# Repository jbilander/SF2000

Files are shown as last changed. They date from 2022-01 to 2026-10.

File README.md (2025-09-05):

# SF2000
Spitfire 2000, A low-end 42 MHz Amiga Accelerator based on the Motorola 68SEC000 CPU

***

This is WORK IN PROGRESS, a DIY hobby project. If you are going to make and sell boards you are also the one doing the customer support.

***

The firmware for this board is in a separate repository available here: <br />
https://github.com/jbilander/SF2000-FW
<br />

***

Revision 1B
<br />
<a href="images/SF2000_pic1.png">
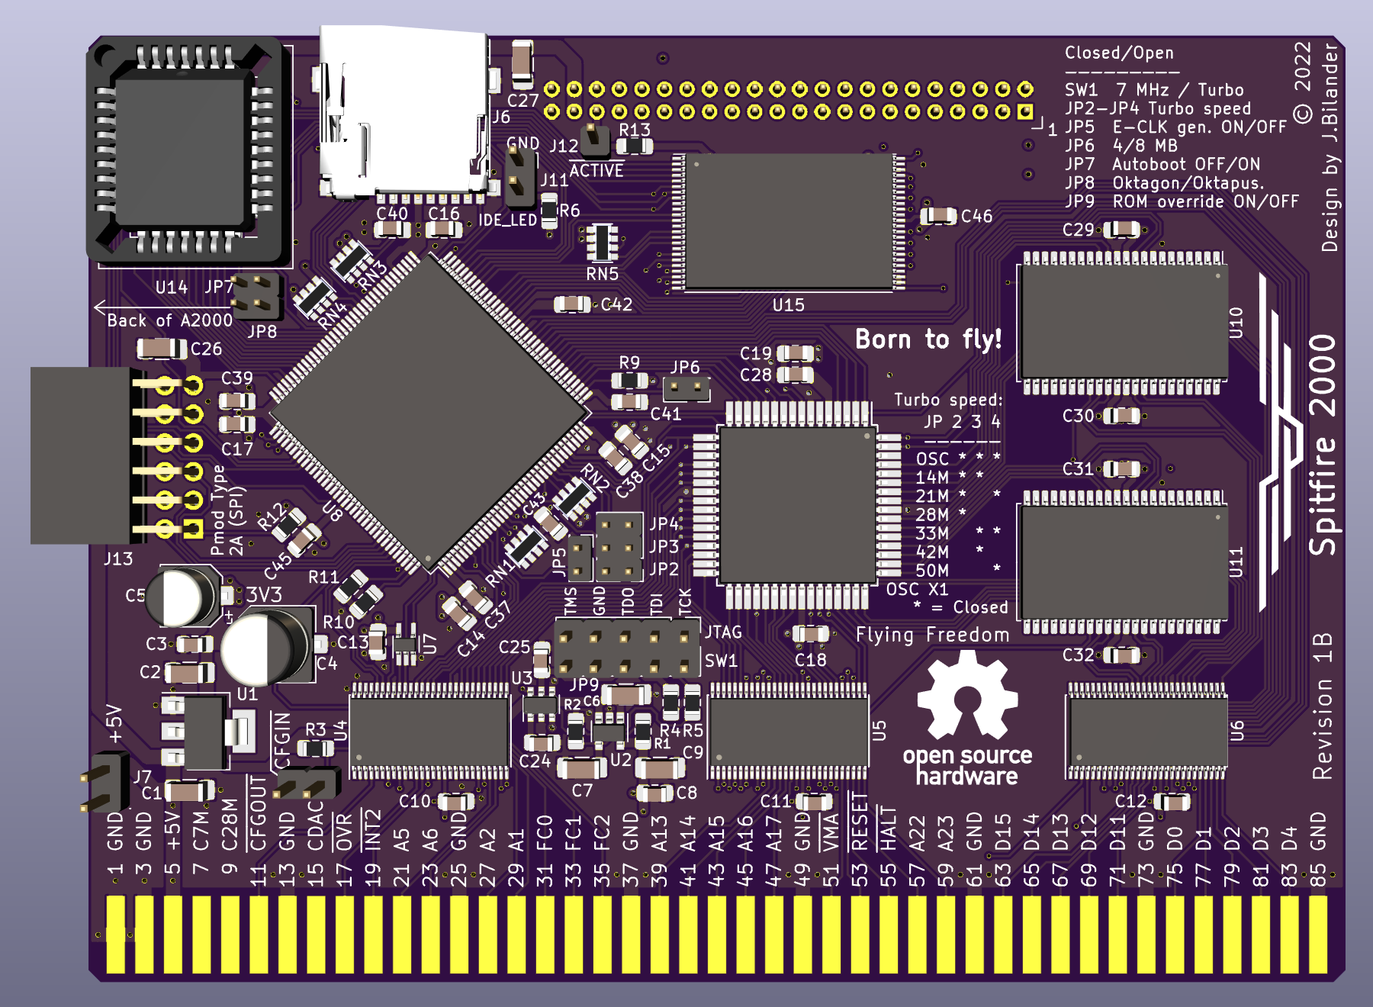
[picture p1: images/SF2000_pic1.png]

</a>
<a href="images/SF2000_pic2.png">
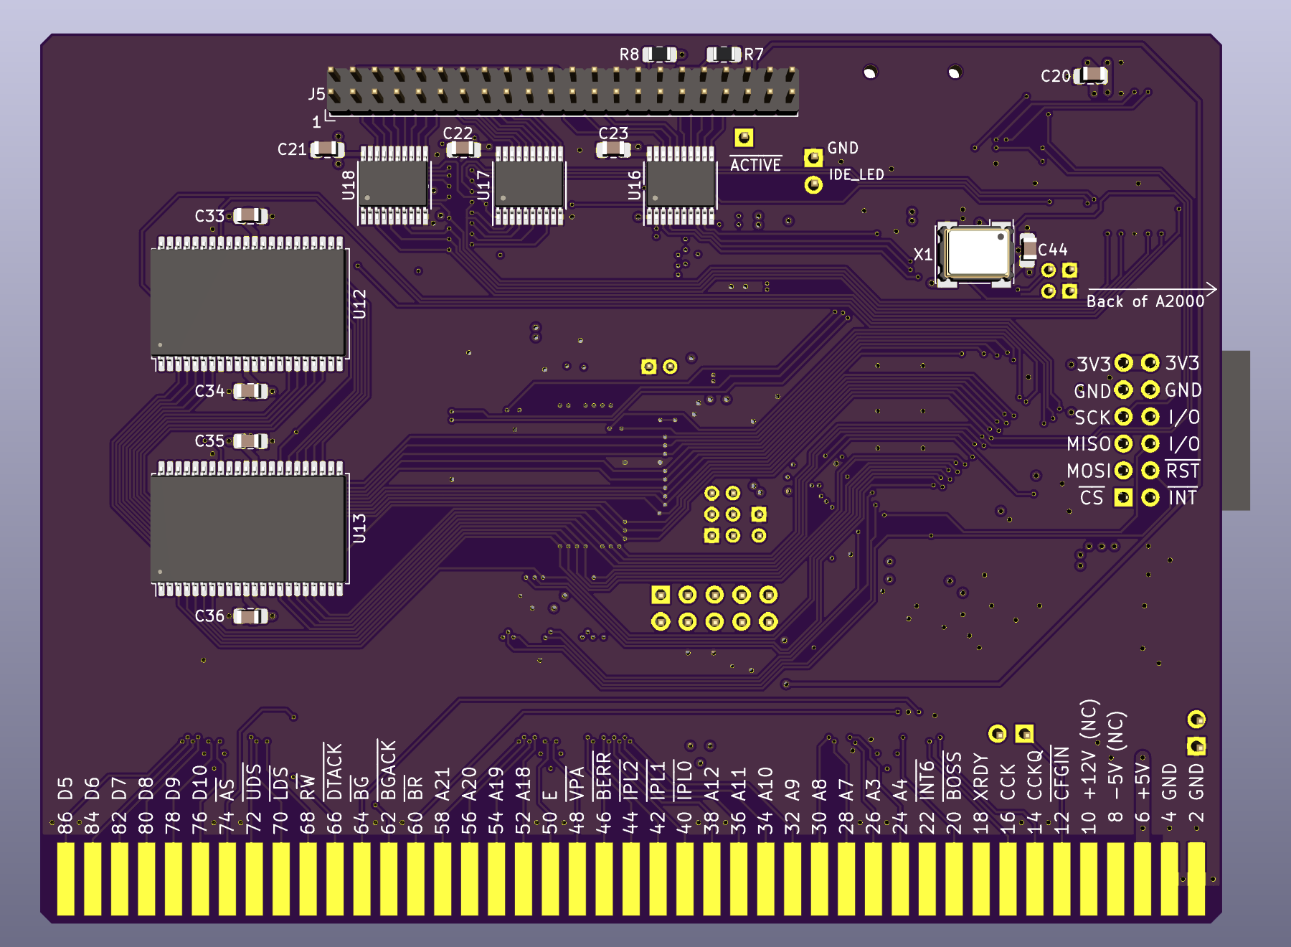
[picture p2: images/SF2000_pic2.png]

</a>

***

<a href="images/SF2000_pic3.jpg">
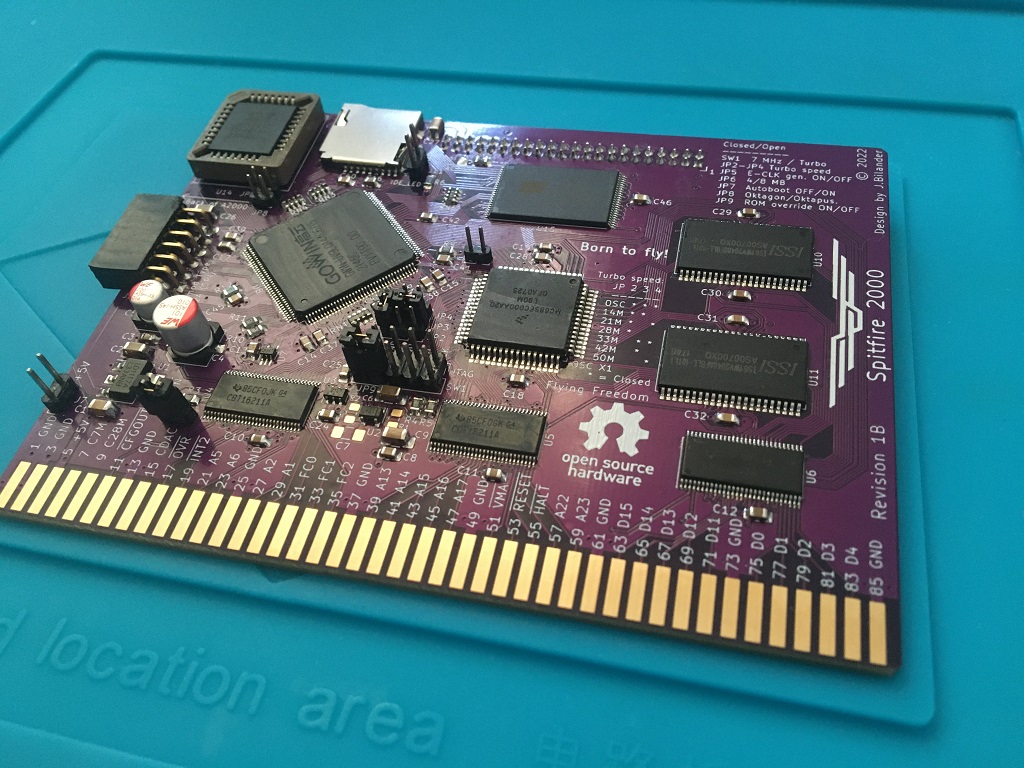
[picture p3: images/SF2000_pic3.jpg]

</a>
<a href="images/SF2000_pic4.jpg">
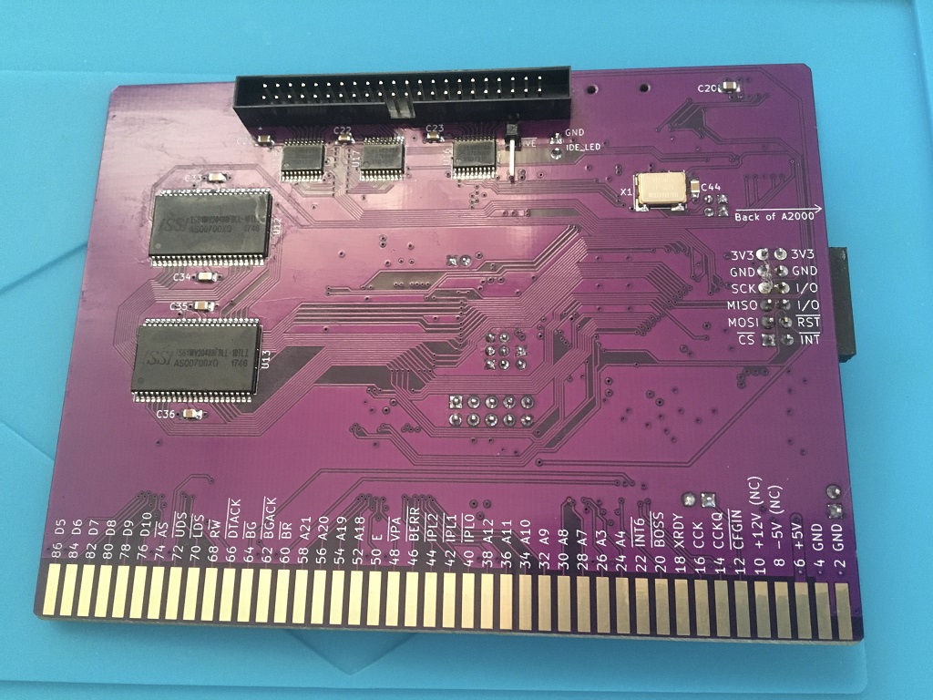
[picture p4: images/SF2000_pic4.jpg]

</a>

***

BOM Rev. 2B
---------
Designator  | Name/Value   | Package | Notes
-|-|-|-|
U1 | Voltage Regulator 3.3V, <br /> LM1117-3.3 or <br /> AMS1117-3.3 | SOT-223 | 3.3V 1A Low Drop-Out (LDO) Linear Voltage regulator
U2 | Voltage Regulator 4.3V, ABLIC S-1132B43-M5T1U or TPS73643DBVR | SOT-23-5 | 4.3V LDO Linear Voltage Regulator<br />[S-1132B43-M5T1U](https://www.digikey.com/en/products/detail/ablic-inc/S-1132B43-M5T1U/6112740)
U3 | Voltage Regulator 1.2V, TLV73312PDBVR | SOT-23-5 | 1.2V LDO Linear Voltage Regulator<br />[TLV73312PDBVR](https://www.digikey.com/en/products/detail/texas-instruments/TLV73312PDBVR/5022371)
U4,U5,U6 | Digital Bus Switch ICs 24-Bit FET, SN74CBT16211CDGGR or SN74CBT16811CDGGR | TSSOP-56 | FET Level-shifter <br />[SN74CBT16211CDGGR](https://www.digikey.com/en/products/detail/texas-instruments/SN74CBT16211CDGGR/864169) or <br />[SN74CBT16811CDGGR](https://www.digikey.com/en/products/detail/texas-instruments/sn74cbt16811cdggr/864186)
U7 | Dual XOR gate SN74LVC2G86DCUR | VSSOP-8_2.3x2mm_P0.5mm | Generates 7 MHz CLK from ~(CCK XOR CCKQ) <br />[SN74LVC2G86DCUR](https://www.digikey.com/en/products/detail/texas-instruments/sn74lvc2g86dcur/484697)
U8 | Efinix Trion T8 FPGA T8Q144C3 | LQFP-144_20x20mm_P0.5mm | FPGA - Field Programmable Gate Array, 7384 LE, 97 I/O <br />[T8Q144C3](https://www.digikey.com/en/products/detail/efinix-inc/t8q144c3/11591370)
U9 | W25Q16JVSNIQ 16 Mbit SPI NOR Flash memory | SOIC-8_3.9x4.9mm_P1.27mm (150-mil Narrow JEDEC SOIC) | [W25Q16JVSNIQ](https://www.digikey.com/en/products/detail/winbond-electronics/w25q16jvsniq/6193768) or [AT25SF161B-SSHD-T](https://www.digikey.com/en/products/detail/renesas-electronics-corporation/AT25SF161B-SSHD-T/14549318)
U10 | Motorola CPU MC68SEC000AA20 20MHz | QFP-64_14x14mm_Pitch0.8mm | [MC68SEC000AA20](https://shop.tvsat.com.pl/en_GB/searchquery/68sec000/1/phot/5?url=68sec000)
U11 | SST39LF802C-55-4C-EKE or SST39LF800A-55-4C-EKE | TSOP-I-48_18.4x12mm_P0.5mm | NOR Flash 3.0 to 3.6V 8Mbit Multi-Purpose Flash (for Kickstart) <br />[S39LF802C554CEKE](https://www.mouser.com/ProductDetail/579-S39LF802C554CEKE)<br />[S39LF800A554CEKE](https://www.digikey.com/en/products/detail/microchip-technology/SST39LF800A-55-4C-EKE/2297824)
U12 | 74AHCT14PW, Six Channel Schmitt Trigger Inverter | TSSOP-14_4.4x5mm_P0.65mm | [74AHCT14PW,118](https://www.digikey.com/en/products/detail/nexperia-usa-inc/74AHCT14PW-118/1229627) or <br />[SN74AHCT14PWR](https://www.digikey.com/en/products/detail/texas-instruments/SN74AHCT14PWR/276754)
U13 | NOR Flash SST39LF040-55-4C-NHE-T | PLCC-32 | NOR Flash 3.0 to 3.6V <br />[SST39LF040554CN](https://www.digikey.com/en/products/detail/microchip-technology/sst39lf040-55-4c-nhe-t/4080132) <br /> (or 39LF020, 39LF010)
U14,U15 | SRAM ISSI IS61WV20488FBLL-10TLI  | TSOP-44 | First 4 MB SRAM <br />High-Speed, Async, 2Mbx8, 10ns, 2.4v-3.6v, 44 Pin TSOP II, RoHS <br />[IS61WV20488FBLL-10TLI](https://www.mouser.com/ProductDetail/870-61W20488FBLL10TI)
U16,U17 | SRAM ISSI IS61WV20488FBLL-10TLI  | TSOP-44 | Second 4 MB (Optional) --"-- <br />
J1 | Goldfingers on PCB | ENIG | Order PCB with Goldfingers, ENIG and 45 degrees chamfered edge (or chamfer the edge yourself with a file)
J2 | CFGIN-header Two-Pin Header | 2.54mm pitch | Put a Jumper shunt here to activate autoconfig, or a CONFIGOUT-wire from other device to the right (pin 2) in this header.  
J3 | JTAG-header   | Dual row 2.54mm (2 x 5) Pin Male Header | 
J4 | JP-header JP2 | 2.00mm (2 x 1) Pin Male Header | Generate E-CLK (if internal 68k is removed from socket)
J5 | JP-header JP3 | 2.00mm (2 x 1) Pin Male Header | Rom overlay jumper
J6 | JP-header JP4 | 2.00mm (2 x 1) Pin Male Header | 4/8 MB SRAM Config
J7 | VCC/GND Two-Pin Header | 2.54mm pitch | VIN +5V <br /> used when programming FPGA standalone (card not installed in the Amiga). Be careful with orientation, check polarity BEFORE plugging-in a phone charger or similar here.
J8 | Sunrom Micro SD Card Holder | 9-pin Micro SD card slot connector | [Sunrom Micro-SD card holder](https://www.aliexpress.com/item/32802051702.html)
J9 | SD_LED header, Two-Pin Header | 2.54mm pitch | Driven by U12 inverter buffer when /SD_CS is being asserted. Connect to here in order to drive an external HDD-LED
J10 | SD_ACTIVE low signal, Right angle Single-Pin Header | 0.64 mm square pin angled | Driven by U12 inverter buffer when /SD_CS is being asserted. Connect to here in order to drive a [LED-board](https://github.com/jbilander/A500_IDE_LED_board) (Active low +5V-signal)
J11 | Rom-bank selector | 2.00mm (2 x 1) Pin Male Header | Select first or second bank, address line A15 (pin 3) on U13 (SST39LF040)
J12 | CLOCKPORT-header | 2.00mm 22-Pin (2x11) Pin Male Header | Caution: This header is +5V levels. Be careful with orientation.
J13 | JP-header JP1 | 2.54mm (2 x 1) Pin Male Header | 7 MHz / Turbo selector
X1 | Crystal Oscillator 20 MHz | Oscillator_7.0x5.0mm |
R1 | 33 Ω Resistor | 0805 | Damping resistor for 20 MHz clock-signal coming from X1 oscillator
R2 | 33 Ω Resistor | 0805 | Damping resistor for 7 MHz clock-signal coming from U7 (SN74LVC2G86DCUR)
R3 | 33 Ω Resistor | 0805 | Damping resistor for CLKCPU clock-signal coming from FPGA pin 33
R4 | ~220 Ω Resistor | 0805 | Series resistor for SD_LED header J9, adjust R-value to your type of LED and preferred brightness
R5 | 10k Ω Resistor | 0805 | Pull-up resistor for /FLASH_OE to 3V3
R6 | 10k Ω Resistor | 0805 | Pull-up resistor for JP2 to 3V3
R7 | 10k Ω Resistor | 0805 | Pull-up resistor for /CFGIN to 5V
R8 | 100k Ω Resistor | 0805 | Pull-up resistor for CRESET_N to 3V3
RN1-RN6 | Resistor pack 10k Ω (CAY16-103J4LF) | 1206 | [CAY16-103J4LF](https://www.digikey.com/en/products/detail/bourns-inc/cay16-103j4lf/431579)
C1 | Polarized Electrolytic Capacitor 100uF | CP_Elec_6.3x7.7 mm | [Wurth SMD WCAP-AS5H 100uF](https://www.digikey.com/en/products/detail/w%C3%BCrth-elektronik/865230245004/5727885)
C2 | Polarized Electrolytic Capacitor 22uF | CP_Elec_5x5.8 mm | [Wurth SMD WCAP-AS5H 22uF](https://www.digikey.com/en/products/detail/w%C3%BCrth-elektronik/865230342002/5727846)
C3-C7 | Ceramic Capacitor 10uF | 1206 |
C8 | Ceramic Capacitor 2.2uF | 1206 |
C9 | Ceramic Capacitor 0.47uF = 470 nF | 1206 |
C10-C39 | Ceramic Capacitor 0.1uF = 100nF | 0805 | 
C40-C54 | Capacitor 0.01uF = 10nF | 0805 |

***

BOM Rev. 1B
---------
Designator  | Name/Value   | Package | Notes
-|-|-|-|
U1 | Voltage Regulator 3.3V, <br /> LM1117-3.3 or <br /> AMS1117-3.3 | SOT-223 | 3.3V 1A Low Drop-Out (LDO) Voltage regulator. https://www.aliexpress.com/item/32869037691.html
U2 | Voltage Regulator 4.3V, TPS73643DBVR or <br /> ABLIC S-1200B43-M5T1U or <br /> MIC5205YM5-TR ADJ (with R1,R2 and C7 populated) | SOT-23-5 | 4.3V LDO Voltage Regulator<br />* [TPS73643DBVR](https://www.mouser.com/ProductDetail/595-TPS73643DBVR) <br />* [S-1132B43-M5T1U](https://www.mouser.com/ProductDetail/628-S-1132B43-M5T1G) <br />* [MIC5205YM5-TR](https://www.mouser.com/ProductDetail/Microchip-Technology-Atmel/MIC5205YM5-TR?qs=U6T8BxXiZAUCsfGqlmZYIw%3D%3D) (Adjustable, populate R1,R2,C7)
U3 | Inverter Schmitt Trigger 74LVC2G14GV,125 | TSOP-6/SOT457/SC-74 | * [LVC2G14GV125](https://www.mouser.com/ProductDetail/771-LVC2G14GV125)
U4,U5,U6 | Digital Bus Switch ICs 24-Bit FET, SN74CBT16211ADGGR | TSSOP-56 | FET Level-shifter <br /> * [SN74CBT16211ADGGR](https://www.mouser.com/ProductDetail/595-SNCBT16211ADGGR) <br /> * [SN74CBT16811CDGG](https://www.mouser.com/ProductDetail/595-SN74CBT16811CDGG)
U7 | XNOR gate w/ Schmitt Trigger SN74AUP1T87DCKR |TSSOP-5/SC-70-5/SOT-353-1 | Generates 7 MHz CLK from CCK XNOR CCKQ <br /> * [SN74AUP1T87DCKR](https://www.mouser.com/ProductDetail/595-SN74AUP1T87DCKR)
U8 | Gowin FPGA GW1N-UV9LQ144C6/I5 | LQFP-144 | FPGA - Field Programmable Gate Array, 8640 LE, 120 I/O <br /> * [GW1N-UV9LQ144C6/I5](https://www.mouser.com/ProductDetail/192-GW1NUV9LQ144C6I5)
U9 | Motorola CPU MC68SEC000AA20 | QFP-64 | MPU 32-bit 20MHz <br /> Contact Eriond to buy a NOS CPU for a reasonable price
U10,U11 | SRAM ISSI IS61WV20488FBLL-10TLI  | TSOP-44 | First 4 MB SRAM <br />High-Speed, Async, 2Mbx8, 10ns, 2.4v-3.6v, 44 Pin TSOP II, RoHS <br /> * [61W20488FBLL10TI](https://eu.mouser.com/ProductDetail/870-61W20488FBLL10TI)
U12,U13 | SRAM ISSI IS61WV20488FBLL-10TLI  | TSOP-44 | Second 4 MB (Optional) --"-- <br />
U14 | NOR Flash SST39LF040-55-4C-NHE-T | PLCC-32 | NOR Flash 3.0 to 3.6V (For Oktagon/Oktapus. IDE-driver) <br /> * [SST39LF040554CN](https://www.mouser.com/ProductDetail/579-SST39LF040554CN) <br /> (or 39LF020, 39LF010)
U15 | SST39LF802C-55-4C-EKE | TSOP-48 | NOR Flash 3.0 to 3.6V 8Mbit Multi-Purpose Flash (for Kickstart) <br /> * [S39LF802C554CEKE](https://www.mouser.com/ProductDetail/579-S39LF802C554CEKE)
U16,U17,U18 | Bus Transceiver 74LVC245APW,118  | TSSOP-20 | * [74LVC245APW-T](https://www.mouser.com/ProductDetail/771-74LVC245APW-T)
J1 | Goldfingers on PCB | ENIG | Order PCB with Goldfingers, ENIG and 45 degrees chamfered edge (or chamfer the edge yourself)
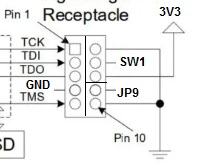
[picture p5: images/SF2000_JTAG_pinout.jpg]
J2 | JTAG-header | Dual row 2.54mm (2 x 5) Pin Male Header Strip | 
J3 | JP-header JP2,JP3,JP4 | Dual row 2.00mm (2 x 3) Pin Male Header Strip | Turbo speed selector
J4 | JP-header JP5 | 2.00mm (2 x 1) Pin Male Header | Generate E-CLK (if internal 68k is removed from socket)
J5 | IDE/ATA-header | 2.00mm 44-Pin (2x22 Pin) Straight Male Shrouded PCB Box header IDC Socket | For A2000: <br /> * [Shrouded header](https://www.aliexpress.com/item/1720053014.html) <br />For A500 internal mount a right angled female header can be used (2x25 and cut down to 2x22): <br /> * [Right Angle Female Connector](https://www.aliexpress.com/item/4001286548060.html)
J6 | Sunrom Micro SD Card Holder | 9-pin Micro SD card slot connector | * [Sunrom Micro-SD card holder](https://www.aliexpress.com/item/32802051702.html)
J7 | VCC/GND Two-Pin Header 2.54mm pitch | 2.54mm pitch | VIN +5V <br /> used when programming FPGA standalone (card not installed in the Amiga). Be careful with orientation, check polarity BEFORE plugging-in a phone charger or similar here.
J8 | JP-header JP6 | 2.00mm (2 x 1) Pin Male Header | 4/8 MB SRAM Config
J9,J10 | JP-header JP7,JP8 | 2.00mm (2 x 2) Pin Male Header | JP7 Autoboot IDE OFF/ON Selector, JP8 Oktagon/Oktapus. IDE-driver Selector
J11 | LED Two-Pin Header 2.54mm pitch | 2.54mm pitch | Driven by U3 inverter buffer when /Active on IDE is being asserted. Connect to here to drive an external HDD-LED
J12 | /Active signal, Single-Pin Header 2.54mm | 2.54mm pitch | /Active signal from IDE. Connect from here to a <br /> * [LED-board](https://github.com/jbilander/A500_IDE_LED_board) 
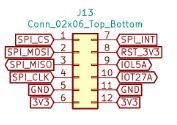
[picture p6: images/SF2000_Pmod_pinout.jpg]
J13 | Pmod Type 2A (SPI) Female header, 12-Pin (2x6) | 2.54mm pitch |  For connecting SPI peripherals. <br /> * [Right-Angled](https://www.aliexpress.com/item/1005003223096006.html) (A2000) or <br /> * [Straight](https://www.aliexpress.com/item/1005003335405213.html) (A500) to not interfere with [RGBtoHDMI-adapter](https://github.com/jbilander/A500_RGBtoHDMI) inside A500
R1 | 1.2k Ω Resistor | 0805 | Feedback resistor, Only populate if U2 is of ADJ-ustable type (e.g. MIC5205YM5-TR)
R2 | 3k Ω Resistor | 0805 | Feedback resistor, Only populate if U2 is of ADJ-ustable type (e.g. MIC5205YM5-TR)
R3 | 10k Ω Resistor | 0805 | Pull-up resistor for /CFGIN (5V-side)
R4 | 10k Ω Resistor | 0805 | Pull-up resistor in RC-debounce circuit
R5 | 10k Ω Resistor | 0805 | Series resistor in RC-debounce circuit
R6 | ~220 Ω Resistor | 0805, 200 mW | Series resistor for IDE-LED header J11, adjust R-value to your type of LED and preferred brightness
R7 | 1k Ω Resistor | 0805 | Pull-down resistor for IDE_IRQ
R8 | 4.7k Ω Resistor | 0805 | Pull-up resistor for IDE_IORDY
R9 | 10k Ω Resistor | 0805 | Pull-up resistor for JP6
R10 | 1k Ω Resistor | 0805 | Pull-down resistor for MODE0 (Gowin FPGA boot/configure from embFlash)
R11 | 1k Ω Resistor | 0805 | Pull-down resistor for MODE1 (Gowin FPGA boot/configure from embFlash)
R12 | 10k Ω Resistor | 0805 | Pull-up resistor for RECONFIG_N (Gowin FPGA) and /SPI_CS (in J13 Pmod-header)
R13 | 10k Ω Resistor | 0805 | Pull-up resistor for /ACTIVE (IDE)
RN1-RN2,RN5 | Resistor pack 10k Ω (CAY16-103J4LF) | 1206 | * [CAY16-103J4LF](https://www.mouser.com/ProductDetail/652-CAY16-103J4LF) Pull-up resistors.
RN3-RN4 | Resistor pack 10k Ω (CAY16-103J4LF) or 4.7k (CAY16-4701F4LF) | 1206 | * [CAY16-4701F4LF](https://www.mouser.com/ProductDetail/652-CAY16A-4701F4LF) Pull-up resistors for SD0-SD3,SD_CD,SD_CMD,JP7,JP8
C1-C2 | Capacitor 10uF | 1206 |
C3 | Capacitor 0.1uF = 100nF | 0805 |
C4 | Polarized Capacitor 100uF | CP_Elec_6.3x7.7 | * [Wurth SMD WCAP-AS5H 100uF](https://www.mouser.com/ProductDetail/710-865230245004)
C5 | Polarized Capacitor 22uF | CP_Elec_5x5.8 | * [Wurth SMD WCAP-AS5H 22uF](https://www.mouser.com/ProductDetail/710-865230342002)
C6 | Capacitor 10uF to 0.22uF | 1206 | Check datasheet for U2 what is suitable here.
C7 | Capacitor 0.33uF = 330nF | 1206 | (Not needed if U2 is TPS73643DBVR, check your U2-datasheet)
C8 | Capacitor 10uF | 1206 |
C9-C25 | Capacitor 0.1uF = 100nF | 0805 | C24 capacitor in RC-debounce circuit
C26-C27 | Capacitor 10uF | 1206 |
C28-C46 | Capacitor 0.01uF = 10nF | 0805 |

***

A SF2000 shared shopping cart with most of the stuff in the list, no 3V3-regulator though and not all birdseed (passives):
https://www.mouser.com/ProjectManager/ProjectDetail.aspx?AccessID=fdb374e26b

***

The FPGA used in this Accelerator board, please note it has to be the Voltage `UV` version because of 3.3V is being used for all VCC/VCCIO on the Accelerator:
<br />
<a href="images/SF2000_FPGA_GW1N-UV9LQ144.png">
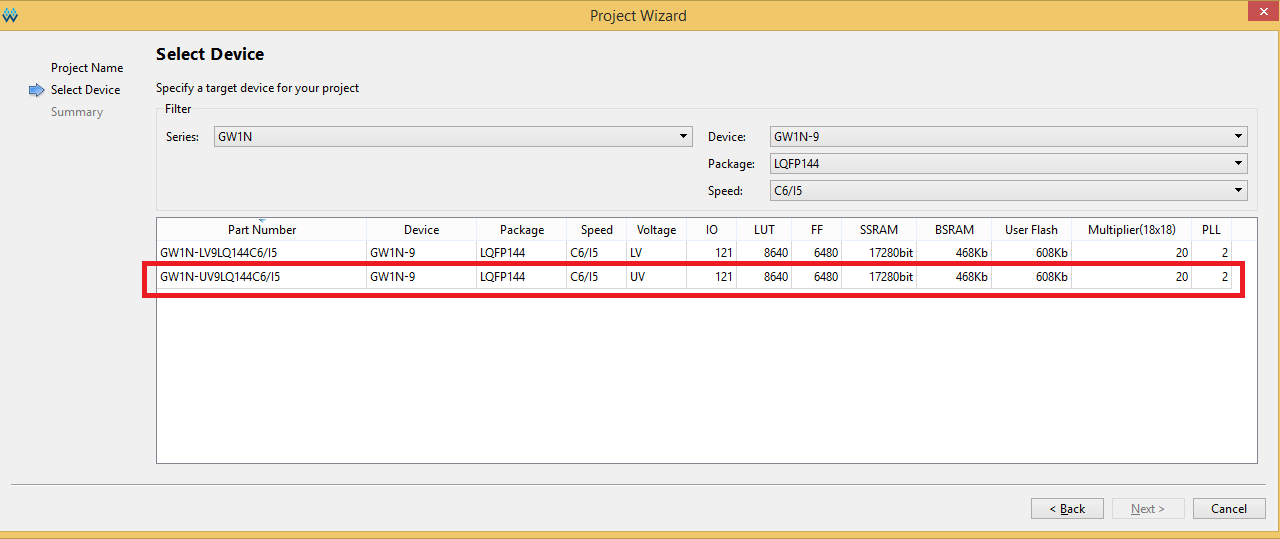
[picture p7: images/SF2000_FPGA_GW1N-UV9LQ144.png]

</a>

***

### Ordering details (JLCPCB):

<a href="images/SF2000_JLCPCB_ordering_pic1.png">
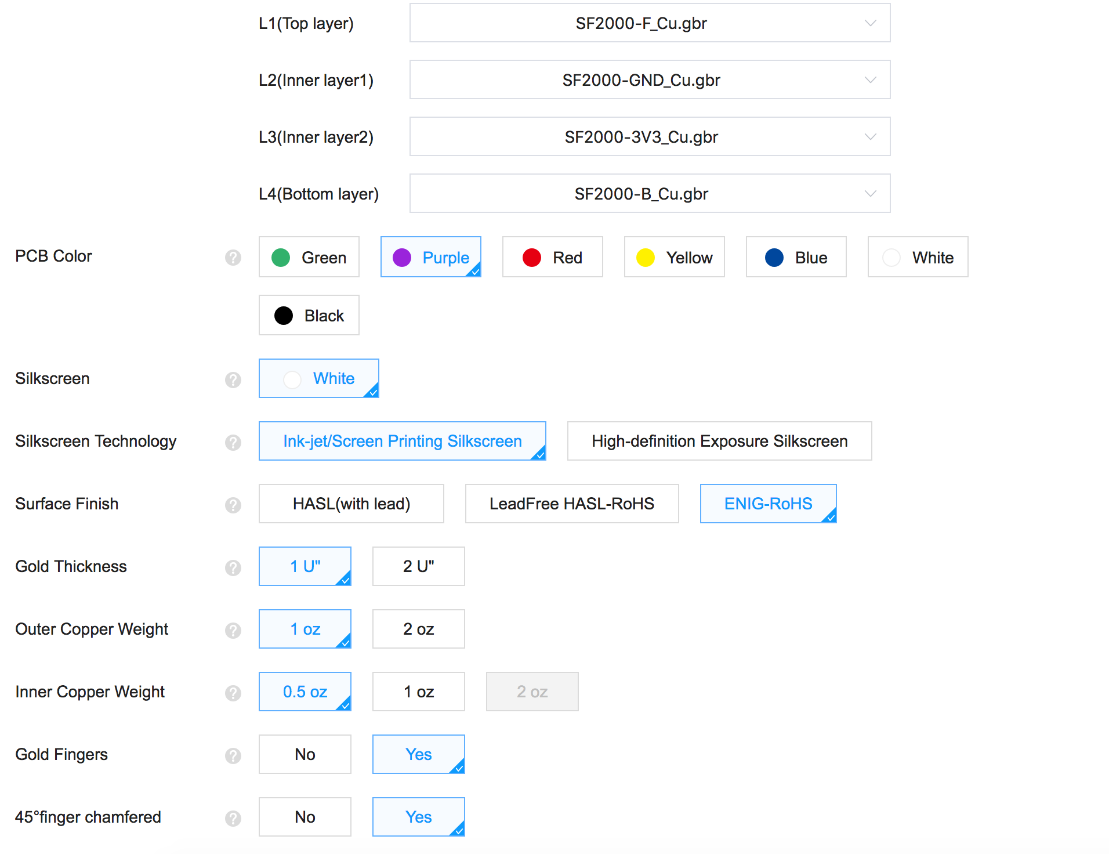
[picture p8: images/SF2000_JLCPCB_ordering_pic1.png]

</a>
<br />
<a href="images/SF2000_JLCPCB_ordering_pic2.png">
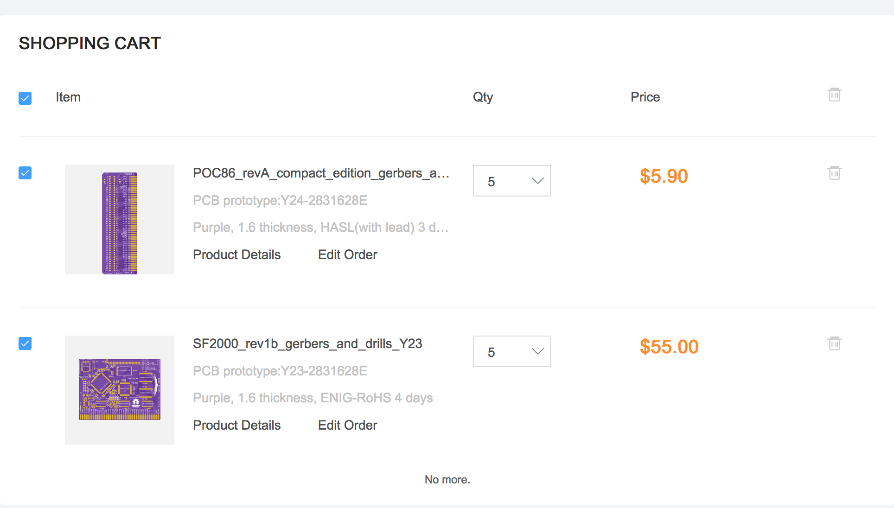
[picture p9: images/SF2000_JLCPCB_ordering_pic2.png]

</a>
<a href="images/SF2000_pic5.png">
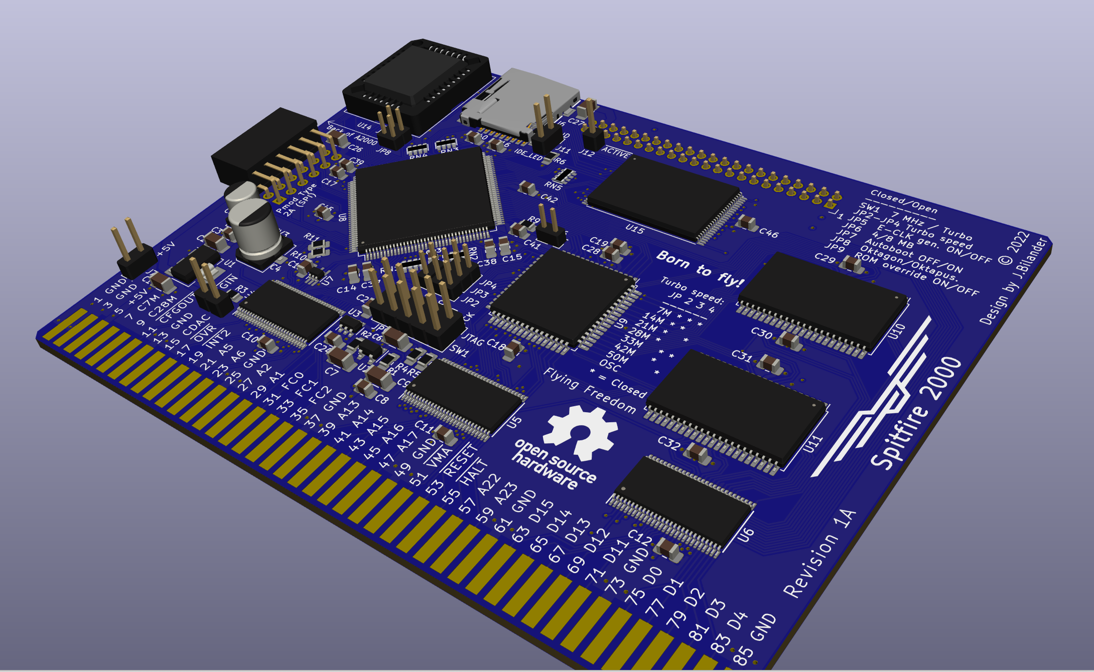
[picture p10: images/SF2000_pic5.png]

</a>

***
### MC68SEC000 

The SF2000 is based on the MC68SEC000 CPU <br />
https://www.nxp.com/docs/en/product-brief/MC68SEC000.pdf <br />
<a href="images/SF2000_pic6.jpg">
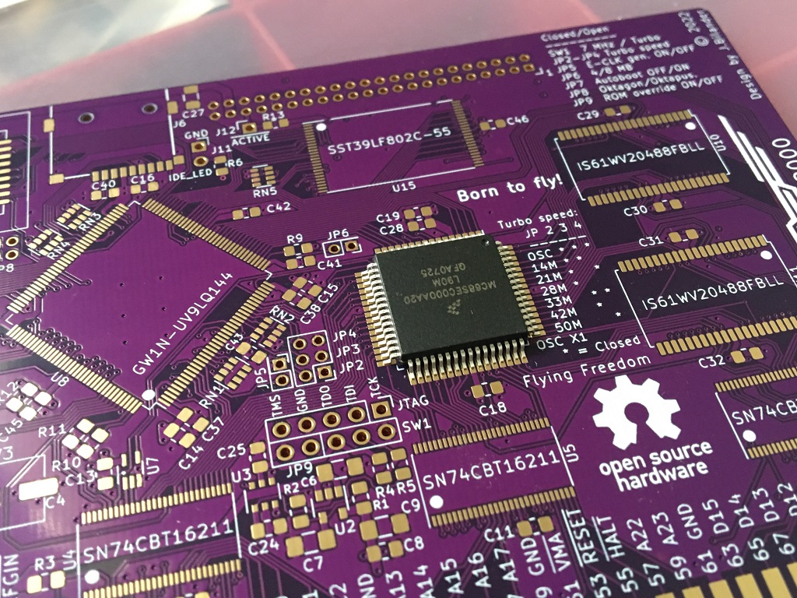
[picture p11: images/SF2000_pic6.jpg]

</a>
<br />
You can contact Eriond, https://github.com/eriond (over at A314 or Retro Tinkering or SUGA (Swedish User Group Amiga) discord) to buy a NOS MC68SEC000 at a reasonable price.

***

### Installing in A500 or A2000:

Internal A500 installation with this adapter: <br />
https://github.com/jbilander/A500_Edge_Expansion_adapter
<br />
<a href="images/SF2000_pic7.jpg">
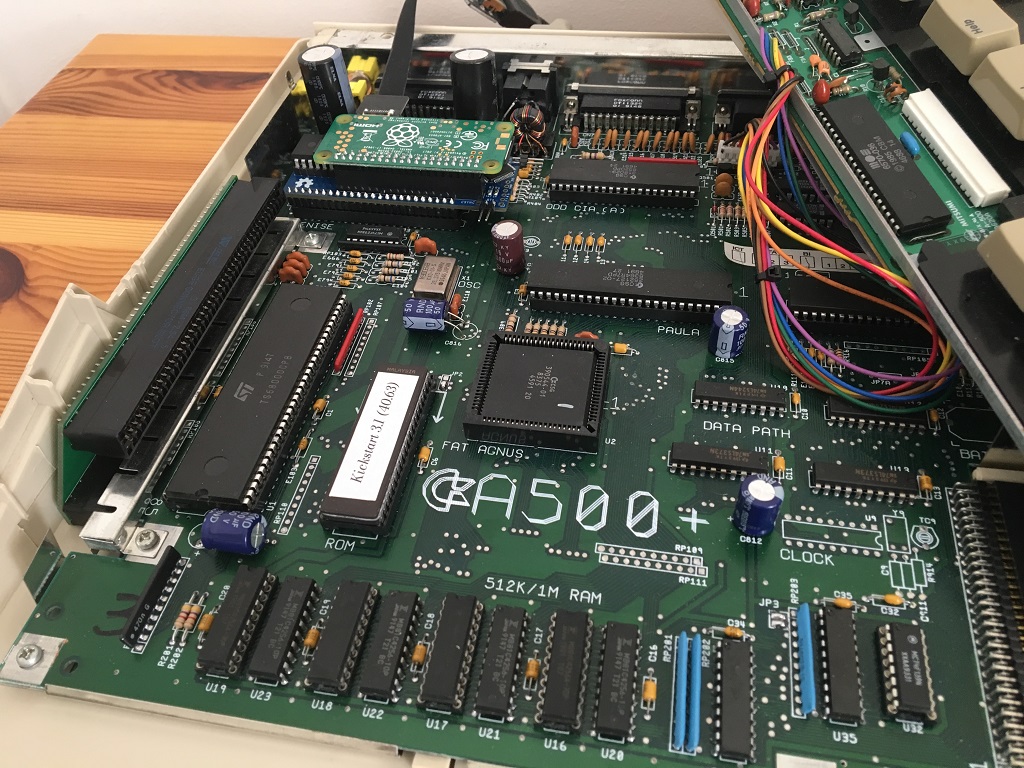
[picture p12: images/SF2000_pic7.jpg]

</a>
<br />
<a href="images/SF2000_pic8.jpg">
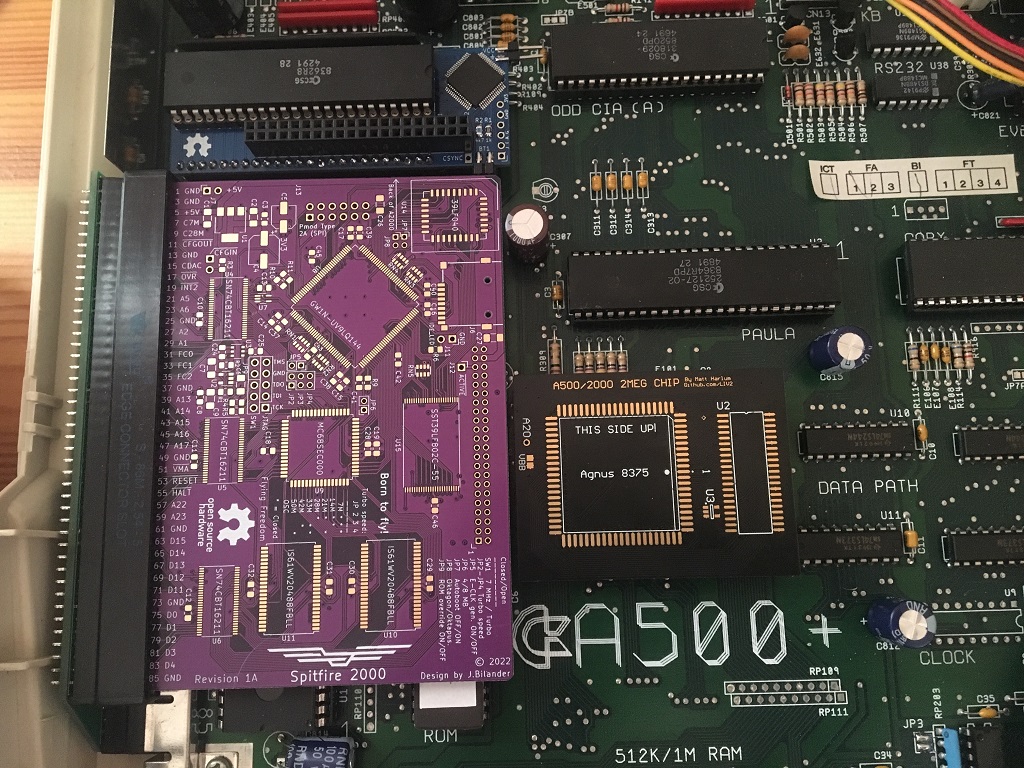
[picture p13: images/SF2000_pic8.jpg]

</a>
<a href="images/SF2000_pic9.jpg">
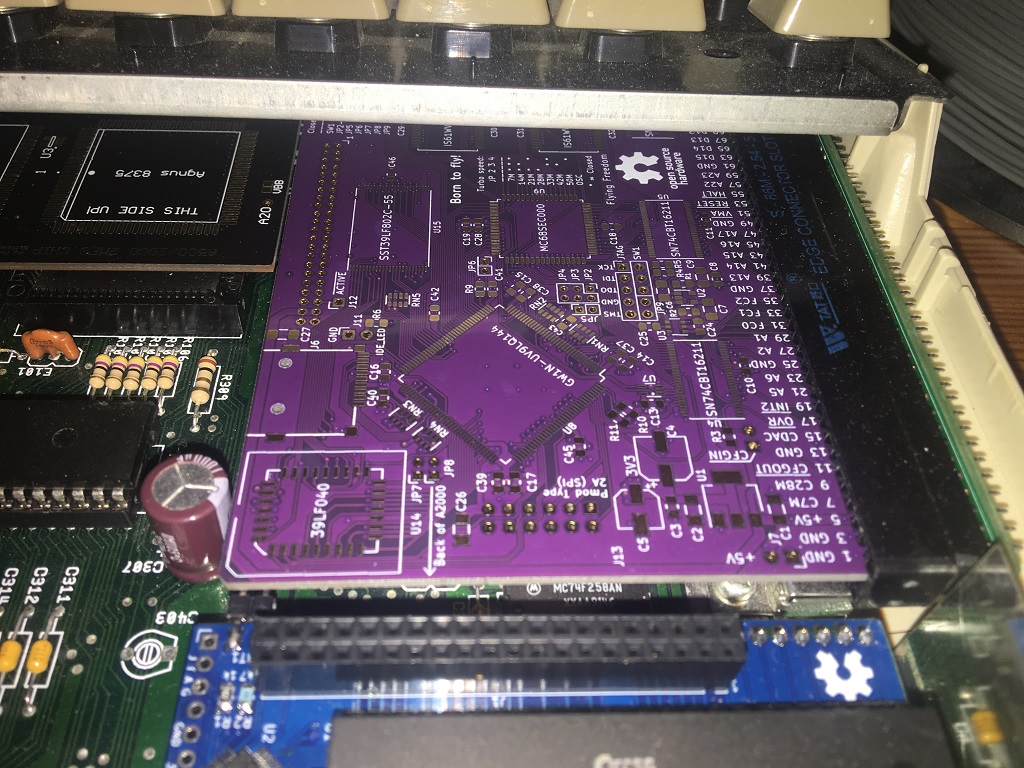
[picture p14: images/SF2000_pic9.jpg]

</a>
<br />
<a href="images/SF2000_pic10.jpg">
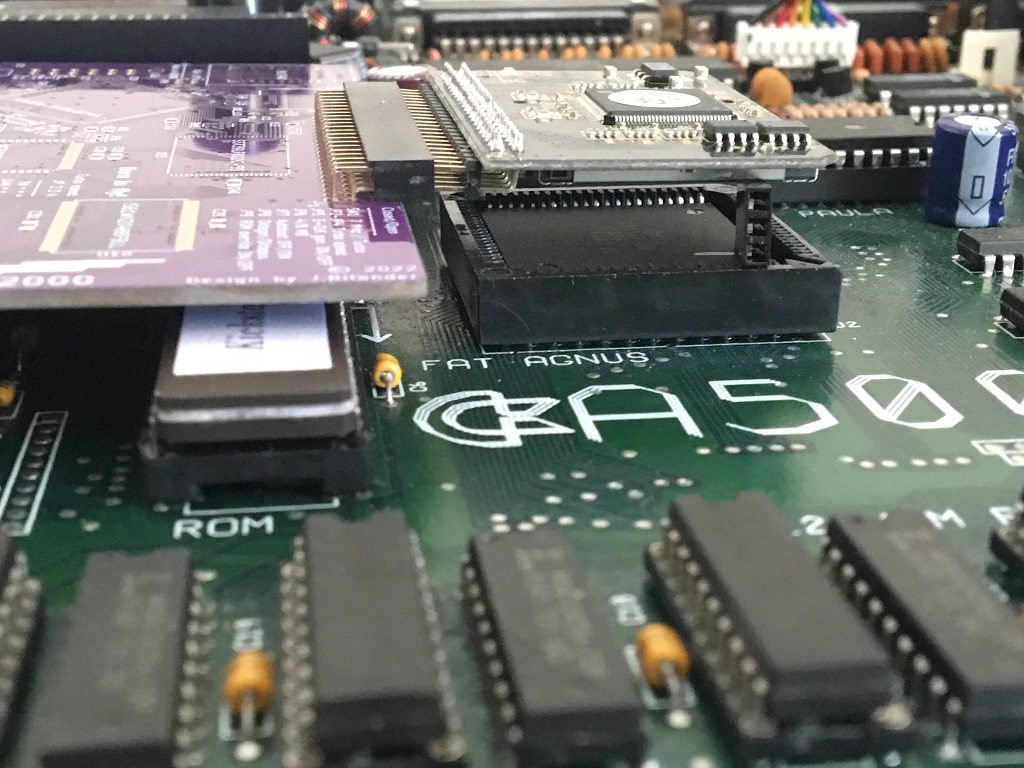
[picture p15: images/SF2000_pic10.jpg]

</a>
<a href="images/SF2000_pic11.jpg">
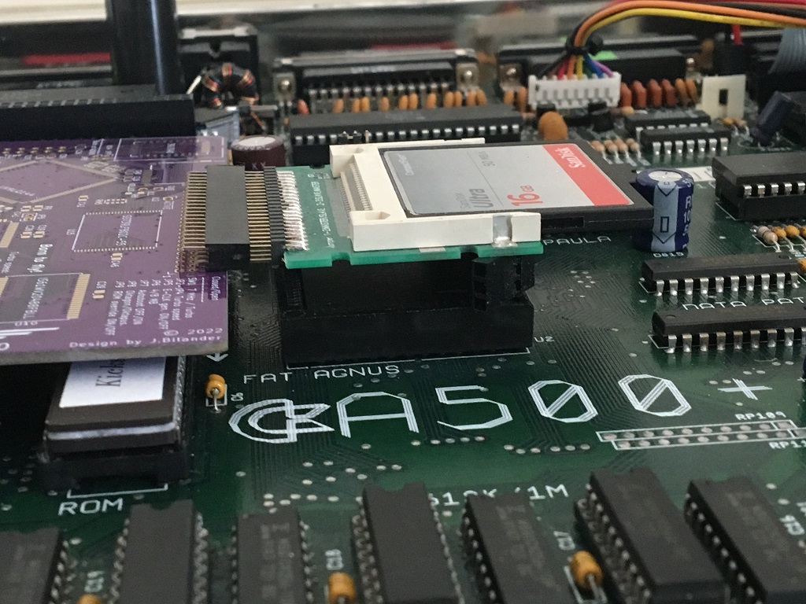
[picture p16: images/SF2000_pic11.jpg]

</a>

External A500 installation with this adapter: <br />
https://github.com/jbilander/POC86
<br />
<a href="images/SF2000_pic12.jpg">
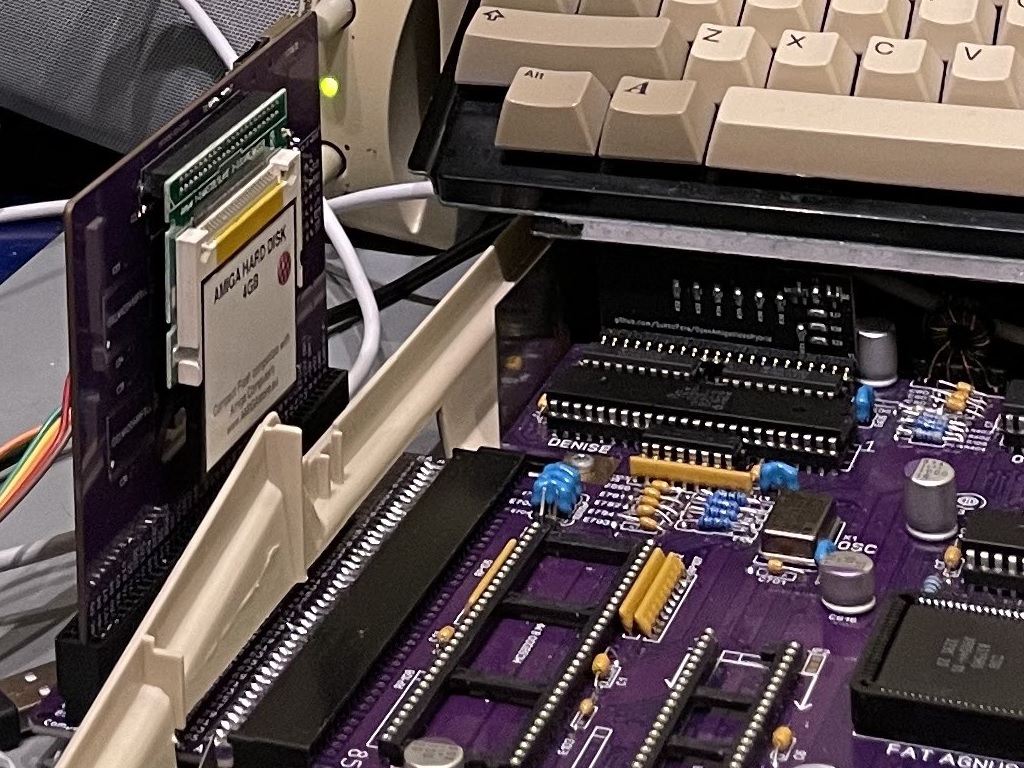
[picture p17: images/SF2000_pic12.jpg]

</a>
<br />
<a href="images/SF2000_pic14.jpg">
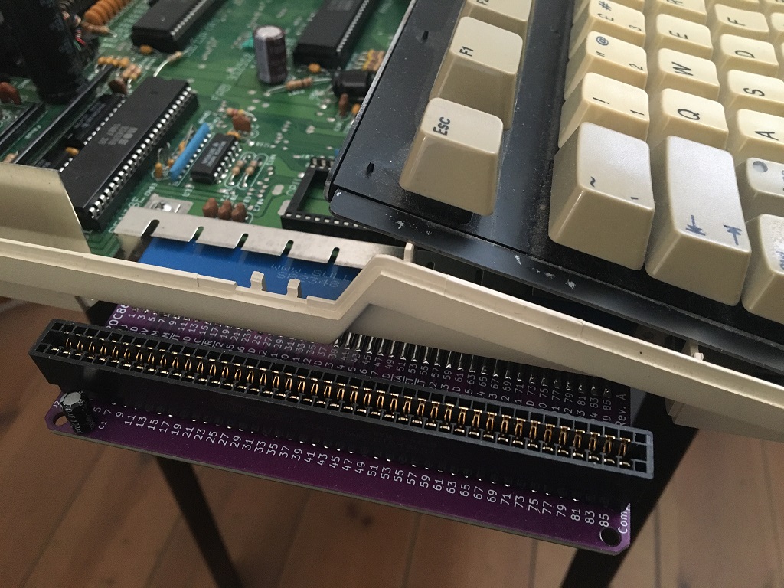
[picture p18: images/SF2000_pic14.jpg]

</a>
<br />
<a href="images/SF2000_pic15.jpg">
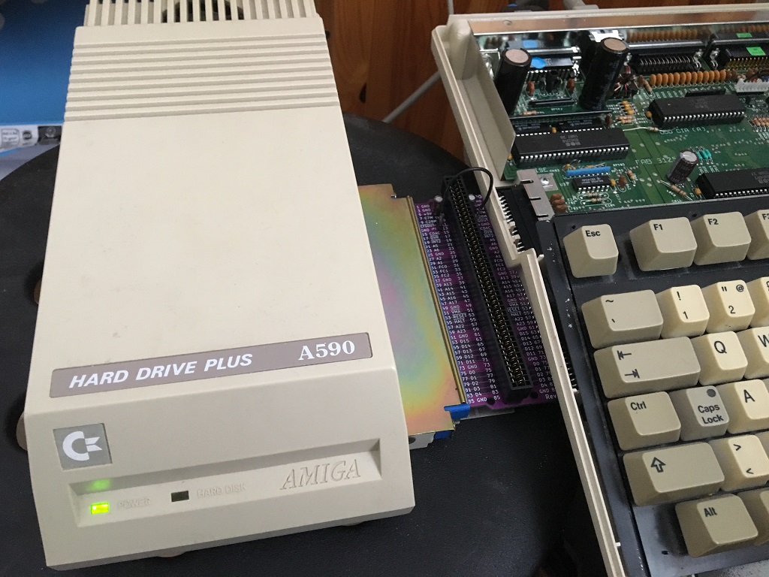
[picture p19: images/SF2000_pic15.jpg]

</a>
<a href="images/SF2000_pic16.jpg">
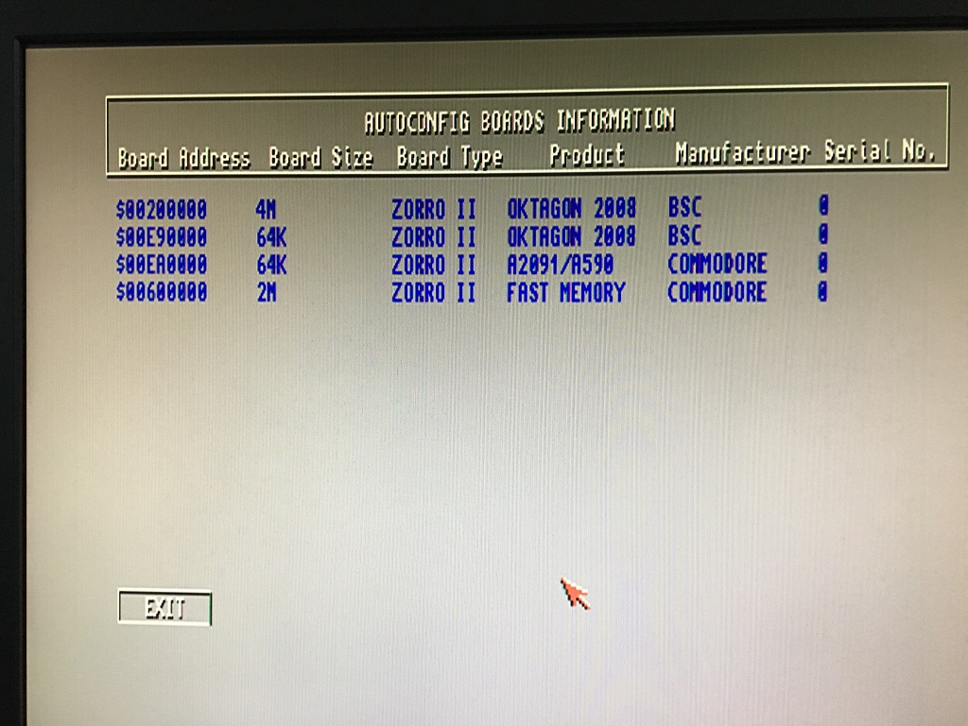
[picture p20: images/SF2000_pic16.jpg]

</a>

### A2000 Co-pro slot:<br />
<a href="images/SF2000_pic13.jpg">
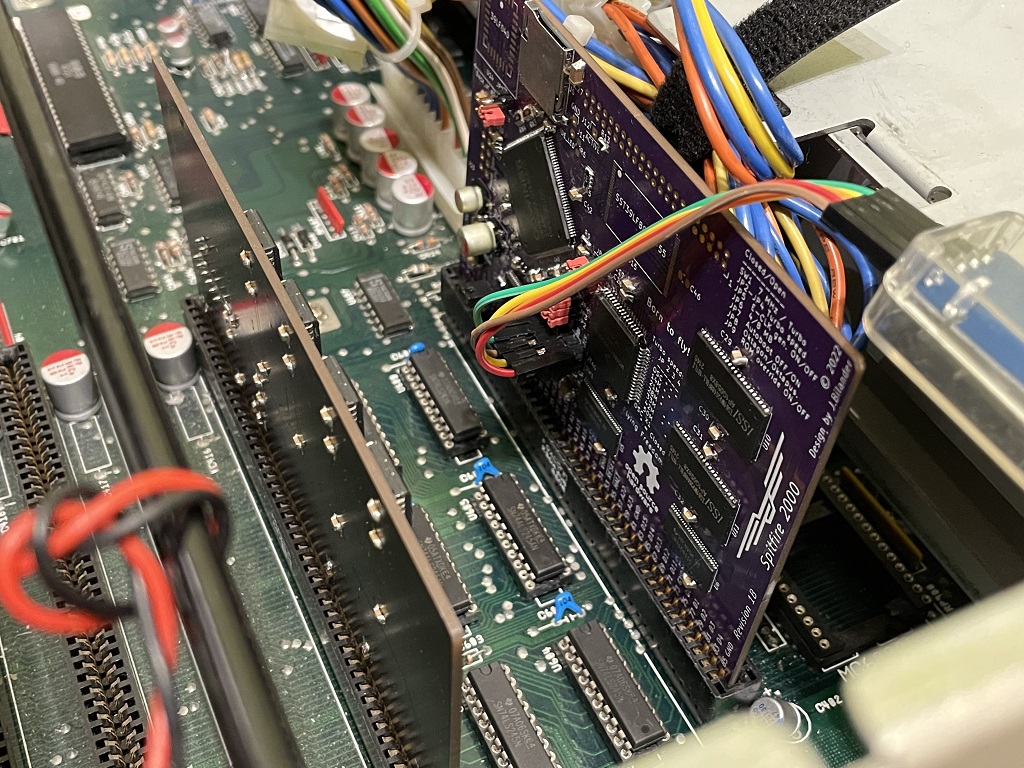
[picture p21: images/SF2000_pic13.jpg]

</a>

***

### Building

Follow the dots to get the correct orientation of the chips when soldering, don't rely on the silkscreen text.
<br />
<a href="images/SF2000_pic17.jpg">
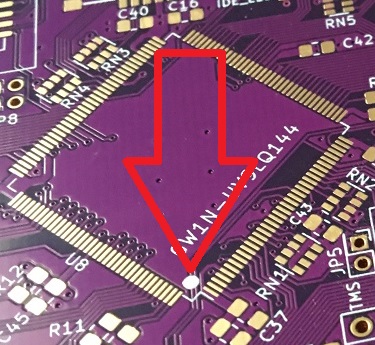
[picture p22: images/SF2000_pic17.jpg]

</a>
<br />
You can solder the 3V3 LDO and the FPGA first and then check that you can communicate via JTAG programming a simple LED-blink example or similar. +5V you can take from a USB phone-charger or similar, check polarity before you plug it in.
<br />
<a href="images/SF2000_pic18.jpg">
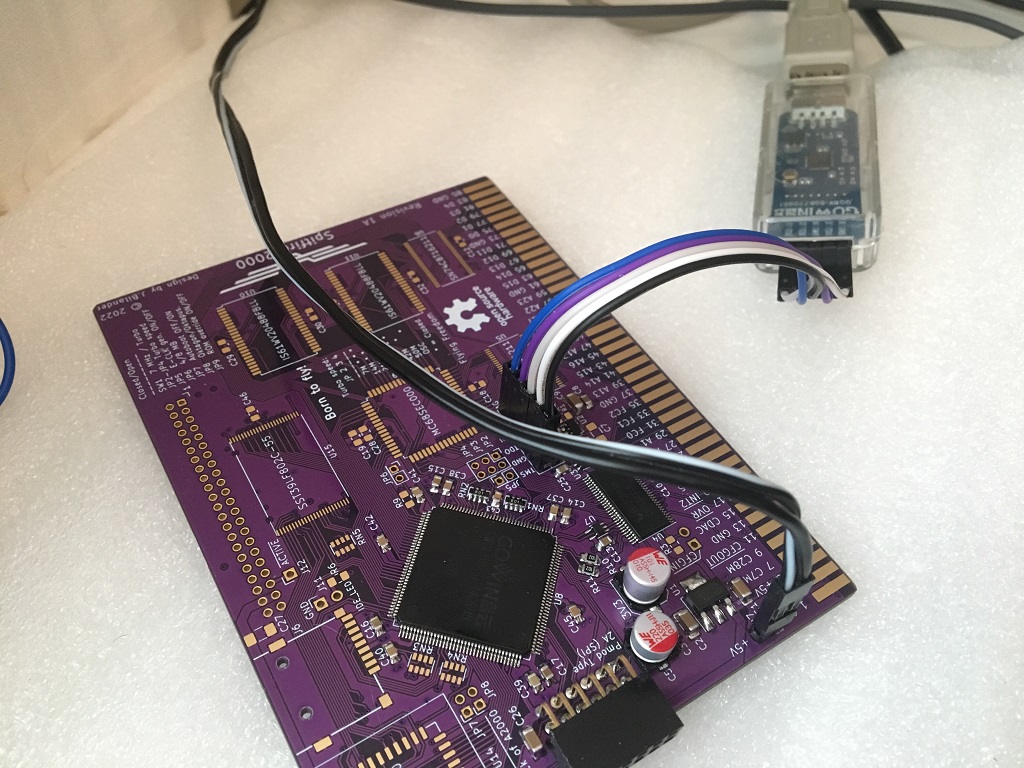
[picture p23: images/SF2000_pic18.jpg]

</a>
<br />
Make sure you populate the 4V3 LDO like this if you are using `TPS73643DBVR` or `ABLIC S-1200B43-M5T1U`, populating R1,R2,C7 is only for a ADJ-regulator to achieve 4V3.
<br />
<a href="images/SF2000_pic19.jpg">
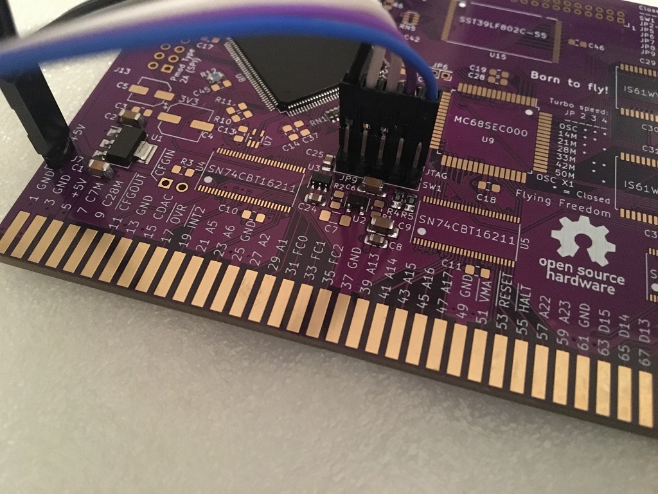
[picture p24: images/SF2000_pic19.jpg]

</a>
<a href="images/SF2000_pic20.jpg">
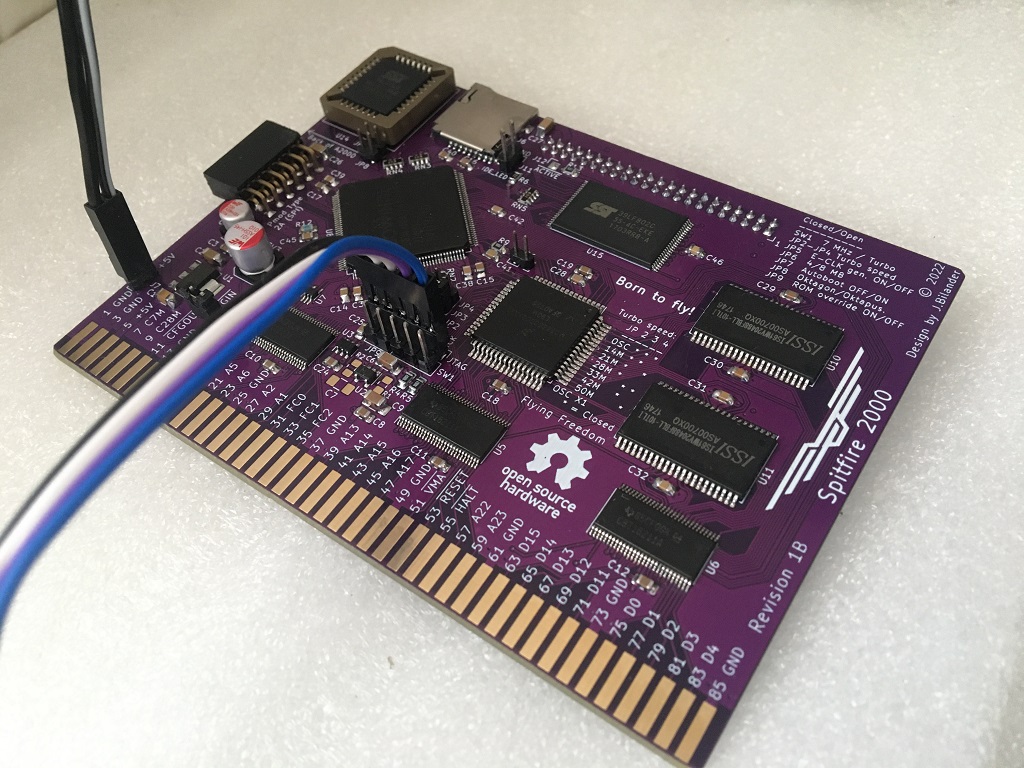
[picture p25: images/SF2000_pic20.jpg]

</a>
<br />
<a href="images/SF2000_pic21.jpg">
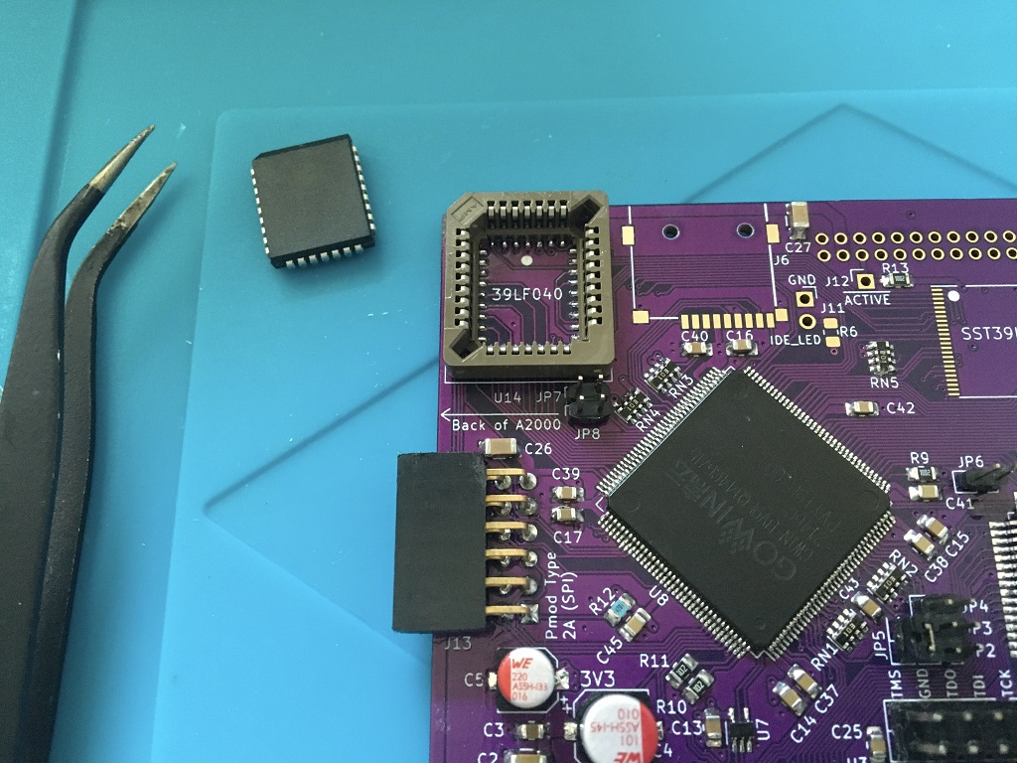
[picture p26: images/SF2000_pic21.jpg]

</a>
<a href="images/SF2000_pic22.jpg">
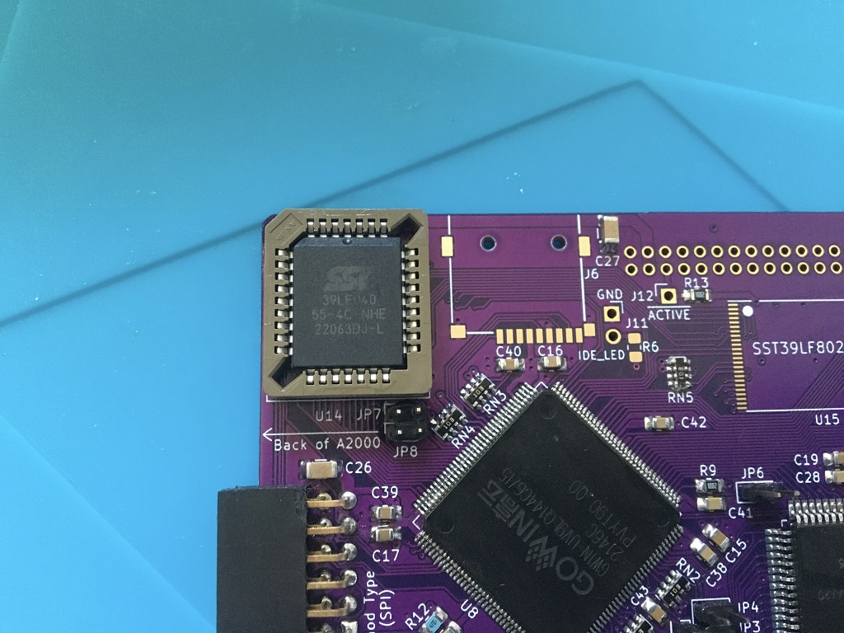
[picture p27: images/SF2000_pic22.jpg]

</a>
<br />
For A2000 and ribbon cable use you can solder a 44 pin IDE-header like this:
<br />
<a href="images/SF2000_pic23.jpg">
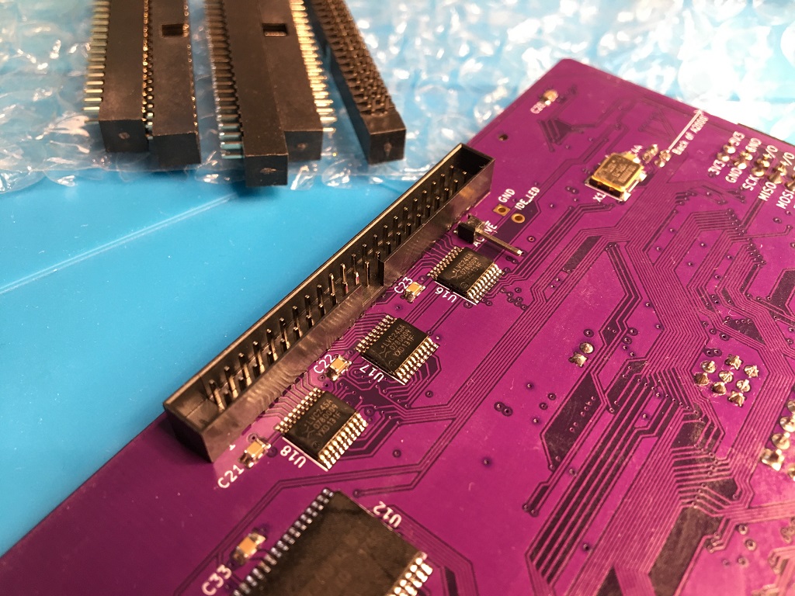
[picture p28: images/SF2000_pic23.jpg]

</a>
<a href="images/SF2000_pic24.jpg">
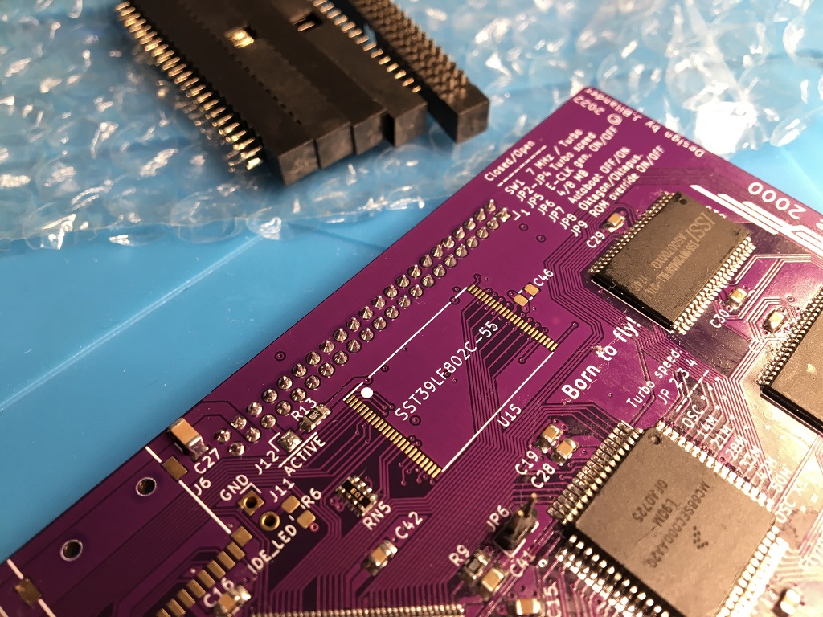
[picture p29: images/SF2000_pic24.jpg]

</a>

***

### Performance

Some MC68SEC000 can be overclocked to 42 MHz and running with only one wait state for the IDE/ATA interface we can reach really good performance:
<br />
<a href="images/SF2000_pic25.jpg">
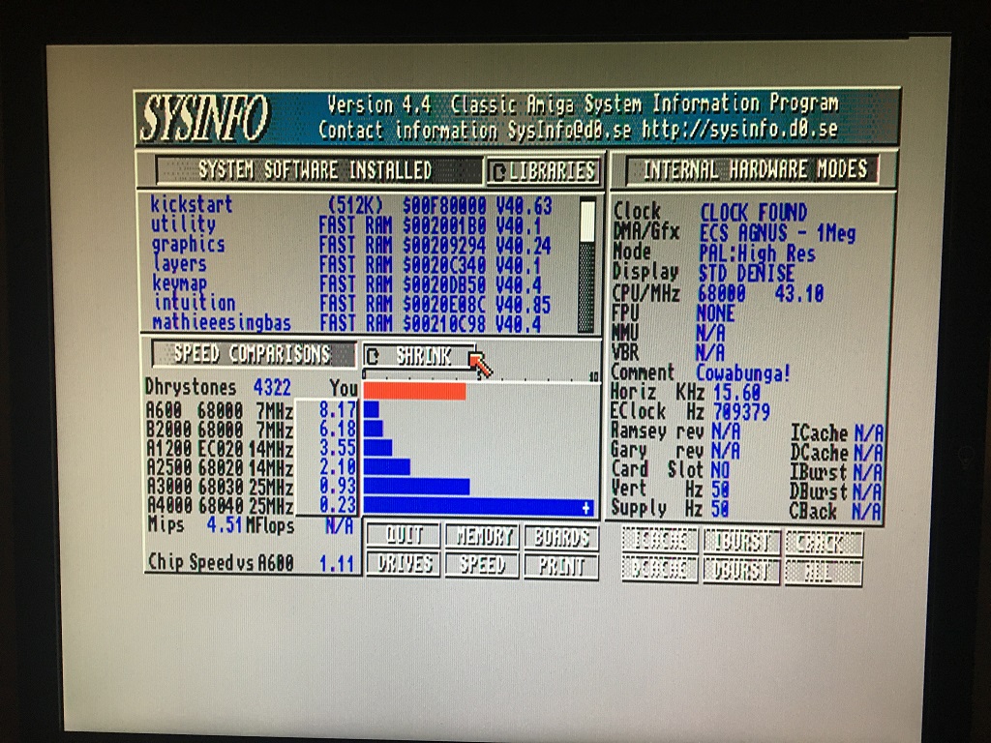
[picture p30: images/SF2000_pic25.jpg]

</a>
<a href="images/SF2000_pic26.jpg">
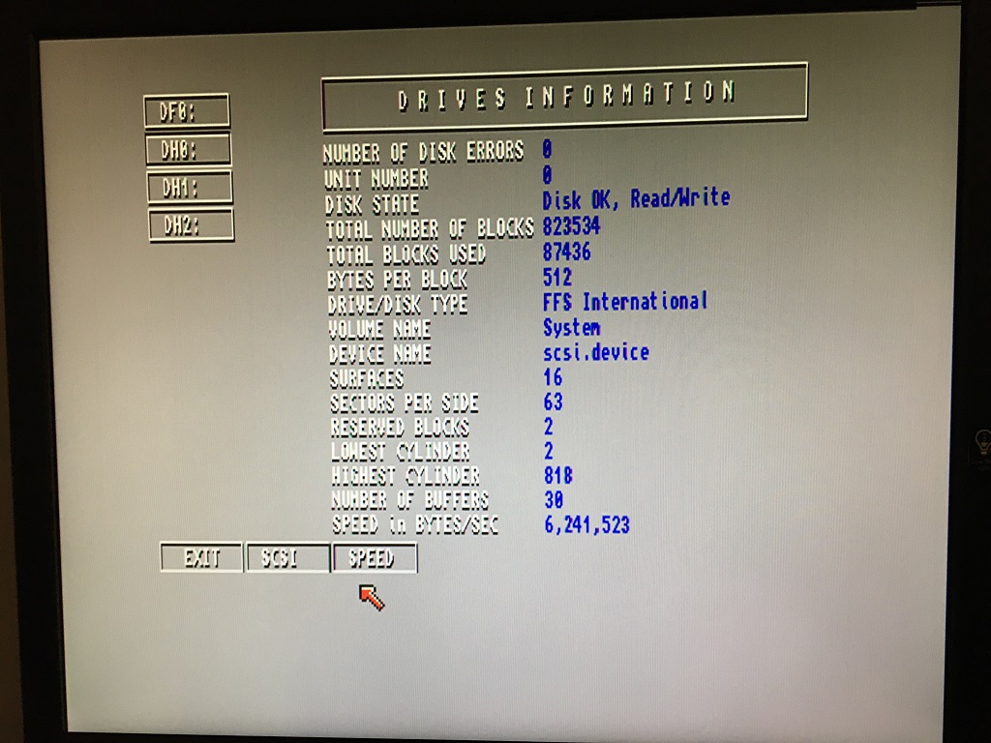
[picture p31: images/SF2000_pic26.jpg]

</a>
<br />
Flashing a ROM (in this case 3.1.4) to the FlashROM chip U15 (using LIV2's excellent sfflash-tool) and closing JP9 even better performance can be achieved:
<br />
<br />
Demo video: <br />
https://drive.google.com/file/d/1dCBK24LUC5VLB2dshrW_5n82D2emHB5-/view?usp=sharing
<br />
<br />
<a href="images/SF2000_pic27.jpg">
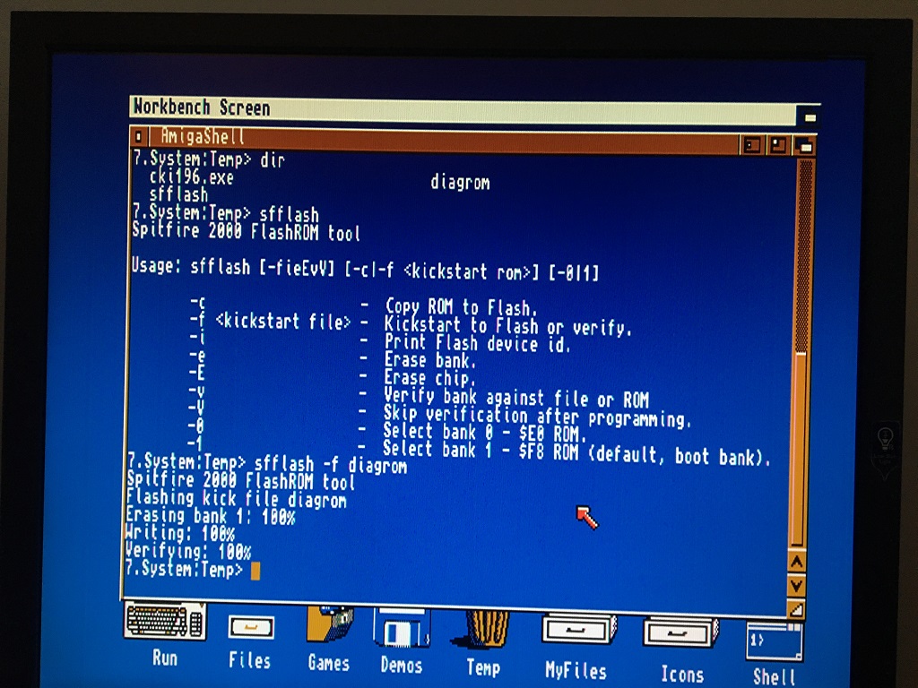
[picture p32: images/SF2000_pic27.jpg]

</a>
<a href="images/SF2000_pic28.jpg">
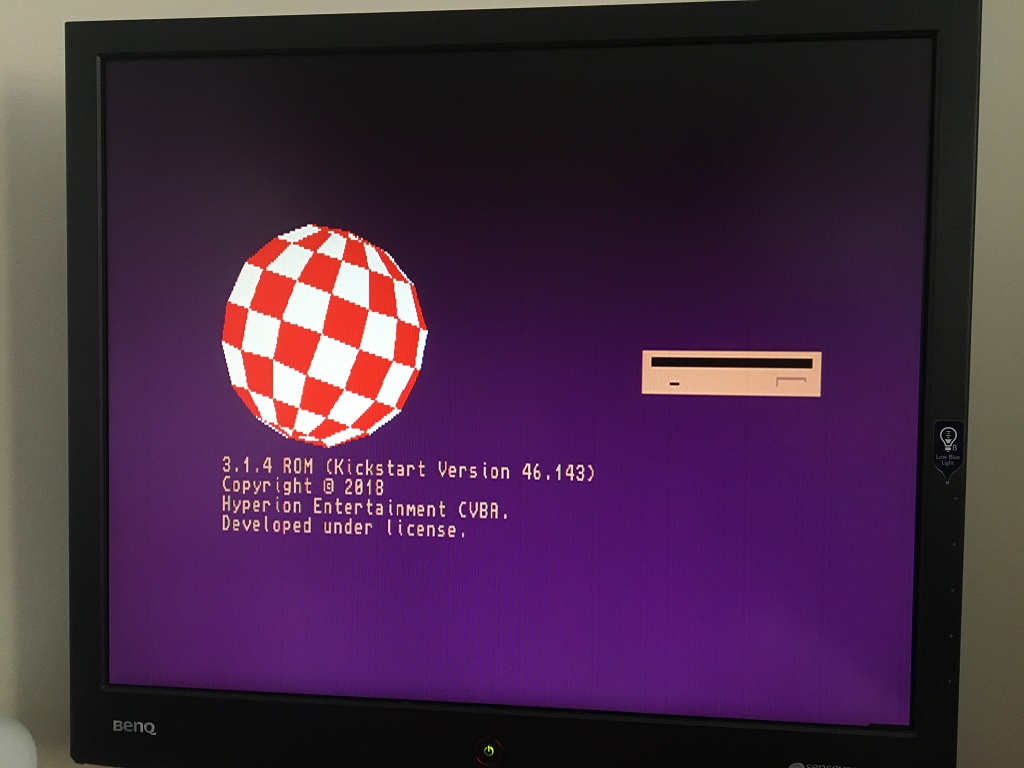
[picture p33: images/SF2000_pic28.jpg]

</a>
<br />
<a href="images/SF2000_pic29.jpg">
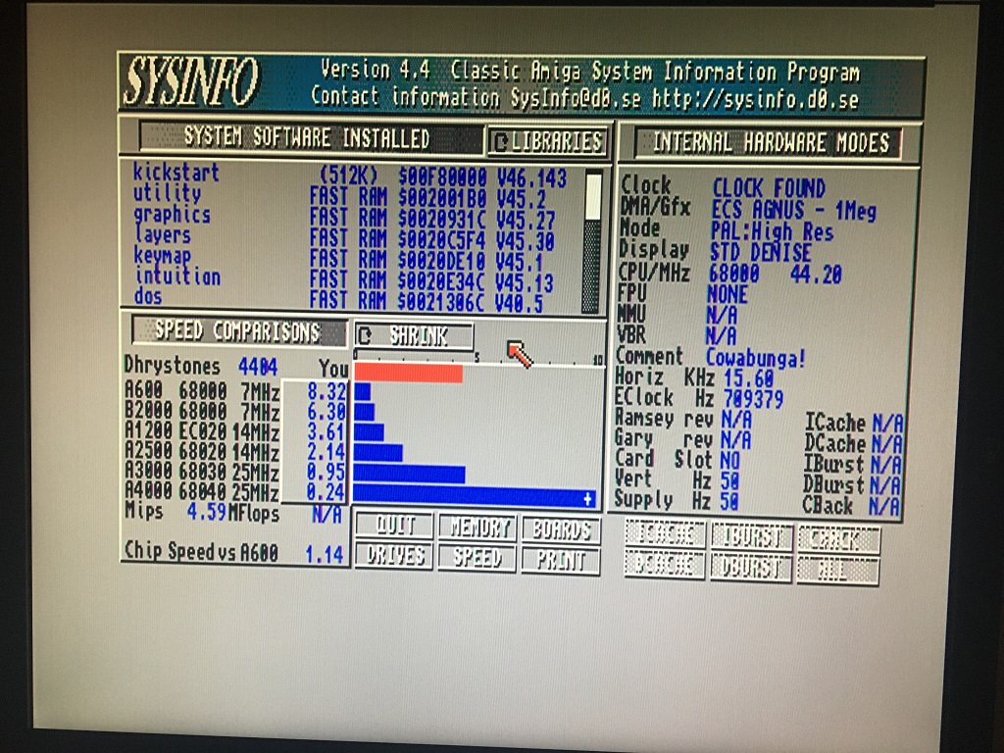
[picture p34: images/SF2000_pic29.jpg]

</a>
<a href="images/SF2000_pic30.jpg">
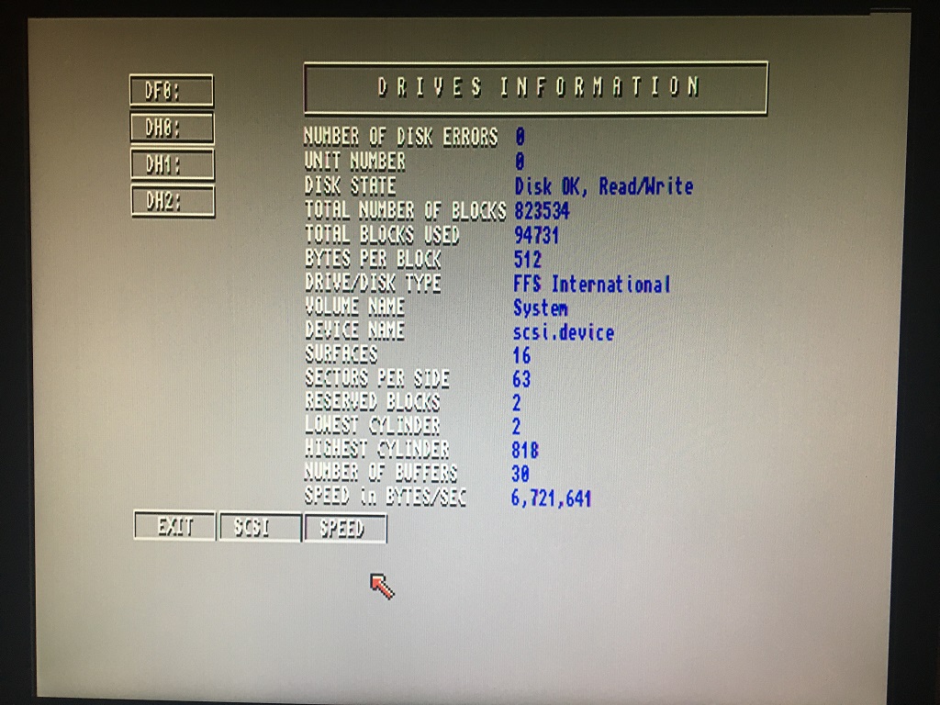
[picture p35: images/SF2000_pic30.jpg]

</a>
<br />
<br />
But for running more stable a few wait states can be added to the IDE/ATA, <br /> 
https://github.com/jbilander/SF2000-FW/blob/main/rtl/ata.v#L56 <br />
resulting in a bit slower IDE:
<br />
<br />
<a href="images/SF2000_pic31.jpg">
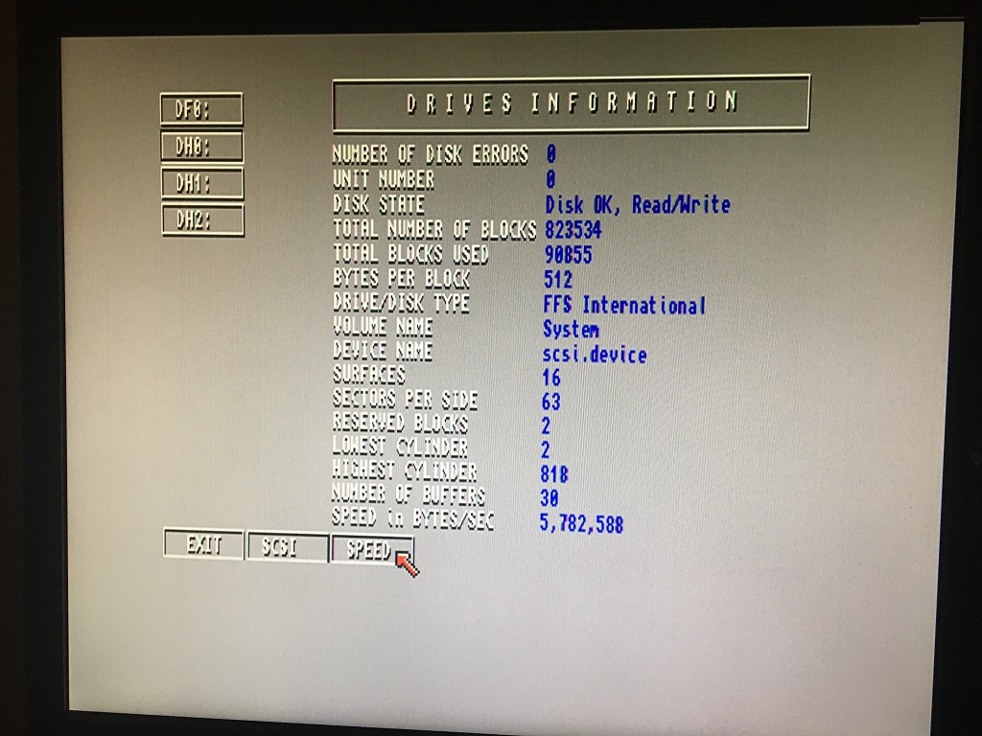
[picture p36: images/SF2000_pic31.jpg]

</a>
<br />
<br />
JTAG-header description:
<br />
<a href="images/SF2000_JTAG_pinout_desciption.jpg">
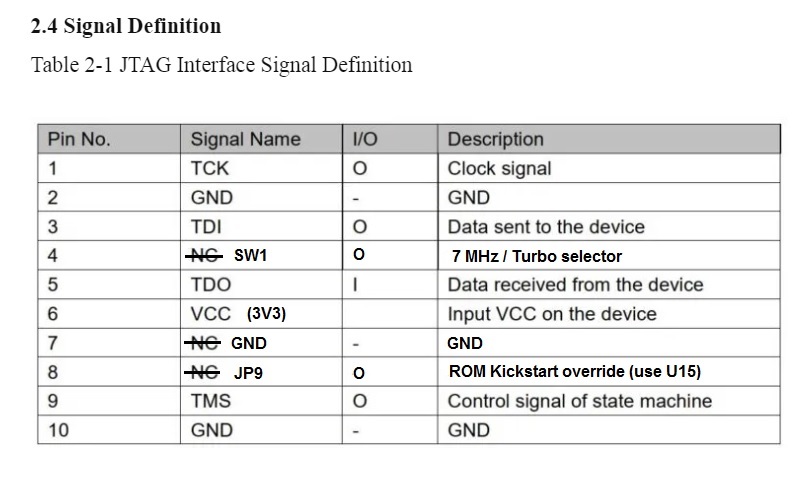
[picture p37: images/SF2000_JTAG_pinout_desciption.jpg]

</a>

***

Happy Hackin' 

***

[][cc-by-sa]

This work is licensed under a
[Creative Commons Attribution-ShareAlike 4.0 International License][cc-by-sa].

[][cc-by-sa]

[cc-by-sa]: http://creativecommons.org/licenses/by-sa/4.0/
[cc-by-sa-image]: https://licensebuttons.net/l/by-sa/4.0/88x31.png
[cc-by-sa-shield]: https://img.shields.io/badge/License-CC%20BY--SA%204.0-lightgrey.svg

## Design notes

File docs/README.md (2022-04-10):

***

GOWIN FPGA pinout
---------
Pin  | Type   | Bank | True LVDS | CFG |  Pin  | Type   | Bank | True LVDS | CFG
-|-|-|-|-|-|-|-|-|-|
&emsp;&emsp;&emsp;&emsp;&emsp;&emsp; | GW1N-UV4LQ144C6/I5 | | | | &emsp;&emsp;&emsp;&emsp;&emsp;&emsp; | GW1N-UV9LQ144C6/I5 | | | | 
1 (VCC)  | POWER | | | | | | | | | 
2 (VSS)  | GROUND | | | | | | | | | 
3 (IOL2A) | I/O | 3 | Yes | | | | | | | 
4 (IOL3A) | I/O | 3 | No | JTAGSEL_N/LPLL_T_IN | 4 (IOL5A)| I/O | 3 | No | JTAGSEL_N/LPLL_T_IN |
5 (VCCO3)  | POWER | | | | | | | | | 
6 (IOL3B) | I/O | 3 | No | LPLL_C_IN | 6 (IOL6B)| I/O | 3 | Yes | LPLL_C_FB |
7 (IOL4A) | I/O | 3 | Yes | LPLL_T_FB | 7 (IOL7A)| I/O | 3 | No | |
8 (IOL4B) | I/O | 3 | Yes | LPLL_C_FB | 8 (IOL7B)| I/O | 3 | No | |
9 (IOL6A) | I/O | 3 | Yes | | 9 (IOL8A)| I/O | 3 | Yes | |
10 (IOL6B) | I/O | 3 | Yes | | 10 (IOL8B)| I/O | 3 | Yes | |
11 (IOL9A) | I/O | 3 | No | GCLKT_7 | | | | | |
12 (IOL9B) | I/O | 3 | No | GCLKC_7 | | | | | |
13 (IOL10A) | I/O | 3 | No | TMS | 13 (IOL11A)| I/O | 3 | Yes | TMS |
14 (IOL10B) | I/O | 3 | No | TCK | 14 (IOL11B)| I/O | 3 | Yes | TCK |
15 (IOL10C) | I/O | 3 | No | SCLK | 15 (IOL12A)| I/O | 3 | No | SCLK |
16 (IOL10D) | I/O | 3 | No | TDI | 16 (IOL12B)| I/O | 3 | No | TDI |
17 (VSS)  | GROUND | | | | | | | | | 
18 (IOL10E) | I/O | 3 | No | TDO | 18 (IOL13A)| I/O | 3 | Yes | TDO |
19 (VCCO3)  | POWER | | | | | | | | |
20 (IOL10F) | I/O | 3 | No | RECONFIG_N | 20 (IOL13B)| I/O | 3 | Yes | RECONFIG_N |
21 (IOL10G) | I/O | 3 | No | DONE | 21 (IOL14A)| I/O | 3 | No | DONE |
22 (IOL10H) | I/O | 3 | No | READY | 22 (IOL14B)| I/O | 3 | No | READY |
23 (IOL10I) | I/O | 3 | No | | 23 (IOL15A)| I/O | 3 | Yes | GCLKT_6 |
24 (IOL10J) | I/O | 3 | No | | 24 (IOL15B)| I/O | 3 | Yes | GCLKC_6 |
25 (IOL11A) | I/O | 3 | Yes | GCLKT_6 | 25 (IOL22A)| I/O | 3 | Yes | |
26 (IOL11B) | I/O | 3 | Yes | GCLKC_6 | 26 (IOL22B)| I/O | 3 | Yes | |
27 (IOL13A) | I/O | 3 | Yes | | 27 (IOL26A)| I/O | 3 | Yes | |
28 (IOL13B) | I/O | 3 | Yes | | 28 (IOL26B)| I/O | 3 | Yes | |
29 (IOL15A) | I/O | 3 | Yes | | 29 (IOB4A)| I/O | 2 | Yes | |
30 (IOL15B) | I/O | 3 | Yes | | 30 (IOB4B)| I/O | 2 | Yes | |
31 (VCCX)  | POWER | | | | | | | | | 
32 (IOB4B) | I/O | 2 | Yes | | 32 (IOB6A)| I/O | 2 | Yes | |
33 (VSS)  | GROUND | | | | | | | | | 
34 (IOB5B) | I/O | 2 | No | | 34 (IOB6B)| I/O | 2 | Yes | |
35 (VSS)  | GROUND | | | | | | | | | 
36 (VCC)  | POWER | | | | | | | | | 
37 (VCCO2)  | POWER | | | | | | | | | 
38 (IOB6A) | I/O | 2 | Yes | | 38 (IOB8A)| I/O | 2 | Yes | |
39 (IOB6B) | I/O | 2 | Yes | | 39 (IOB8B)| I/O | 2 | Yes | |
40 (IOB7A) | I/O | 2 | No | | 40 (IOB9A)| I/O | 2 | No | |
41 (IOB7B) | I/O | 2 | No | | 41 (IOB9B)| I/O | 2 | No | |
42 (IOB8A) | I/O | 2 | Yes | | 42 (IOB11A)| I/O | 2 | Yes | |
43 (IOB8B) | I/O | 2 | Yes | | 43 (IOB11B)| I/O | 2 | Yes | |
44 (IOB10A) | I/O | 2 | No | | 44 (IOB12A)| I/O | 2 | No | |
45 (IOB10B) | I/O | 2 | No | | 45 (IOB12B)| I/O | 2 | No | |
46 (IOB11A) | I/O | 2 | No | | 46 (IOB13A)| I/O | 2 | Yes | |
47 (IOB11B) | I/O | 2 | No | | 47 (IOB13B)| I/O | 2 | Yes | |
48 (IOB12A) | I/O | 2 | Yes | | 48 (IOB15A)| I/O | 2 | Yes | |
49 (IOB12B) | I/O | 2 | Yes | | 49 (IOB15B)| I/O | 2 | Yes | |
50 (IOB14A) | I/O | 2 | Yes | | 50 (IOB17A)| I/O | 2 | Yes | |
51 (IOB14B) | I/O | 2 | Yes | | 51 (IOB17B)| I/O | 2 | Yes | |
52 (IOB16A) | I/O | 2 | Yes | | 52 (IOB23A)| I/O | 2 | Yes | |
53 (VSS)  | GROUND | | | | | | | | | 
54 (IOB16B) | I/O | 2 | Yes | | 54 (IOB23B)| I/O | 2 | Yes | |
55 (VCCO2)  | POWER | | | | | | | | | 
56 (IOB19A) | I/O | 2 | No | GCLKT_5 | 56 (IOB28A)| I/O | 2 | No | GCLKT_5 |
57 (IOB19B) | I/O | 2 | No | GCLKC_5 | 57 (IOB28B)| I/O | 2 | No | GCLKC_5 |
58 (IOB20A) | I/O | 2 | Yes | GCLKT_4 | 58 (IOB29A)| I/O | 2 | Yes | GCLKT_4 |
59 (IOB20B) | I/O | 2 | Yes | GCLKC_4 | 59 (IOB29B)| I/O | 2 | Yes | GCLKC_4 |
60 (IOB21A) | I/O | 2 | No | | 60 (IOB30A)| I/O | 2 | No | |
61 (IOB21B) | I/O | 2 | No | | 61 (IOB30B)| I/O | 2 | No | |
62 (IOB22A) | I/O | 2 | Yes | | 62 (IOB31A)| I/O | 2 | Yes | |
63 (IOB22B) | I/O | 2 | Yes | | 63 (IOB31B)| I/O | 2 | Yes | |
64 (IOB24A) | I/O | 2 | Yes | | 64 (IOB33A)| I/O | 2 | Yes | |
65 (IOB24B) | I/O | 2 | Yes | | 65 (IOB33B)| I/O | 2 | Yes | |
66 (IOB26A) | I/O | 2 | Yes | | 66 (IOB35A)| I/O | 2 | Yes | |
67 (IOB26B) | I/O | 2 | Yes | | 67 (IOB35B)| I/O | 2 | Yes | |
68 (IOB28A) | I/O | 2 | No | | 68 (IOB37A)| I/O | 2 | No | |
69 (IOB28B) | I/O | 2 | No | | 69 (IOB37B)| I/O | 2 | No | |
70 (IOB30A) | I/O | 2 | Yes | | 70 (IOB39A)| I/O | 2 | Yes | |
71 (IOB30B) | I/O | 2 | Yes | | 71 (IOB39B)| I/O | 2 | Yes | |
72 (IOB34B) | I/O | 2 | Yes | | 72 (IOB41A)| I/O | 2 | Yes | |
73 (VCC)  | POWER | | | | | | | | | 
74 (VSS)  | GROUND | | | | | | | | | 
75 (IOB34A) | I/O | 2 | Yes | | 75 (IOB42B)| I/O | 2 | No | |
76 (IOB36B) | I/O | 2 | Yes | | 76 (IOB43B)| I/O | 2 | Yes | |
77 (VCCO1)  | POWER | | | | 77 (VCCX) | POWER | | | |
78 (IOB36A) | I/O | 2 | Yes | | 78 (IOB43A)| I/O | 2 | Yes | |
79 (IOR17B) | I/O | 1 | Yes | | 79 (IOR24B)| I/O | 1 | Yes | |
80 (IOR17A) | I/O | 1 | Yes | | 80 (IOR24A)| I/O | 1 | Yes | |
81 (IOR15B) | I/O | 1 | Yes | | 81 (IOR22B)| I/O | 1 | Yes | |
82 (IOR15A) | I/O | 1 | Yes | | 82 (IOR22A)| I/O | 1 | Yes | |
83 (IOR11B) | I/O | 1 | Yes | GCLKC_3 | 83 (IOR17B)| I/O | 1 | Yes | GCLKC_3 |
84 (IOR11A) | I/O | 1 | Yes | GCLKT_3 | 84 (IOR17A)| I/O | 1 | Yes | GCLKT_3 |
85 (IOR10J) | I/O | 1 | No | DOUT/WE_N | 85 (IOR15B)| I/O | 1 | Yes | DOUT/WE_N |
86 (IOR10I) | I/O | 1 | No | DIN/CLKHOLD_N | 86 (IOR15A)| I/O | 1 | Yes | DIN/CLKHOLD_N |
87 (IOR10H) | I/O | 1 | No | SSPI_CS_N/D0 | 87 (IOR14B)| I/O | 1 | No | SSPI_CS_N/D0 |
88 (IOR10G) | I/O | 1 | No | SO/D1 | 88 (IOR14A)| I/O | 1 | No | SO/D1 |
89 (VSS)  | GROUND | | | | | | | | | 
90 (IOR10F) | I/O | 1 | No | SI/D2 | 90 (IOR13B)| I/O | 1 | Yes | SI/D2 |
91 (VCCO1)  | POWER | | | | | | | | | 
92 (IOR10E) | I/O | 1 | No | FASTRD_N/D3 | 92 (IOR13A)| I/O | 1 | Yes | FASTRD_N/D3 |
93 (IOR10D) | I/O | 1 | No | MCLK/D4 | 93 (IOR12B)| I/O | 1 | No | MCLK/D4 |
94 (IOR10C) | I/O | 1 | No | MCS_N/D5 | 94 (IOR12A)| I/O | 1 | No | MCS_N/D5 |
95 (IOR10B) | I/O | 1 | No | MO/D6 | 95 (IOR11B)| I/O | 1 | Yes | MO/D6 |
96 (IOR10A) | I/O | 1 | No | MI/D7 | 96 (IOR11A)| I/O | 1 | Yes | MI/D7 |
97 (IOR9B) | I/O | 1 | No | GCLKC_2 | | | | | |
98 (IOR9A) | I/O | 1 | No | GCLKT_2 | | | | | |
99 (IOR6B) | I/O | 1 | Yes | | 99 (IOR8B)| I/O | 1 | Yes | |
100 (IOR6A) | I/O | 1 | Yes | | 100 (IOR8A)| I/O | 1 | Yes | |
101 (IOR4B) | I/O | 1 | Yes | RPLL_C_FB | 101 (IOR6B)| I/O | 1 | Yes | RPLL_C_FB |
102 (IOR4A) | I/O | 1 | Yes | RPLL_T_FB | 102 (IOR6A)| I/O | 1 | Yes | RPLL_T_FB |
103 (VCCX)  | POWER | | | | 103 (VCCO1) | POWER | | | | 
104 (IOR3B) | I/O | 1 | No | RPLL_C_IN | 104 (IOR5B)| I/O | 1 | No | RPLL_C_IN |
105 (VSS)  | GROUND | | | | | | | | | 
106 (IOR3A) | I/O | 1 | No | RPLL_T_IN | 106 (IOR5A)| I/O | 1 | No | RPLL_T_IN |
107 (VSS)  | GROUND | | | | | | | | | 
108 (VCC)  | POWER | | | | | | | | | 
109 (VCCO0)  | POWER | | | | | | | | | 
110 (IOT37B) | I/O | 0 | No | | 110 (IOT42B)| I/O | 1 | No | |
111 (IOT37A) | I/O | 0 | No | | 111 (IOT42A)| I/O | 1 | No | |
112 (IOT35B) | I/O | 0 | No | | 112 (IOT41B)| I/O | 1 | No | |
113 (IOT35A) | I/O | 0 | No | | 113 (IOT41A)| I/O | 1 | No | |
114 (IOT33B) | I/O | 0 | No | | 114 (IOT39B)| I/O | 1 | No | |
115 (IOT33A) | I/O | 0 | No | | 115 (IOT39A)| I/O | 1 | No | |
116 (IOT30B) | I/O | 0 | No | | 116 (IOT37B)| I/O | 1 | No | |
117 (IOT30A) | I/O | 0 | No | | 117 (IOT37A)| I/O | 1 | No | |
118 (IOT26B) | I/O | 0 | No | | 118 (IOT34B)| I/O | 0 | No | |
119 (IOT26A) | I/O | 0 | No | | 119 (IOT34A)| I/O | 0 | No | |
120 (IOT24B) | I/O | 0 | No | | 120 (IOT32B)| I/O | 0 | No | |
121 (IOT24A) | I/O | 0 | No | | 121 (IOT32A)| I/O | 0 | No | |
122 (IOT22B) | I/O | 0 | No | | 122 (IOT29B)| I/O | 0 | No | GCLKC_1 |
123 (IOT22A) | I/O | 0 | No | | 123 (IOT29A)| I/O | 0 | No | GCLKT_1 |
124 (IOT20A) | I/O | 0 | No | | 124 (IOT27B)| I/O | 0 | No | |
125 (VSS)  | GROUND | | | | 125 (IOT27A)| I/O | 0 | No | |
126 (IOT18B) | I/O | 0 | No | | 126 (IOT24B)| I/O | 0 | No | |
127 (VCCO0)  | POWER | | | | | | | | | 
128 (IOT17A) | I/O | 0 | No | | 128 (IOT24A)| I/O | 0 | No | |
129 (IOT16B) | I/O | 0 | No | | 129 (IOT22B)| I/O | 0 | No | |
130 (IOT16A) | I/O | 0 | No | | 130 (IOT22A)| I/O | 0 | No | |
131 (IOT14B) | I/O | 0 | No | | 131 (IOT20B)| I/O | 0 | No | |
132 (IOT14A) | I/O | 0 | No | | 132 (IOT20A)| I/O | 0 | No | |
133 (IOT12B) | I/O | 0 | No | | 133 (IOT17B)| I/O | 0 | No | |
134 (IOT12A) | I/O | 0 | No | | 134 (IOT17A)| I/O | 0 | No | |
135 (IOT9B) | I/O | 0 | No | | 135 (IOT15B)| I/O | 0 | No | |
136 (IOT9A) | I/O | 0 | No | | 136 (IOT15A)| I/O | 0 | No | |
137 (IOT7B) | I/O | 0 | No | | 137 (IOT12B)| I/O | 3 | No | |
138 (IOT7A) | I/O | 0 | No | | 138 (IOT12A)| I/O | 3 | No | |
139 (IOT6B) | I/O | 0 | No | | 139 (IOT10B)| I/O | 3 | No | |
140 (IOT6A) | I/O | 0 | No | | 140 (IOT10A)| I/O | 3 | No | |
141 (IOT4B) | I/O | 0 | No | | 141 (IOT8B)| I/O | 3 | No | |
142 (IOT4A) | I/O | 0 | No | | 142 (IOT8A)| I/O | 3 | No | |
143 (IOT3B) | I/O | 0 | No | MODE1 | 143 (IOT6B)| I/O | 3 | No | MODE1 |
144 (IOT2B) | I/O | 0 | No | MODE0 | 144 (IOT5A)| I/O | 3 | No | MODE0 |

***

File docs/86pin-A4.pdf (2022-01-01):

Coprocessor Expansion and 86 Pin Signals on AmigaComputers

by Dave Haynie

June 24, 1987

ABSTRACT

This document details the signals found on the various types of 86 pin expansion connectors on different Amiga computers, especially the signals found on the B2000 computer’s 86 pin coprocessor slot, and howthese differ from the similar signals found on A2000 computers and those of the original A1000 computers. This paper also explains the Coprocessor Slot’sautoconfiguration and DMA protocols and howthey fix the problems introduced in the A2000 Coprocessor Slot.

1

### 1. Introduction

This document details the signals found on the various types of 86 pin expansion connectors on different Amigacomputers, especially the signals found on the B2000 computer’s 86 pin Coprocessor Slot, and howthese differ from the similar signals found on A2000 computers and those of the original A1000 computers. This paper also explains the Coprocessor Slot’sautoconfiguration and DMA protocols and howthey fix the problems introduced in the A2000 Coprocessor Slot.

### 1.1. Changes From Previous Documents

We’v e kept the 86 pin specification on the B2000 as similar to those available on the A2000, A1000, and A500, whereverpossible. However, some major changes were absolutely required. With the design of the A2000, the function of the 86 pin slot had shifted from general expansion connector to expansion specifically intended for coprocessors and similar devices. Thus, while the A500’sand A1000’s 86 pin connectors have tosupport both some kind of coprocessor expansion and the normal ZORROexpansion, the A2000 machines can optimize each slot for its purpose if required. Or if necessary,which is more the case.
The 86 pin connector on the A500 and A1000 becomes something of an advantage, because of the fact that all expansion must be done externally.When a coprocessor device (something that needs to completely replace the 68000 in all forms of bus access and operation, likea68020 accelerator card) is added, it can physically sit between the computer motherboard and the 100 pin expansion box, thus allowing the device to completely replace the action of the motherboard’sprocessor from the point of view of the expansion box. Amachine with both slots on the motherboard must provide some facility to logically insert the 86 pin slot in front of the 100 pin slot for certain applications¹
In the A2000, the Coprocessor Slot signals that control DMA can be used to insert the coprocessor in the place of the normal 68000 via the standard 68000 DMA request protocol. This, however, isn’tatotally transparent replacement; the action of the coprocessor taking control overthe local bus from the 68000, in the A2000, can block other DMA events coming overfrom the 100 Expansion Bus. Fortotal control of the Expansion Bus on the A2000, the 68000 could be physically removedfrom the motherboard, but that would result in the "coprocessor" being a complete "replacement" processor,with no swapping between the twopermissible. The B2000 solves these problems with a higher-levelDMA protocol between the main and coprocessor devices. This is covered in a later chapter.

### 1.2. Definition of Terms

Several terms are used in the following text, and an understanding of them is required to speak proper Amigaese. A device known as a PIC, or Plug In Card, is a device that plugs into an Expansion Slot and follows the autoconfiguration protocol. Nothing should plug into a 100 pin slot that doesn’tfollowthis protocol. The term slot refers to a physical plug in location, either the Coprocessor Slot or one of the fiveavailable Expansion Slots. The terms 100 Pin Slot and Expansion Slot are considered synonyms, and describe one of the five100 pin Expansion Slots. The Expansion Bus is the processor bus that is in common between all Expansion Slots. The terms 86 Pin Slot, Coprocessor Slot, and Local Slot are considered synonyms, and pertain to the 86 pin Coprocessor Slot in the A2000 and B2000. The terms 86 Pin Edge and Expansion Edge are considered synonyms, and pertain to the 86 pin Expansion Edge in the A1000 and A500. The Local Bus is the processor bus directly connected to the 68000 processor and the Coprocessor Slot or Expansion Edge; both the Coprocessor Slot and Expansion Edge are considered Local Bus Ports. Each different implementation of a hardware design is termed an Instance of that design; thus, the A2000’sCoprocessor Slot, the B2000’sCoprocessor Slot, and the A500 and A1000 Expansion Edges are instances of Local Bus ports.
Along with an understanding of Amigabus terms, a familiarity with Motorola’s68000 processor and its characteristic names for things will also be very useful in understanding this document.

1Please refer to the paper "100 Pin Signals on AmigaComputers" by Dave Haynie, for a complete discussion of the 100 pin bus.

2

### 2. Coprocessor Slot Signals

The Coprocessor Slot signals discussed belowapply for most of the machines, though in some cases the item mentioned exists on only some of the machines; this will be specifically.Most of these signals are directly in common with the 68000, or directly a part of the 68000 local bus, instead of being buffered as on the Expansion Bus. No signal on a Coprocessor card should load the Local Bus with more than one "F" series standard load.

### 2.1. Power Connections

The Coprocessor Slot provides several different voltages designed to supply Coprocessor devices. The A2000 power supply is currently rated at 200 Watts, which supplies the main board and all other expansion ports as well as the Coprocessor Slot.

### 2.1.1. Digital Ground (Ground)

Digital supply ground used by all expansion cards as the return path for all expansion supplies. This are found on all instances of the Local Bus ports. See Appendix for pin assignments.

### 2.1.2. Main Supply (+5V)

Main power supply the Coprocessor slot, and is can supply up to 2.0 Amps of +5VDC on the A2000. The maximum supply current for the entire A2000 system is 20 Amps for all devices inside the A2000 that use +5V, including the motherboard. The corresponding pins on the Expansion Edge of the A1000 can source only 1 Amp, and evenless on the A500. Pins: 5, 6.

### 2.1.3. Negative Supply (-5V)

Negative version of the main supply,for small current loads only; there’satotal of 0.3 Amp for the entire A2000 system. This pin is similar to what’savailable on the A1000 and A500, though these other instances will have different currents available. Pin: 8.

### 2.1.4. High Voltage Supply (+12V)

Higher voltage supply,useful for communications cards an other devices requiring greater that digital voltage levels. This is intended for small loading only; there’satotal of 8 Amps for the entire A2000 system, much of which is normally devoted to floppyand hard disk drive motors. Found on all instances of Local Bus Ports, though the available currents may vary.Pin: 10.

### 2.2. Clock Signals

There are various system clocks available at all Local Bus Ports, useful in designing synchronous Coprocessor systems. Loading on these clocks should be watched very carefully on all types of Amigacomputers.

2.2.1. /C1 Clock
This is a 3.58 MHz clock (3.55 MHz on PAL systems) that’ssynched to the falling edge of the 7M system clock. Also known as /CCK in some places. Pin 16.
2.2.2. /C3 Clock
This is a 3.58 MHz clock (3.55 MHz on PAL systems) that’ssynched to the rising edge of the 7M system clock. Also known as /CCKQ in some places. Pin 14.

### 2.2.3. CDAC Clock

This is a 7.16 MHz clock (7.09 MHz on PAL systems) that leads the 7M system clock by about 70ns (90 degrees). Pin 15.

3

### 2.2.4. E Clock

This is the 68000 generated "E" clock, used for 6800 family peripherals driven by "E" and 6502 peripherals driven by PHI2. This clock is six 7M clocks high, four clocks low, asper the 68000 spec. This clock is always generated by the 68000, regardless of the state of the bus and the Coprocessor; this fact should be considered by the Coprocessor implementor when designing anyCoprocessor /VMA logic. Pin 50.

2.2.5. 7M Clock
This is the 7.16 MHz system clock (7.09 MHz on PAL systems). This is available only on the B2000 at this pin, and is in common with the 68000’sclock input. This pin, pin 7, is unused on all other Local Bus Port instances. Manyapplications that run on systems without the 7M clock create a 7M equivalent clock, using the relationship EQU7MHz = /C1 XNOR /C3; care must be taken in considering anyadditional delays that this equivalent clock causes on systems other that the B2000.
2.2.6. 28MHz Clock
This is the 28.64 MHz fundamental clock used to derive all other system clocks under normal operation. There’s no guaranteed phase relationship between this clock and the system clocks. When the system is being driven by an external clock source via XCLK and /XCLKEN, this clock will essentially be completely asynchronous to the system clocks. It is provided mainly to provide a fast clock for fast coprocessors. This is pin 9 on the Coprocessor Slot, and is an unused pin on the Expansion Edge of the A500 and A1000.

### 2.3. Addressing and Control Signals

These signals are various items used for the addressing of resources on a coprocessor card by the by the 68000 and anyDMA devices, and for 24 by 16 bit addressing of other system resources by a coprocessor device (which may easily have more potential). Most of these signals are directly in common with 68000 signals.

### 2.3.1. Read-Write (R/W)

The 68000’sR/W output. When drivenhigh it indicates a read or internal cycle, when drivenlow itindicates awrite cycle. When the coprocessor takes over it drivesthis line; the 68000’soutput will tri-state. Pin 68.

### 2.3.2. Address Bus (A1-A23)

This directly connects to the 68000’saddress bus, providing 16 megabytes of address space with 23 bits of address for a 16 bit data bus. The 68000 is capable of driving only this much address space. Thus, anyresources on acoprocessor board must map somewhere into the 68000 memory space. The best thing to do with anysuch memory is allow it to be autoconfigured by the 1.2 OS; this will place it somewhere in the 8 megabyte space starting at $200000 (the A2000 doesn’tsupport autoconfiguration from the Coprocessor Slot, the B2000 does). Anyresources intended specifically for the coprocessor only can be located above the 68000’s 16 meg abyte space if the coprocessor hardware permits that extended addressing. All board and Expansion bus resources will normally map into the first 16 megabytes of the address space of a coprocessor board. See Appendix for pin list.

### 2.3.3. Address Strobe (/AS)

The falling edge of this strobe indicates that addresses are valid, the rising edge signals the end of the memory cycle. This is in common with the 68000 /AS signal. The coprocessor drivesthis signal when it takes over; the 68000’swill tri-state. Found on pin 74.

### 2.3.4. Data Bus (D0-D15)

This is directly connected to the 68000’sdata bus, providing 16 bits of data accessible by word or either byte. Anycoprocessor handling words larger than 16 bits must either step down to 16 bits on its own or provide circuitry to convert the 16 bit word size of the main board and Expansion Bus to the natural size of such a coprocessor,when accessing main board resources. See Appendix for pin list.

4

### 2.3.5. Data Strobes (/LDS, /UDS)

This these are the 68000’supper and lower data strobes. The strobes fall on data valid during transfer; the lower strobe being used for the lower byte (evenbyte address), the upper strobe being used for the upper byte (odd byte address). Like/AS, these must be driven by the Coprocessor as it assumes control, as the 68000 pins will tri-state. Pins: 70, 72.

### 2.3.6. Valid Memory Address (/VMA)

Output from the 68000 indicating a valid address for 6800 style peripheral devices, in response to a /VPA input. This output goes tri-state when the Coprocessor takes overfrom the 68000, and as such must be re-created by the coprocessor in response to a VPAsignal from somewhere on the motherboard. Pin 51.

### 2.3.7. Valid Peripheral Address (/VPA)

Input to the 68000 indicating the address has selected a 6800 or 6502 style peripheral, so the 6800 style peripheral access should takeplace. When the 68000 has given up the bus to the Coprocessor,this input is ignored and must be handled by the Coprocessor board. Pin 48.

### 2.3.8. Data Transfer Acknowledge (/DTACK)

This signal is the 68000’sData Transfer Acknowledge input, though its being driven on the motherboard under most conditions. Normally in the Amigasystem, Amigasystem logic creates /DTACKfor a simple, no-wait state cycle (this may be varied by the custom chips). Therefore, this signal is treated as an output to the Expansion and Coprocessor Slots, for most situations. Anyslowdevice on the bus that needs to control /DTACKmay do so by negating XRDYtohold off/DTACK or asserting /OVR very quickly to tri-state /DTACK. Anyany coprocessor must be able to support this action by Expansion boards as well. Note that depending upon when /AS is asserted by abus master when accessing the CHIP memory,one of twopossible cycles may result. If /AS is asserted during C1 low, C3low,the bus cycle is considered "in-sync", and will proceed, with /DTACKdriven as for a normal, 4 tick clock cycle. If instead, /AS is asserted during C1 high, C3 high, the bus cycle is considered "out of sync" and the internally generated /DTACKwill be held off, causing a wait state that’sdesigned to "sync-up" the DMA cycle with the custom chip’smemory cycle. Of course, when a coprocessor is accessing any of its on-board resources the designer can implement anydata transfer reasonable scheme that comes to mind. This signal is on pin 66.

### 2.3.9. Processor Status (FC0-FC2)

These signals are the 68000 Processor Status outputs, which can be used by bus devices to determine the internal state of the 68000 anytime /AS is asserted. When a coprocessor is in charge, it must drive these pins in a way compatible with howthe 68000 does it. The different 68000 status codes can be found in any68000 spec sheet. Pins 31, 33, 35.

### 2.3.10. Bus Error (/BEER)

This is an input that goes directly to the 68000. Its used to indicate the occurrence of some kind of bus error. AnyExpansion Card capable of detecting a bus error relating directly to that card can assert /BEER when that bus error condition is detected. At other times, the card must monitor /BEER and be prepared to tri-state all of its on-bus output buffers wheneverthis signal is asserted. The Coprocessor card won’thav e to tri-state on /BEER, but it must note it and provide some way of handling the occurrence (the 68000 under normal Amiga OS control merely signals an Guru Error based on the Bus Error Exception). Since anynumber of devices may assert /BEER, and nearly ev erything in the system must monitor it, anydevice that drives/BEER must drive with an open collector or similar device capable of sinking at least 12ma, and anydevice that monitors /BEER should place as little load on it as possible (1 "F" type load or less, per board, is suggested). This signal is connected to a lowvalued on-board pullup resistor,and shouldn’tneed anymore pulling up. Pin 46.

### 2.3.11. System Reset (/RST)

Pin 53 of the bus contains the /RST signal which is in common with the original 68000 reset signal. The /RST signal is bidirectional, and the 68000 tri-states it when the coprocessor takes over. It is only necessary for the

5

processor to output this signal if it needs to reset the system under program control. The /RST signal is connected to amedium valued on-board pullup resistor and shouldn’tneed anymore pulling up. The coprocessor must monitor this signal and respond to it appropriately; this may mean a complete reset, but it doesn’thav e to. The Coprocessor can also assert this line if a system reset is desired. up.

### 2.3.12. System Halt (/HLT)

This is the 68000’sprocessor halt signal, tied directly to the 68000. It is connected to a medium valued on-board pullup resistor and shouldn’tneed anymore pulling up. This signal, when asserted, will halt and tri-state the 68000 at the end of the current bus cycle. If driven by the 68000, it indicates detection of a double bus fault. For a complete system reset, the 68000 looks for both the /RST and /HLTlines to be asserted. The Coprocessor should handle this signal in a similar fashion. Pin 55.

### 2.3.13. Decoded Interrupts

Tw o of the 68000 non-encoded interrupt inputs are available at the Coprocessor slot, on pin 19 for interrupt level2(/INT2) and on pin 22 for interrupt level6(/INT6). These are the same interrupts used by the Amigainternal system chips and encoded by the Paula chip. Theycan be used by a Coprocessor board by driving them to generate 68000 interrupts when the 68000 is in charge, though generally theydon’t do much when the Coprocessor is in charge.

### 2.3.14. Encoded Interrupts (/IPL0-/IPL2)

The Coprocessor Slot provides the encoded interrupt lines /IPL0, /IPL1, and /IPL2 on bus pins 40, 42, and 44 respectively,which are the normal encoded interrupt inputs to the 68000. Nothing on the Coprocessor slot can drive these lines, but theymust be monitored by anyCoprocessor or alternate processor that needs to be able to respond to anysystem interrupts when acting as the bus master.

### 2.3.15. Override (/OVR)

The /OVR, or Override, signal is a special Amigaexpansion signal that can servetwo purposes. The signal can basically turn offthe on-board decoding of system memory ranges, including those used by the Amigacustom chips. As aresult of this, it can also turn offinternally generated things, like/DTACK. The timing in the A500 and B2000, based on the Gary chip (not the PALs of the older machines), effectively prohibits the use of /OVR for the area of address space outside of the $200000-$9FFFFF (Expansion Bus) range.
The supported use of this signal is to allowthe Coprocessor board to create its own /DTACK. Asserting /OVR will tri-state the motherboard generated /DTACKsignal, allowing it to be driven. The same effect can be achieved for most applications by using XRDY to delay the motherboard’sgeneration of /DTACK. Pin 17. Pin 17.

### 2.3.16. External Ready (XRDY)

This input provides a way for an external device to delay the motherboard generated /DTACK, for things like slowmemory and I/O boards that need to add wait states. This signal should be negated very quickly, no later than 60ns from address valid (/AS asserted), in order for the motherboard circuitry to have enough time to prevent the normal assertion of /DTACK. XDRYshould stay negated for as manywait states are required. Once XRDYis asserted, /DTACKcompletes the rest of the normal cycle. XRDYisawired-OR input; it is pulled up by a resistor on the motherboard, and should be drivenwith an open collector or equivalent output. Pin 18.

### 2.3.17. Configuration Chain (/COPCFG)

Pins 11 and 12 are basically the configuration IN and configuration OUT signals. Pin 12, the configuration IN input, is grounded on all versions of the Local Bus Ports, indicating that this Slot is the first in anyconfiguration chain and may proceed with configuration. On the A500, A1000, and A2000, the configuration OUT signal, pin 12, is a no-connect. Because of this, its impossible to normally autoconfigure anydevice in the Coprocessor slot of an A2000. On the B2000, pin 11 is a true configuration OUT signal, which becomes the configuration IN input to the first Expansion Slot. Thus, the coprocessor slot is configured first on the B2000. Anote of caution here, though. All normal Expansion Bus devices assert their /SLAVE output whenevertheyrespond to an address. This /SLAVE

6

output allows the collision detect circuitry to determine if multiple devices are responding to the same address. When a collision is detected this way,the /BEER signal is asserted, causing all PICs to tri-state, and saving both these PICs and the Expansion Bus drivers from anypotentially destructive buffer fights. While the Coprocessor slot on the B2000 can be automatically configured, it can’tassert a SLAVE signal for collision detect. Thus, designers must be very careful with anyautoconfiguring resources on a Coprocessor card.
During the autoconfiguration process, first the Coprocessor card, then all an unconfigured PICs in turn, respond to the 64K address space starting at $E80000 as their respective CFGIN signals are asserted. All unconfigured PICs come up with CFGOUT negated. When configured, or told to "shut up", the Coprocessor Card or any PIC should assert CFGOUT,which results in the CFGIN of the next slot to be asserted. On-board logic automatically passes on the state of the previous CFGOUT to the next CFGIN for anyslot not occupied by a PIC, so there’s no need to sequentially populate the Expansion Bus Slots and no need to have the Coprocessor Card do anyautoconfiguring if there’s no need for real autoconfiguration.

### 2.4. DMA and Coprocessor Signals

This will be covered in more detail in the next chapter,but this section covers the basic signals involved in DMAs and the Coprocessor interface.

### 2.4.1. Bus Request (/BR, /CBR)

All instances of Local Expansion Ports have a Bus Request to 68000 of some kind. In the A2000, as in the A500 and A1000, this is directly connected to the 68000’s/BR input, which is considered a wired-OR input; all devices driving this input must technically drive itwith an open collector or equivalent driver. Inactuality,the A500 and A1000 don’tuse this at all internally, so a standard drivermay be used if necessary.The A2000’s/BR input is shared by the /BR output of the DMA arbitration logic, so this will be necessary on an A2000 Coprocessor Slot device. The B2000 has in place of the 68000’s/BR line a special bus request all its own, /CBR. The difference between this and /BR is covered in the next chapter.Inboth cases, the signal is an input to the 68000 used to request mastership of the Local Bus. The signal is found on pin 60.

### 2.4.2. Bus Grant (/BG, /CBG)

All instances of Local Expansion Ports have a Bus Grant from the 68000 of some kind. In the A2000, as in the A500 and A1000, this is directly connected to the 68000’s/BG output. In the B2000, a Coprocessor specific Bus Grant signal, /CBG, is in its place. In either case, the signal is asserted by the 68000 in response to a Bus Request. This indicates to the device in the Coprocessor slot that the 68000 will fully relinquish the bus at the end of this cycle. A /BG received on the Coprocessor Slot in an A2000 could be a Grant given in response to an Expansion Bus DMA request as well as one in response to the Coprocessor Slot DMA request. On the B2000, /CBG will only be asserted if the Coprocessor Slot is granted the bus. This signal is found on pin 64.

### 2.4.3. Bus Grant Acknowledge (/BGACK)

This is the 68000’s/BGACK, or Bus Grant Acknowledge, signal. Anydevice that receivesabus grant from the 68000 should assert this signal as long as the DMA continues, releasing it once the DMA request is finished. This signal should never be asserted until the specific Bus Grant has been received, /AS is negated, /DTACKis negated, and /BGACK itself is negated, indicating that all other potential bus masters have relinquished the bus. This output is driven as a wired-OR output, so all devices driving it must drive itwith an open collector or equivalent device. Pin 62.

### 2.4.4. Coprocessor Grant Acknowledge (/BOSS)

This signal exists only on the B2000, on pin 20. That pin is unused on both the A2000 and the A500. Originally,this pin was called /PALOPE on the A1000, and was part of the planned ROM expansion method. This is currently obsolete; the method of ROM expansion was changed to work without the need for such a signal. On the B2000, the /BOSS signal is driven by a Coprocessor instead of /BGACK when the Coprocessor wishes the DMA access granted it to be a true Coprocessor access, not a simple DMA. This is all explained in the following chapter.

7

### 3. The B2000 Coprocessor Interface

The B2000 computer implements an extended version of the A2000’sCoprocessor Slot, designed to makethe swapping of main processors under program control much more powerful and transparent to the rest of the B2000 system. There are things that can be done from the B2000 Coprocessor Slot that can’t be done from the A2000’s Coprocessor Slot, so this is an important consideration to anyone designing a Coprocessor device of some kind.

### 3.1. Normal 68000 DMA Architecture

The 68000 supports hardware signals designed to permit a simple DMA protocol. This protocol allows multiple devices to takecontrol of the 68000’sdata, address, and control buses. When adevice of some kind desires direct access to the 68000’sbus, it asserts the /BR (Bus Request) input of the 68000. Once /BR is asserted, the 68000 will complete whateveroperation its doing to the point at which it can cleanly relinquish its bus. At this point, it will assert its /BG (Bus Grant) output, telling the device requesting DMA that its just about ready to shut down. The requesting device then issues /BGACK (Bus Grant Acknowledge) as soon as the 68000 is completely off the bus (/DTACKand /AS are negated). When the DMAing device is done with the bus, it releases /DTACKand /BR, and the 68000 will then release /BG.

### 3.2. Wherethe 68000 DMA Protocol Fails

The above protocol, as implemented in the 68000, is sufficient for manytype of DMA operation, especially for simple things in which there are single DMA devices on the bus. What this doesn’teasily account for are multiple DMA devices. While the /BR and /BGACK inputs to the 68000 can be wire-ORed to support several devices, there are still problems with this scheme. Should multiple devices request DMA at the same time, the 68000 will see nothing different that if only one device is requesting DMA. While careful monitoring of the /BGACK by responding potential bus masters can solvesome of the problems, there are much cleaner approaches to this problem.
One such solution is implemented in the ZORROand A2000/B2000 Expansion Buses. Each slot on the Expansion Bus has its own private Bus Request and Bus Grant. Each Bus Request signal is considered by a priority encoding and latching circuit. The result of this is that, if simultaneous Bus Requests come in from Expansion Slots, only the Slot givenhigher priority will actually get a Bus Grant. AnyBus Requests that come in while another DMA is in effect will be held offuntil the 68000’s/BG line has been negated for at least one tick. This circuitry, part of the original ZORROspecification, eliminates the problems that can occur with various DMA devices all competing for the Expansion and Local buses.

### 3.3. Wherethe Expansion DMA Protocol Fails

With the introduction of the A2000 and its Coprocessor Slot, twonew problems have appeared. One of these is the old priority problem. All of the Expansion Bus Requests are priority encoded into one signal that drivesthe 68000 /BG input. With anydevice in the A2000 Coprocessor Slot that desires the Local Bus, however, the old conflict is going to reappear.For nowwe’ve got twodistinct, unsynchronized potential bus masters, the Coprocessor Slot and the whole encoded Expansion Bus. If the Coprocessor Slot and the Expansion Slot each request the bus at the same time, one Bus Grant, on /BG from the 68000, will be sent back to both devices, and then its a race, and possibly a messy tie, to see who gets to assert /BGACK first.
The next problem is Coprocessor specific. Lets assume for the moment that a Coprocessor device has successfully requested the bus from the 68000. To simplify things, lets assume that its a 68020 processor board, running the AmigaOS, content to neverlet the 68000 back on. It goes romping’ along, with /BR, /BG, and /BGACK each asserted to keep the bus to itself. Now, along comes another device, likeashinynew DMA Hard Disk Controller Card sitting in an Expansion Slot. It wants to DMA something to memory, as you’dexpect. But lo and behold, this 68020 card has the bus tied up; its got all the bus arbitration signals asserted, blocking anyother device from taking overthe bus.
So in this setup, there are three options. The first, of course, is to keep the 68020 on all the time, ignore your DMA Hard Disk, and just run with floppies and non-DMA devices. That’snosolution, so we’ll throwthat one out. Next, we can have the Coprocessor give upthe bus wheneversomeone else wants a DMA, letting the 68000 on for a second, which in turn lets the disk controller have the bus, the DMA takes place, the 68000 goes back on for just

8

long enough to let the Coprocessor takeover. This could work, but first of all its sloppyand forces DMAs to take place in twice the time theywould without the Coprocessor,and in the second place this requires a newDMA protocol to be observed by all the Expansion Bus DMA devices anyway,since theyhav e to have some way of letting the Coprocessor knowthat theywant the bus. This is no good, Expansion Bus things shouldn’tcare which processor is running the local bus. As amodification to this method, the Coprocessor could shut up every so often, letting the 68000 on the bus just to see if anyDMAs are pending. But that’saperformance hit too, and shouldn’t be necessary. The final option with the A2000 setup is to physically remove the 68000 from the motherboard, allowing the Coprocessor to plug in as a complete replacement, bypassing the need for the Coprocessor to request the Local Bus -- it is completely giventhe Local Bus. The problem with this last scheme is that nowthe Coprocessor is no longer a Coprocessor,but a complete replacement processor.There’s no way for the Coprocessor and 68000 to function together in such a system. This may not be important some Coprocessing applications, but it removesthe possibility of some powerful systems.

### 3.4. The B2000 Coprocessor Solution

The B2000 hardware has implemented a more sophisticated Coprocessor system that removesthese problems. The B2000 Coprocessor Slot has a signal called /CBR (Coprocessor Bus Request) as a replacement for /BR, a signal called /CBG (Coprocessor Bus Grant) as a replacement for /BG, and one additional signal, /BOSS, which is also known as Coprocessor Grant Acknowledge.
Under the B2000 system, there are essentially twoways a Coprocessor devices can receive a Local Bus mastership. Both start in the same way.Torequest the bus, the Coprocessor asserts /CBR. Instead of going directly to the 68000, this signal is prioritized and latched along with anyExpansion Slot /BR signals. The /CBR signal has the highest DMA priority.Assuming no other DMAs are currently active,the 68000 will issue a Bus Grant via /BG, which will go to the prioritizer²
and result in /CBG being asserted. At this point, all other DMA requests will be locked out; no other /BGs of anykind will be issued. Following the normal 68000 protocol at this point, the Coprocessor will assert /BGACK when the 68000 is offthe bus, and it will have bus access as before. And as before, it is holding offany further DMAs from the Expansion Bus. Which may be what was wanted; this type of DMA access is very similar to what a normal DMA device from the Expansion Bus would achieve.
There is another way to takeoverthe Bus, however. This starts the same as before, with a /CBR resulting in a /CBG. One the Coprocessor has receivedits Bus Grant, however, itdoes something different. What it does is assert the /BOSS signal instead of /BGACK. This has several immediate effects. First of all, the 68000 sees /BOSS as the same thing as /BGACK, so it stays offthe bus just as if /BGACK had been asserted. Next, the data direction of /CBR and /CBG change on the Coprocessor Bus. The /CBR signal is now an output from the bus control logic, the prioritized and latched combination of all the /BR signals from the Expansion Bus. The /CBG signal is nowaninput going into the bus control logic that will be passed on to the Expansion Bus in response to an Expansion Bus /BR. The bus control logic also holds /BR to the 68000 in a lowstate. The data direction of /CBR and /CBG changes with a change in /BOSS, so the lines that alternately drive /CBR and /CBG on a Coprocessor card should be enabled and disabled with the assertion of /BOSS.
Anyway,what all this means is that, in asserting /BOSS instead of /BGACK, the Coprocessor has the bus, the 68000 is in tri-state, and any of the Expansion Slots may initiate a DMA of the Coprocessor at anytime, directly, according to the normal /BR -> /BG -> /BGACK protocol of the 68000. The Coprocessor can allowthe 68000 back on the bus by negating the /BOSS line. Thus, the Coprocessor can be a real Coprocessor,functioning as the equivalent of the 68000 for all things as far as the whole Amigasystem is concerned.

### 4. Appendix

Here are the four instances of the 86 pin Local Bus, the A500 and A1000 Edge connectors, used for all kinds of expansion on those machines, and the A2000 and B2000 Coprocessor slots.

2The B2000 system does all of its DMA prioritization via the "Buster" custom bus controller chip.

9

PIN | A500 | A1000 | A2000 | B2000 | Function
1 | X | X | X | X | Ground
2 | X | X | X | X | Ground
3 | X | X | X | X | Ground
4 | X | X | X | X | Ground
5 | X | X | X | X | +5VDC
6 | X | X | X | X | +5VDC
7 | X | X | X | | NoConnect
| | | | X | 7MClock
8 | X | X | X | X | -5VDC
9 | X | X | | | No Connect
| | | X | X | 28MHz Clock
10 | X | X | X | X | +12VDC
11 | X | X | X | | NoConnect
| | | | X | /COPCFG (Configuration Out)
12 | X | X | X | X | CONFIG IN, Grounded
13 | X | X | X | X | Ground
14 | X | X | X | X | /C3 Clock
15 | X | X | X | X | CDAC Clock
16 | X | X | X | X | /C1 Clock
17 | X | X | X | X | /OVR
18 | X | X | X | X | XRDY
19 | X | X | X | X | /INT2
20 | | X | | | /PALOPE
| X | | X | | No Connect
| | | | X | /BOSS
21 | X | X | X | X | A5
22 | X | X | X | X | /INT6
23 | X | X | X | X | A6
24 | X | X | X | X | A4
25 | X | X | X | X | Ground
26 | X | X | X | X | A3
27 | X | X | X | X | A2
28 | X | X | X | X | A7
29 | X | X | X | X | A1
30 | X | X | X | X | A8
31 | X | X | X | X | FC0
32 | X | X | X | X | A9
33 | X | X | X | X | FC1
34 | X | X | X | X | A10
35 | X | X | X | X | FC2
36 | X | X | X | X | A11
37 | X | X | X | X | Ground
38 | X | X | X | X | A12
39 | X | X | X | X | A13
40 | X | X | X | X | /IPL0
41 | X | X | X | X | A14
42 | X | X | X | X | /IPL1
43 | X | X | X | X | A15
44 | X | X | X | X | /IPL2

10

45 | X | X | X | X | A16
46 | X | X | X | X | /BEER
47 | X | X | X | X | A17
48 | X | X | X | X | /VPA
49 | X | X | X | X | Ground
50 | X | X | X | X | E Clock
51 | X | X | X | X | /VMA
52 | X | X | X | X | A18
53 | X | X | X | X | /RST
54 | X | X | X | X | A19
55 | X | X | X | X | /HLT
56 | X | X | X | X | A20
57 | X | X | X | X | A22
58 | X | X | X | X | A21
59 | X | X | X | X | A23
60 | X | X | X | | /BR
| | | | X | /CBR
61 | X | X | X | X | Ground
62 | X | X | X | X | /BGACK
63 | X | X | X | X | D15
64 | X | X | X | | /BG
| | | | X | /CBG
65 | X | X | X | X | D14
66 | X | X | X | X | /DTACK
67 | X | X | X | X | D13
68 | X | X | X | X | R/W
69 | X | X | X | X | D12
70 | X | X | X | X | /LDS
71 | X | X | X | X | D11
72 | X | X | X | X | /UDS
73 | X | X | X | X | Ground
74 | X | X | X | X | /AS
75 | X | X | X | X | D0
76 | X | X | X | X | D10
77 | X | X | X | X | D1
78 | X | X | X | X | D9
79 | X | X | X | X | D2
80 | X | X | X | X | D8
81 | X | X | X | X | D3
82 | X | X | X | X | D7
83 | X | X | X | X | D4
84 | X | X | X | X | D6
85 | X | X | X | X | Ground
86 | X | X | X | X | D5

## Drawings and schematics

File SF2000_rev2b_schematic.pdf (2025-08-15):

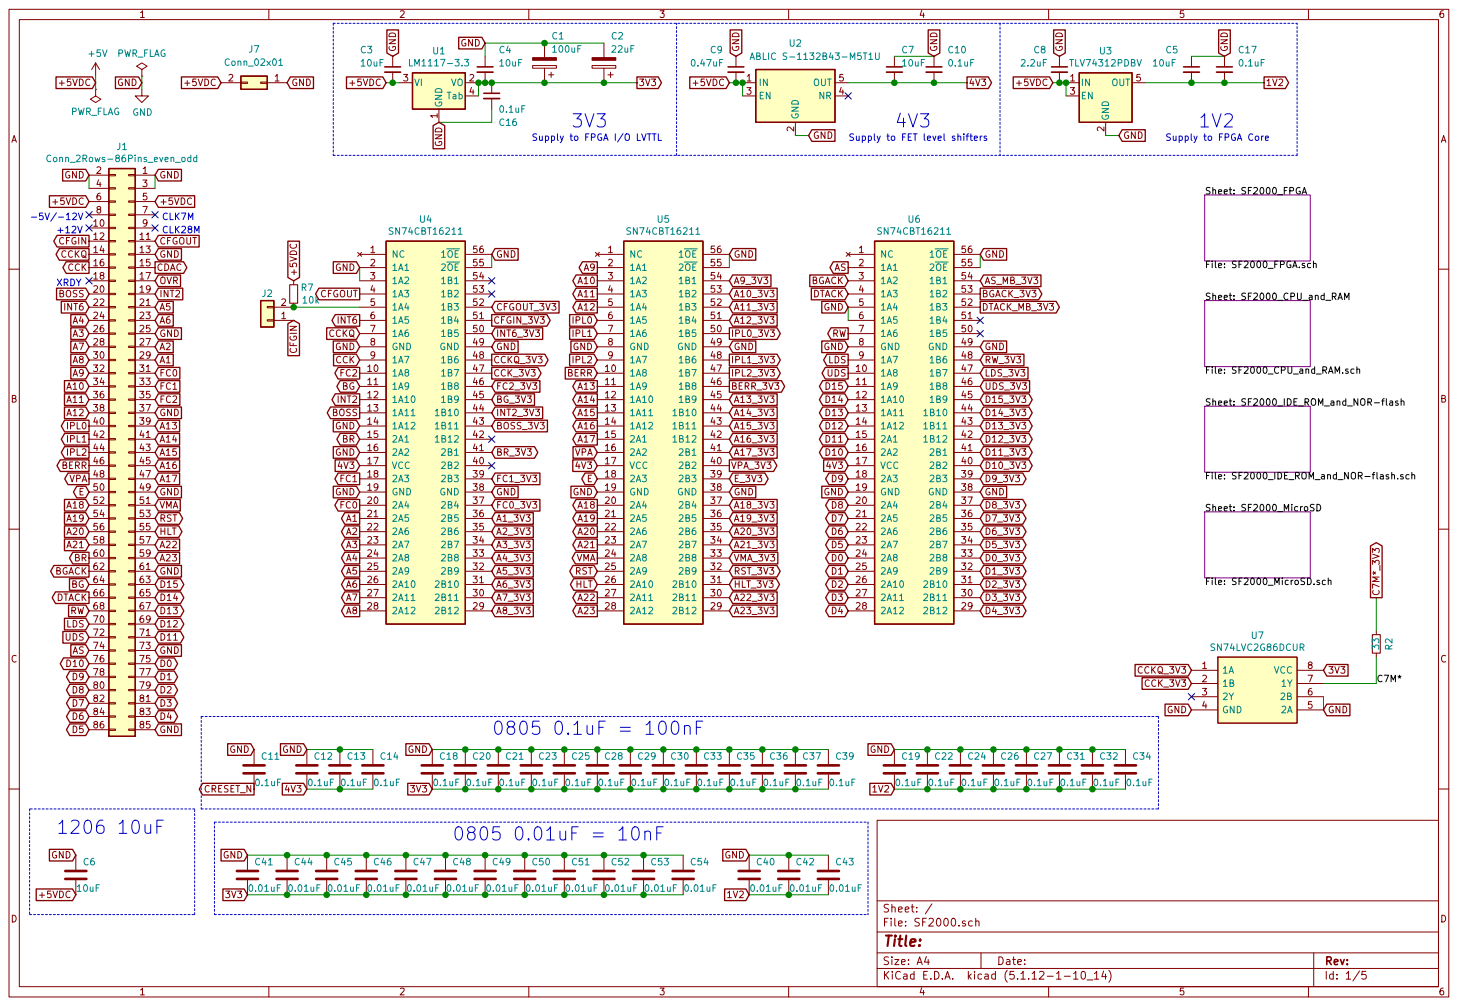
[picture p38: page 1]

2 EN 3 NR 4 OUT 5 U2 ABLIC S-1132B43-M5T1U C5

File: SF2000_MicroSD.sch Sheet: SF2000_IDE_ROM_and_NOR-flash File: SF2000_IDE_ROM_and_NOR-flash.sch Sheet: SF2000_CPU_and_RAM

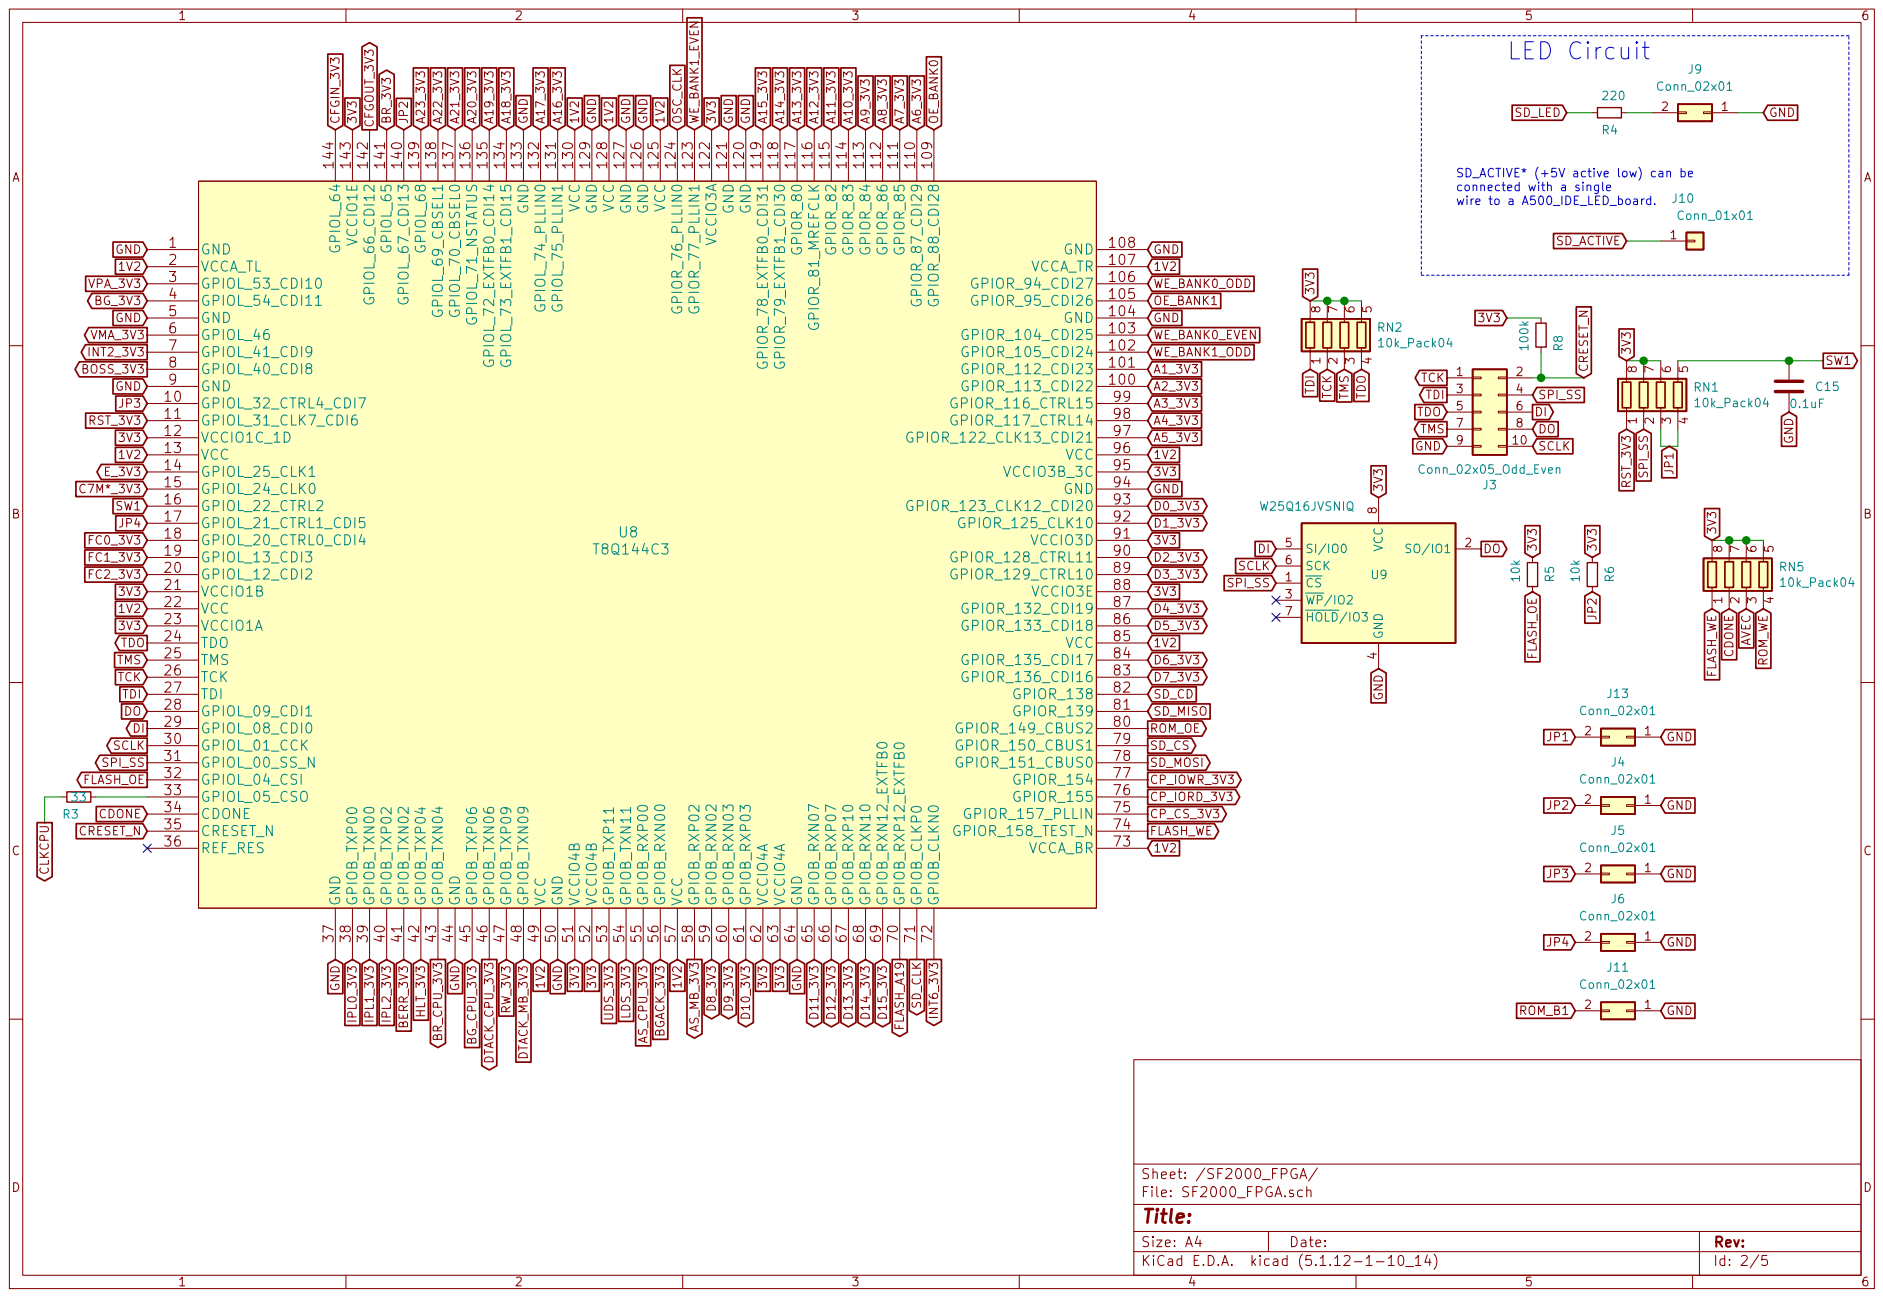
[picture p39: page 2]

connected with a single wire to a A500_IDE_LED_board. LED Circuit

4 SI/IO0 5 SCK 6 HOLD/IO3 7 VCC

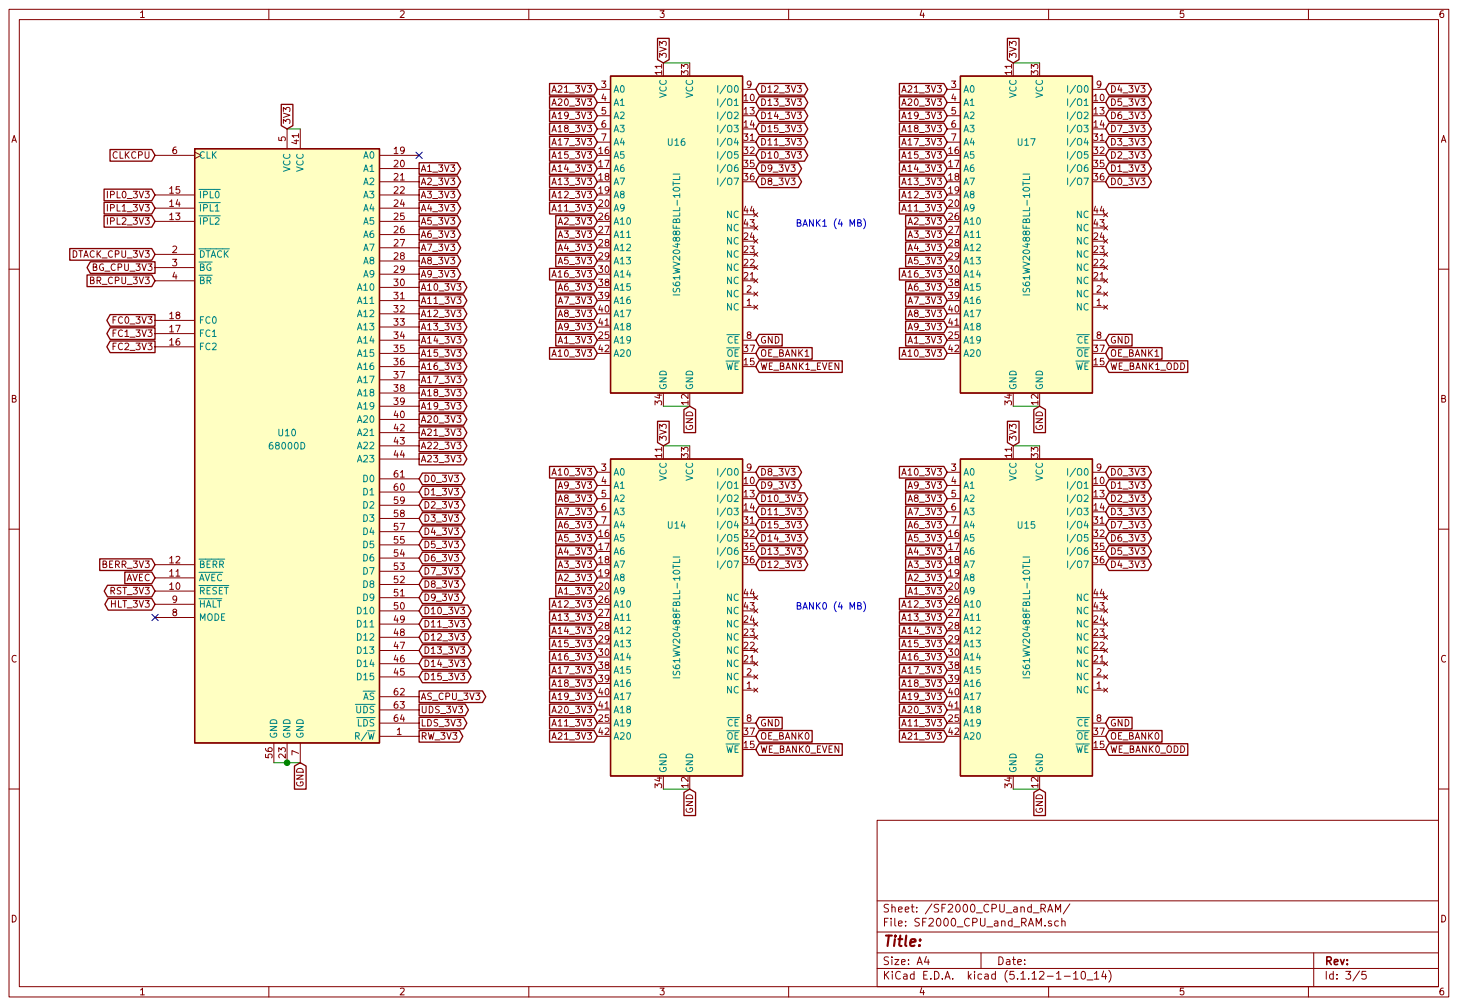
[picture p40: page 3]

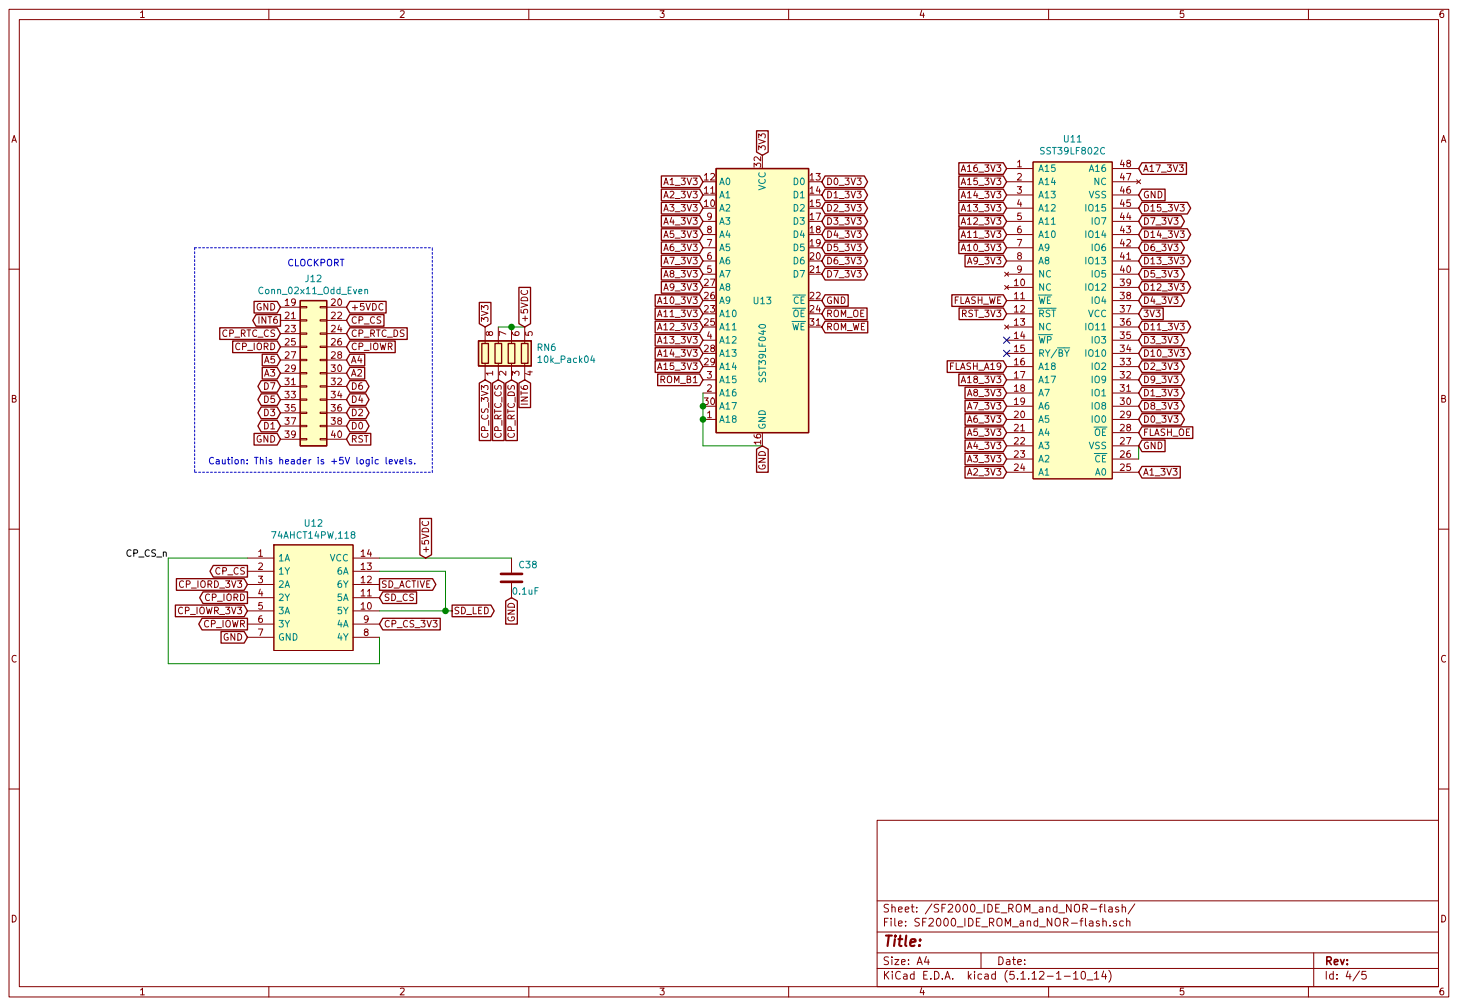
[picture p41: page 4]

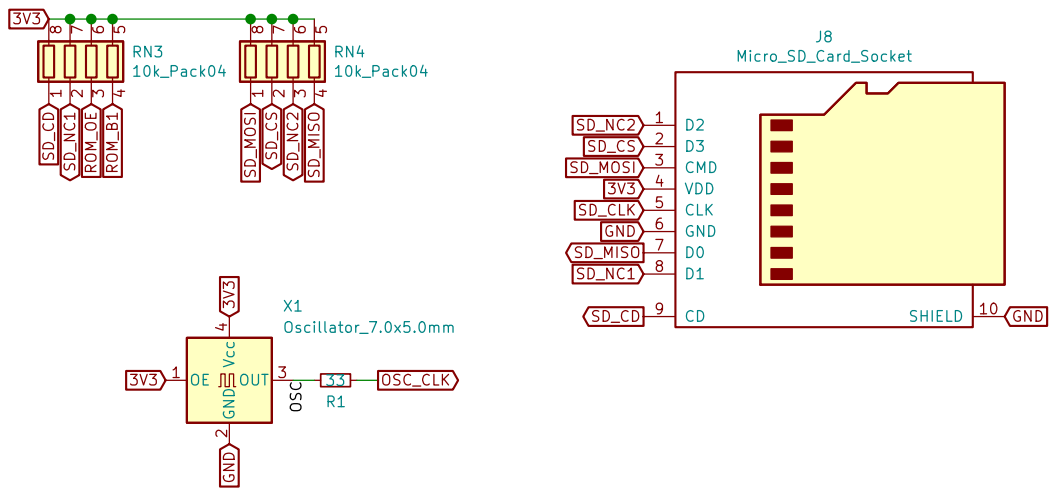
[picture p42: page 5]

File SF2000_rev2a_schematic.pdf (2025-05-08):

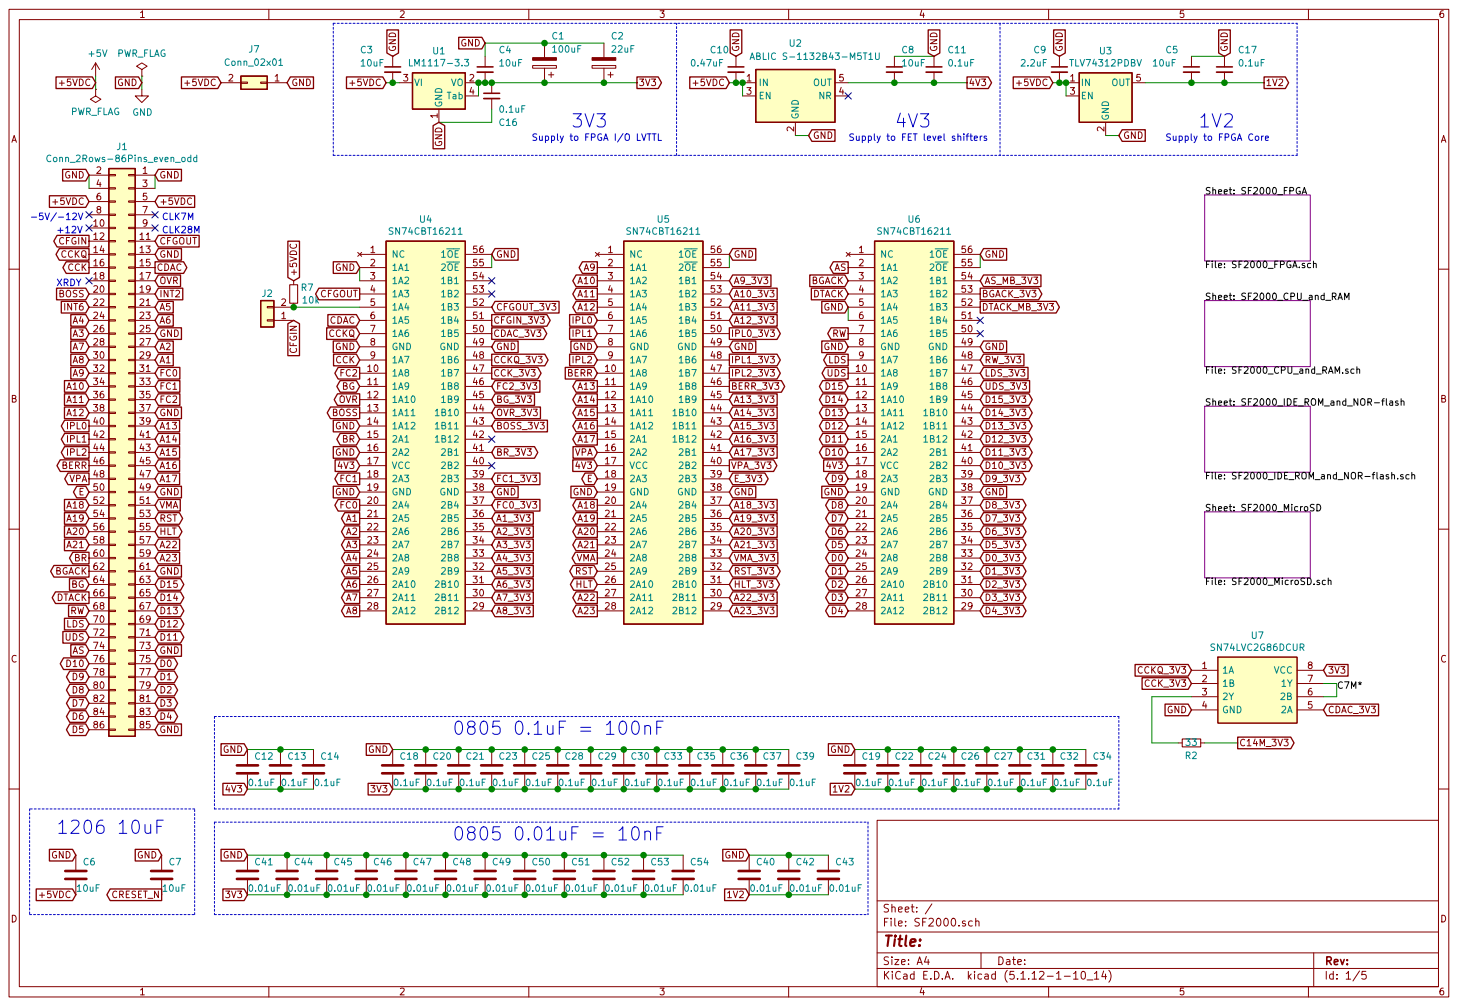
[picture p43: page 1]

2 EN 3 NR 4 OUT 5 U2 ABLIC S-1132B43-M5T1U C5

File: SF2000_MicroSD.sch Sheet: SF2000_IDE_ROM_and_NOR-flash File: SF2000_IDE_ROM_and_NOR-flash.sch Sheet: SF2000_CPU_and_RAM

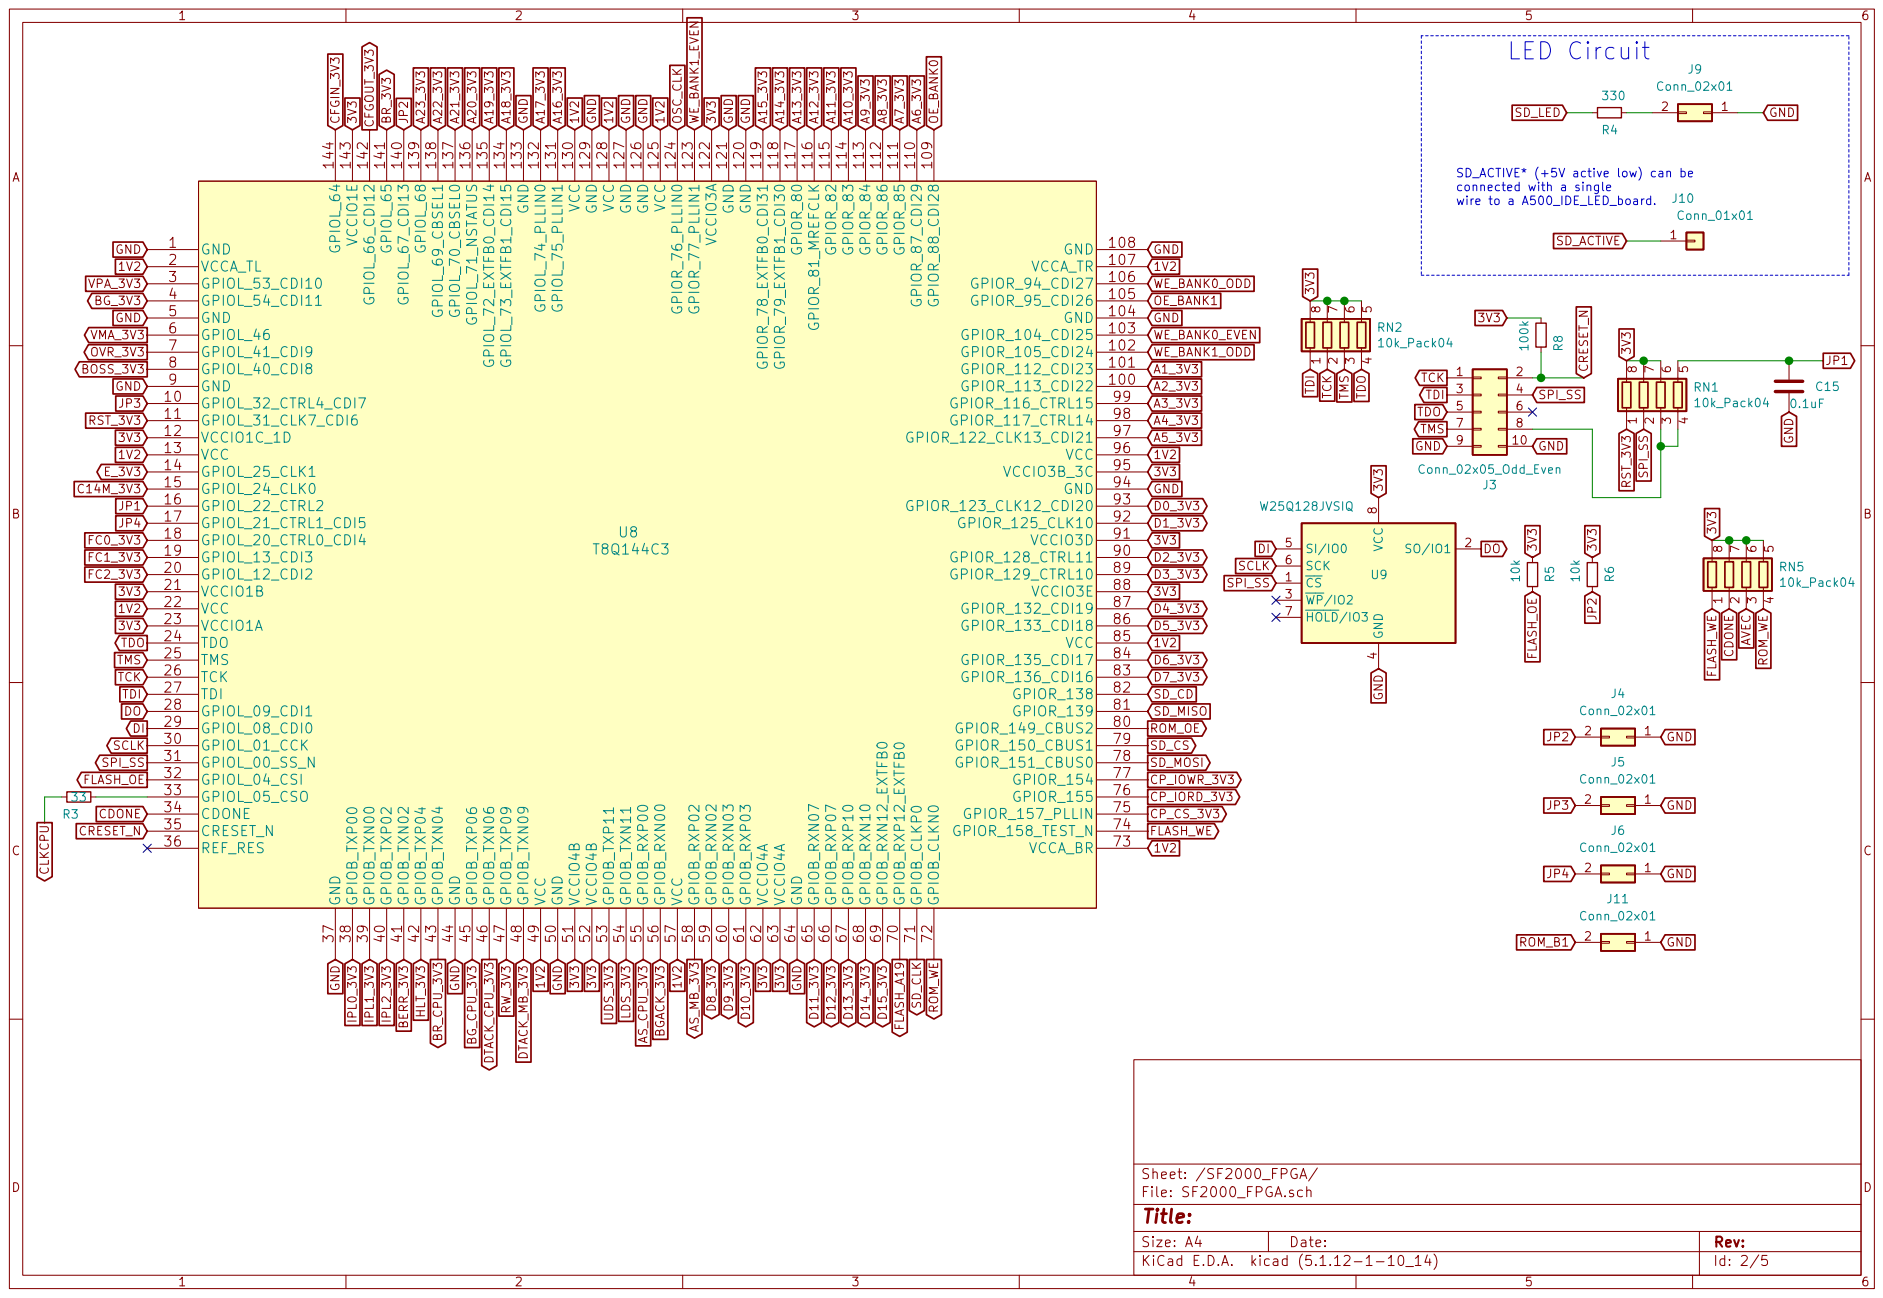
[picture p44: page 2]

SD_ACTIVE* (+5V active low) can be
connected with a single wire to a A500_IDE_LED_board.

4 SI/IO0 5 SCK 6 HOLD/IO3 7 VCC




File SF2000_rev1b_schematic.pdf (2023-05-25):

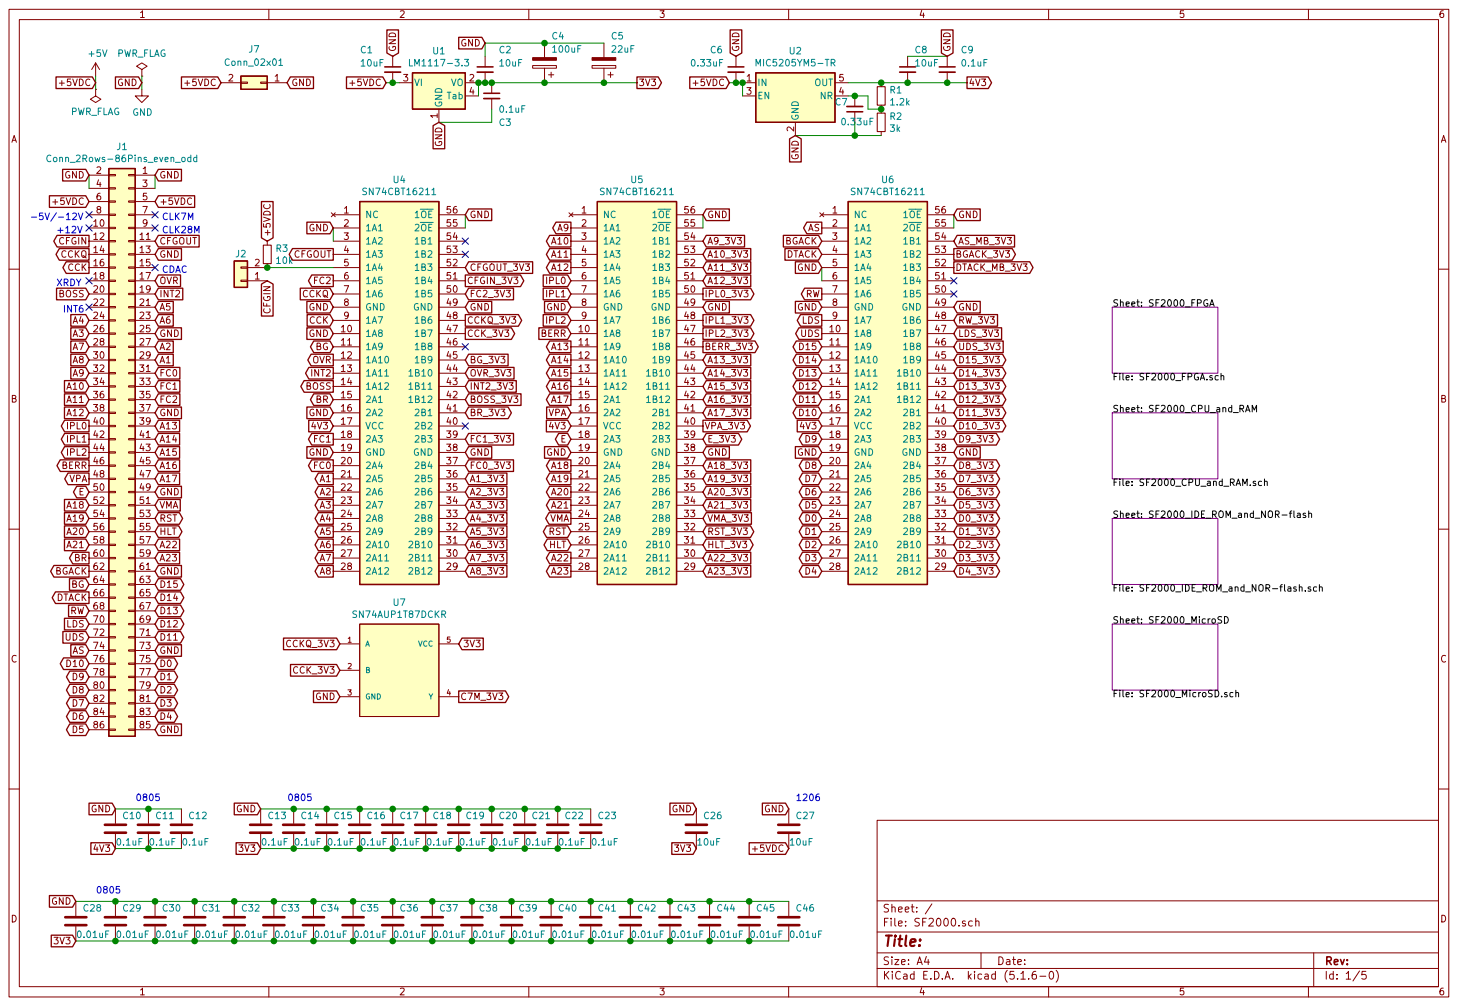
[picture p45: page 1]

2 EN 3 NR 4 OUT 5 U2 MIC5205YM5-TR

File: SF2000_FPGA.sch Sheet: SF2000_IDE_ROM_and_NOR-flash File: SF2000_IDE_ROM_and_NOR-flash.sch Sheet: SF2000_MicroSD

Id: 1/5 Title: File: SF2000.sch Sheet: /

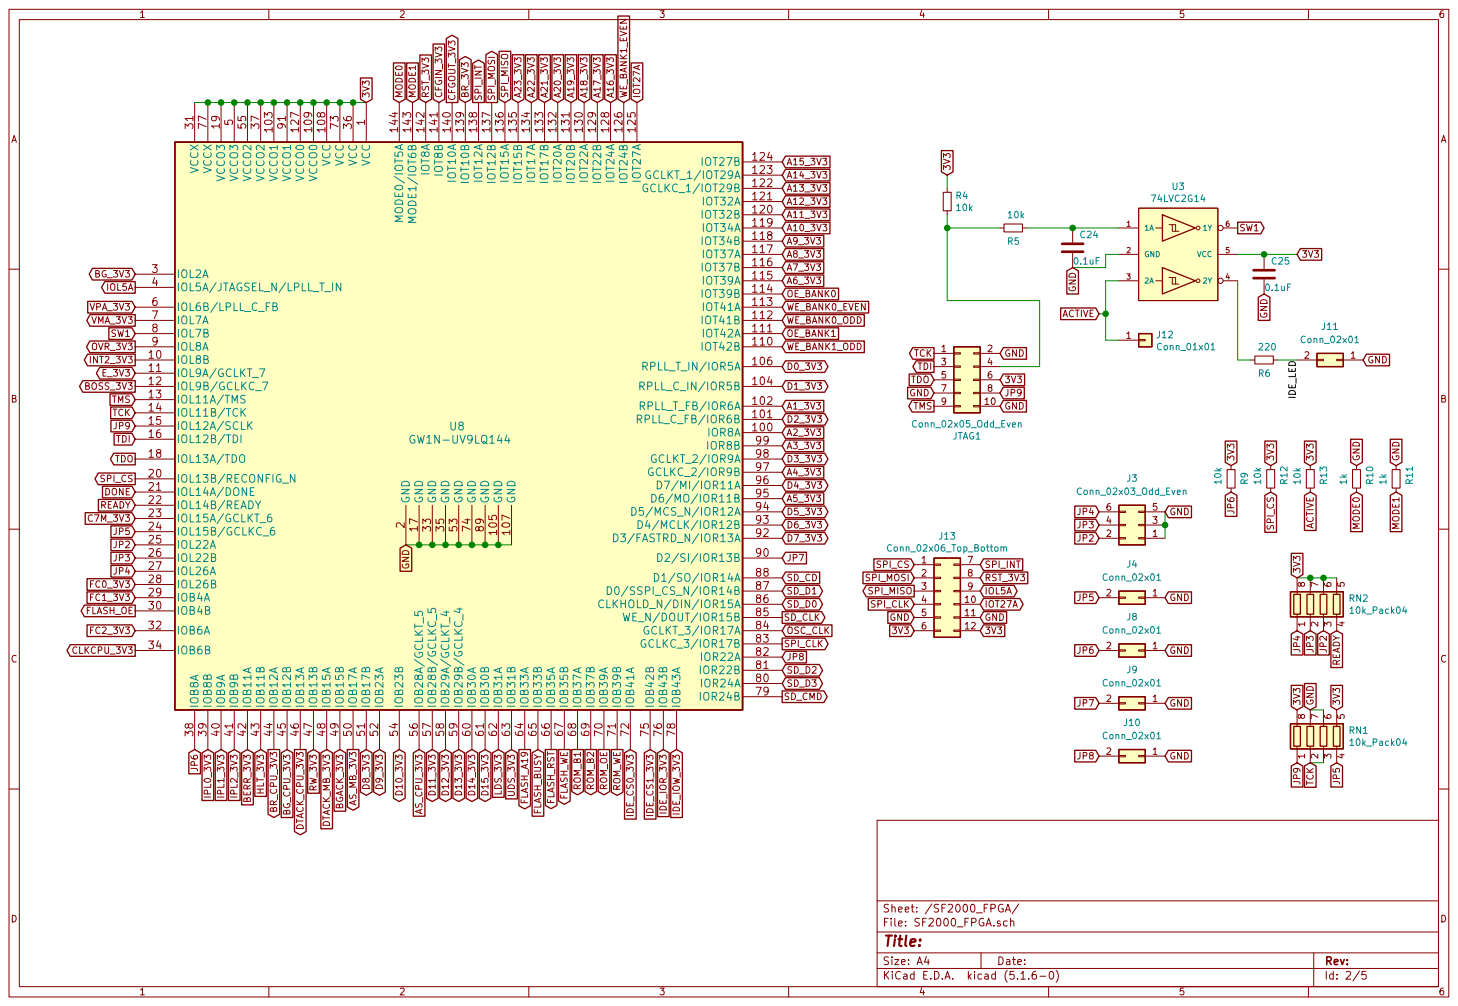
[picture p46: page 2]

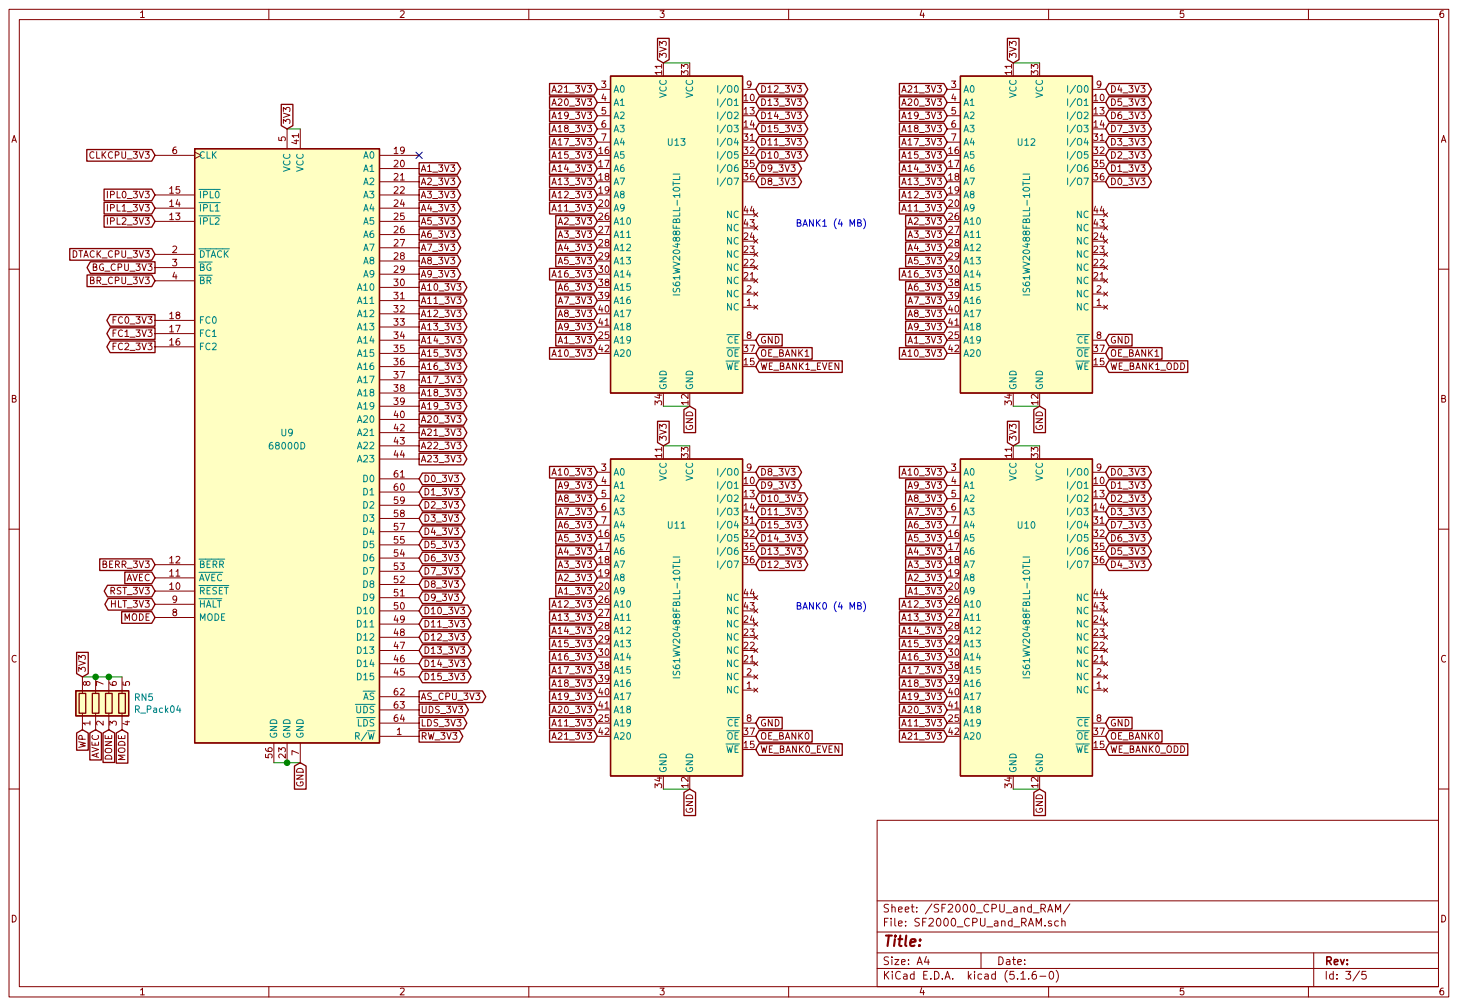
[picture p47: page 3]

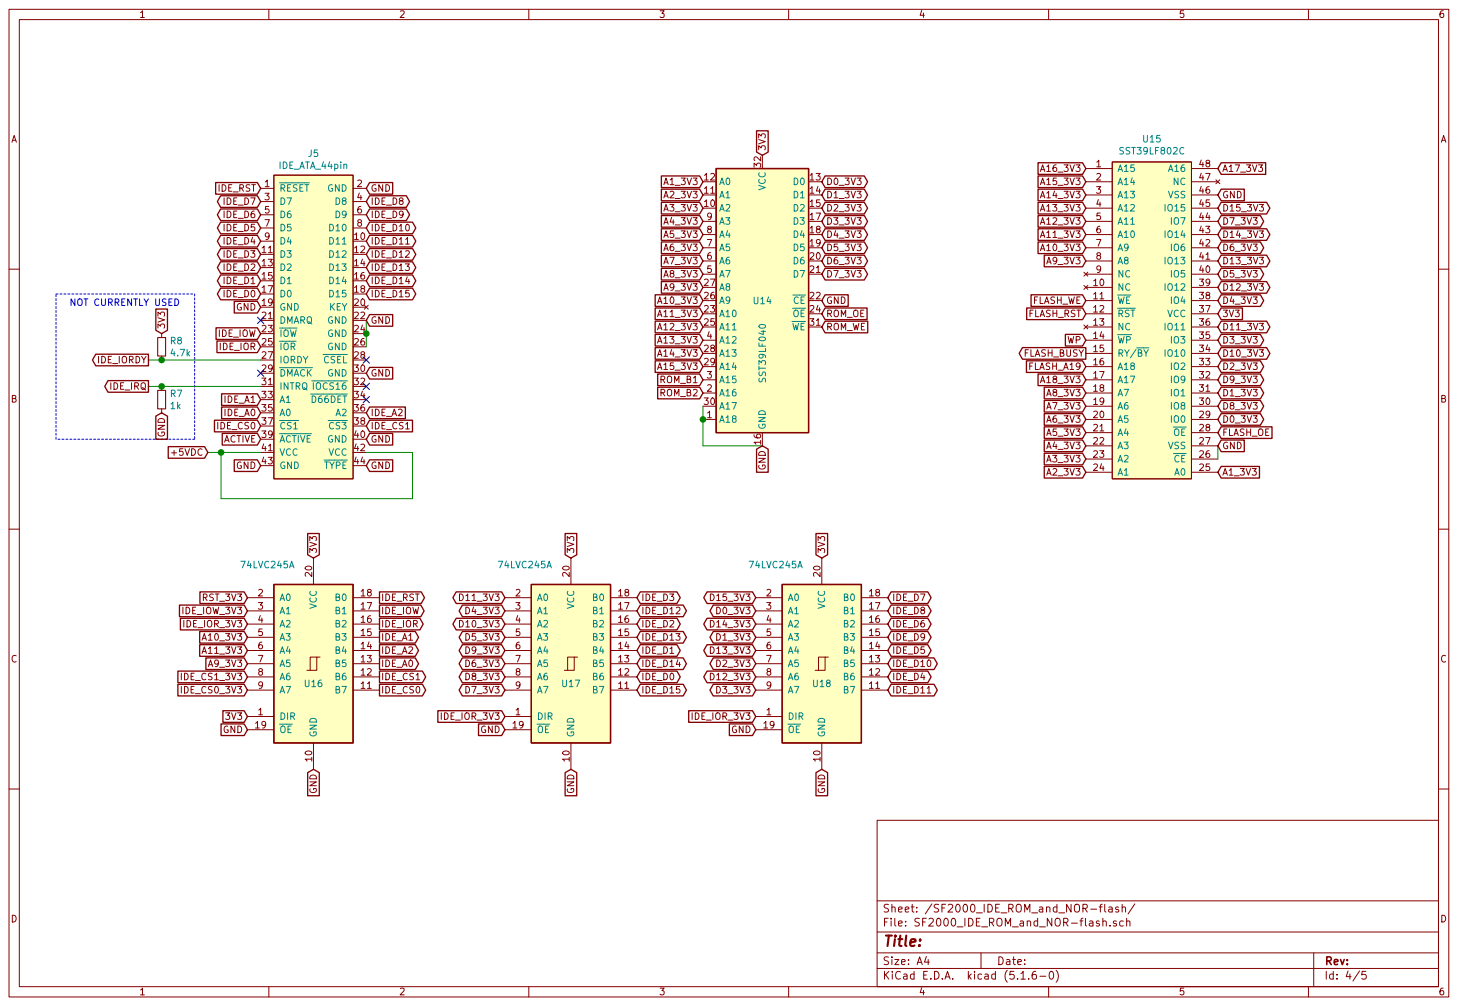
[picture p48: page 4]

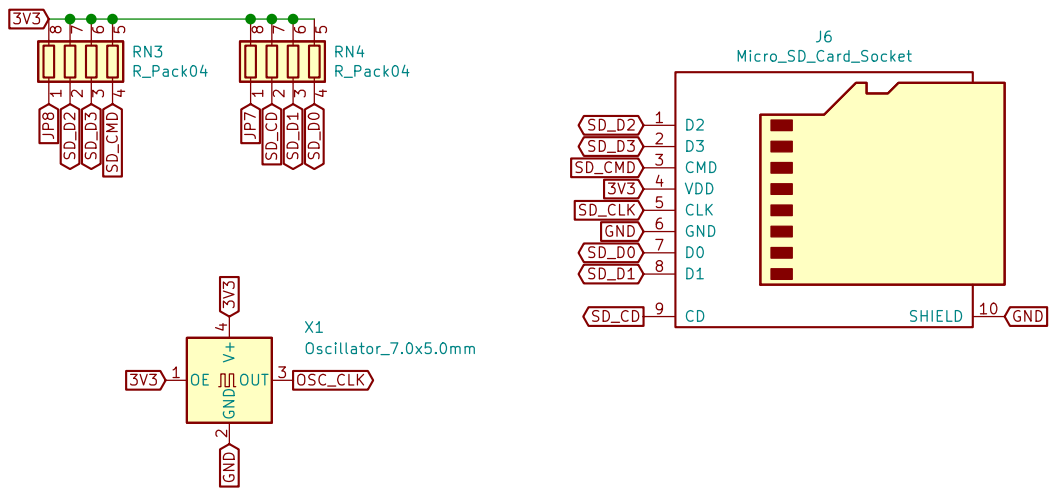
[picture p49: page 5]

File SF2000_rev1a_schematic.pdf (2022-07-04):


File: SF2000_CPU_and_RAM.sch Sheet: SF2000_IDE_ROM_and_NOR-flash File: SF2000_IDE_ROM_and_NOR-flash.sch Sheet: SF2000_MicroSD

Id: 1/5 Title: File: SF2000.sch Sheet: /





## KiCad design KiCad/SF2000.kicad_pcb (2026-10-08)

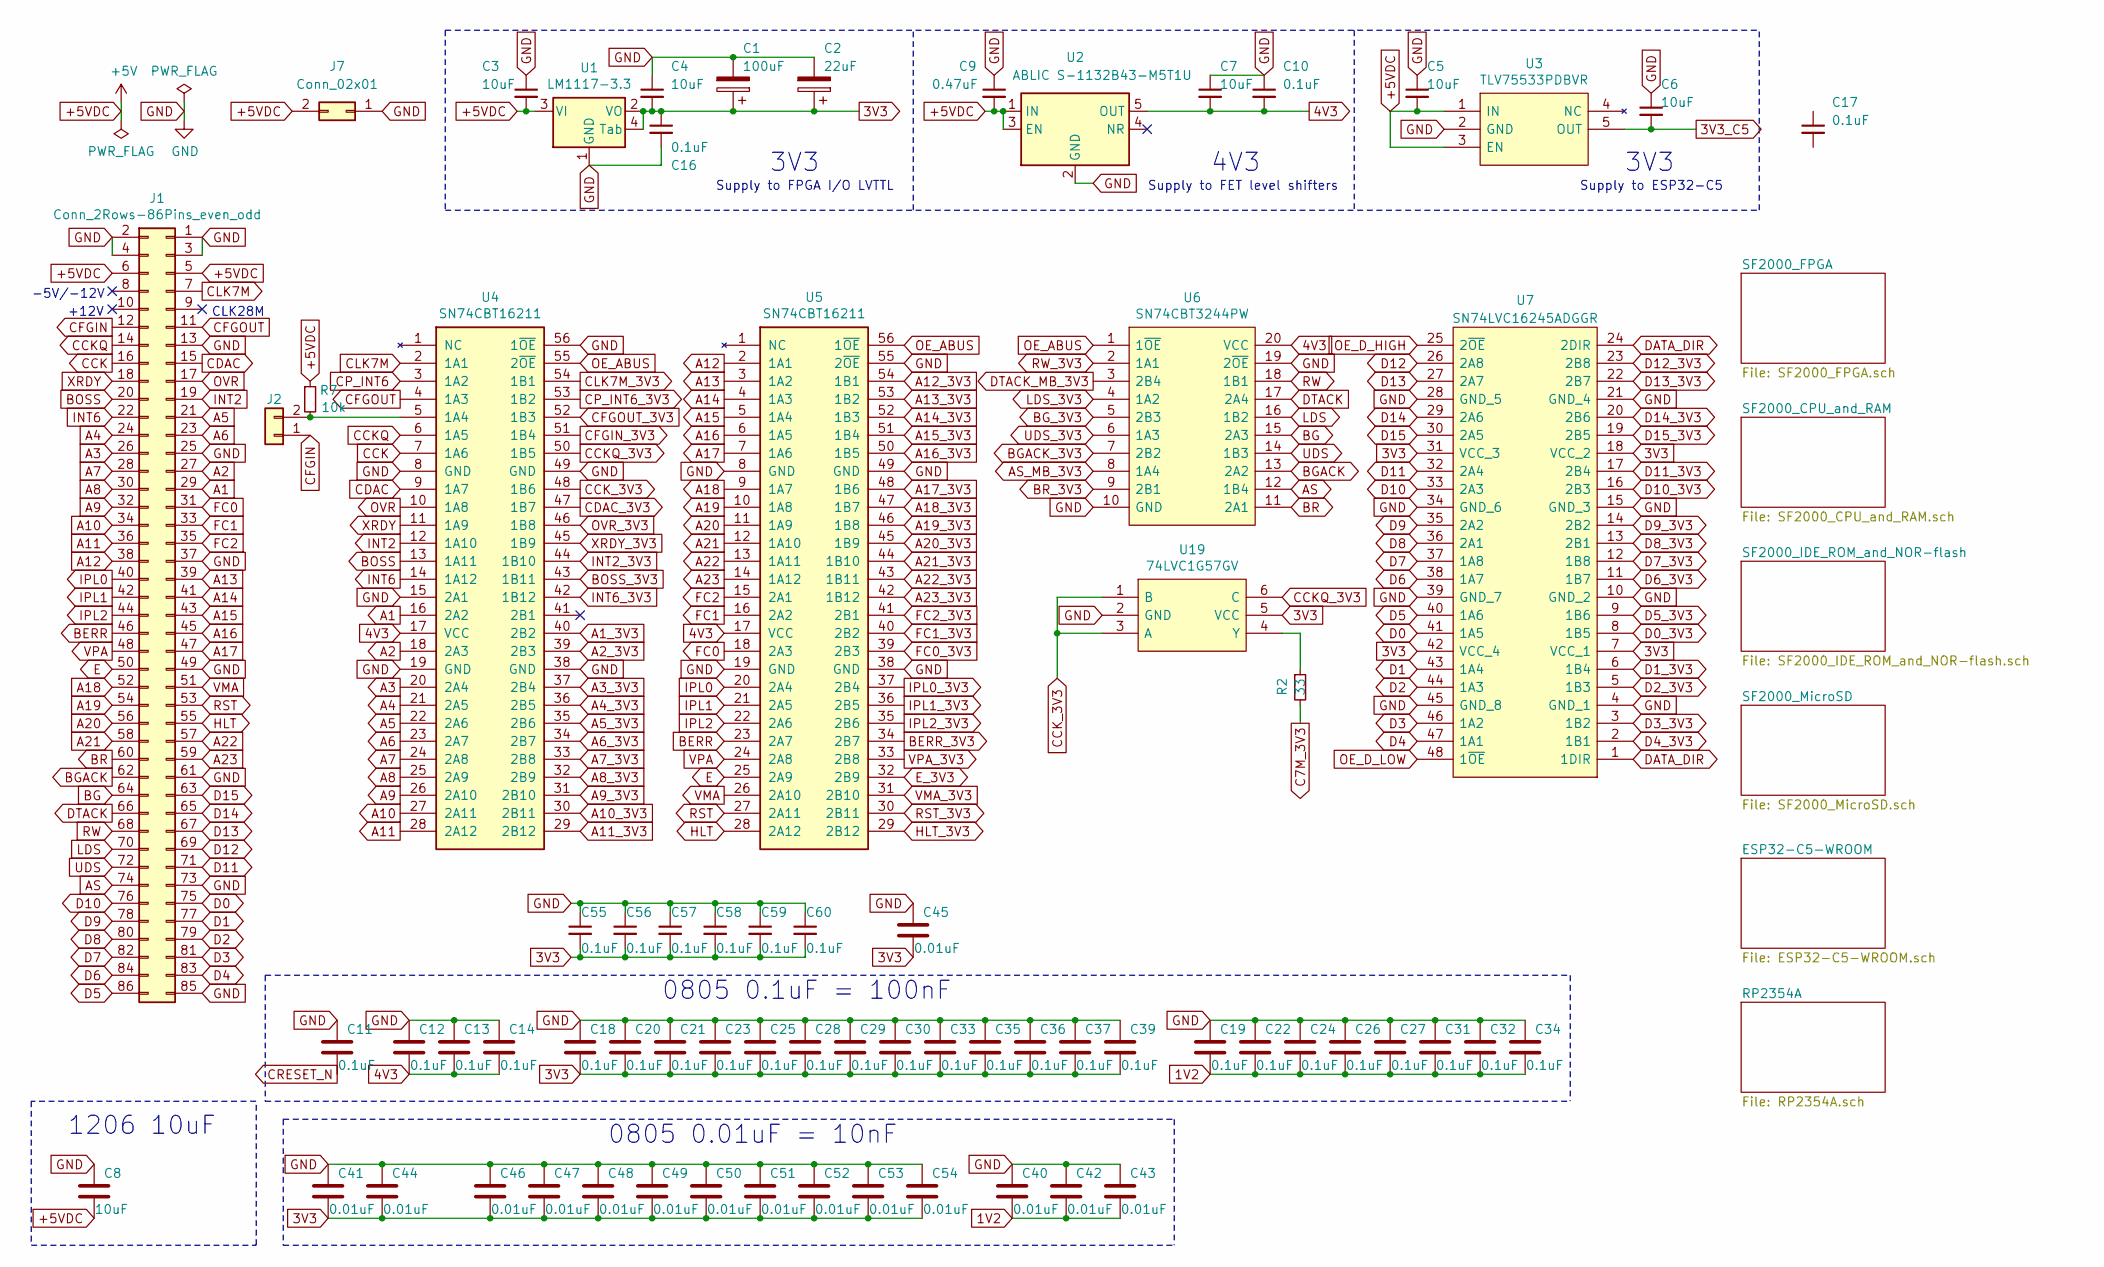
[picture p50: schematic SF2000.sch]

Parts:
C1: 100uF; CP_Elec_6.3x7.7
C2: 22uF; CP_Elec_5x5.8
C3, C4, C5, C7, C8: 10uF; C_1206_3216Metric_Pad1.42x1.75mm_HandSolder
C6: 10uF; C_1206_3216Metric_Pad1.33x1.80mm_HandSolder
C9: 0.47uF; C_1206_3216Metric_Pad1.42x1.75mm_HandSolder
C10, C12, C13, C14, C16, C18, C19, C20, C21, C22, C23, C24, C25, C26, C27, C28, C29, C30, C35, C36, C37, C39: 0.1uF; C_0805_2012Metric_Pad1.15x1.40mm_HandSolder
C11, C17, C31, C32, C33, C34: 0.1uF; C_0805_2012Metric_Pad1.18x1.45mm_HandSolder
C40, C44: 0.01uF; C_0805_2012Metric_Pad1.18x1.45mm_HandSolder
C41, C42, C43, C46, C47, C48, C49, C50, C51, C52, C53, C54: 0.01uF; C_0805_2012Metric_Pad1.15x1.40mm_HandSolder
C45: 0.01uF; C_0603_1608Metric_Pad1.08x0.95mm_HandSolder
C55, C56, C57, C58, C59, C60: 0.1uF; C_0402_1005Metric_Pad0.74x0.62mm_HandSolder
J1: Conn_2Rows-86Pins_even_odd; A500_86pin_Edge_Connector
J2: Conn_01x02; PinHeader_1x02_P2.54mm_Vertical
J7: Conn_02x01; PinHeader_2x01_P2.54mm_Vertical
R2: 33; R_0603_1608Metric_Pad0.98x0.95mm_HandSolder
R7: 10k; R_0805_2012Metric_Pad1.15x1.40mm_HandSolder
U1: LM1117-3.3; SOT-223
U2: ABLIC S-1132B43-M5T1U; SOT-23-5
U3: TLV75533PDBVR; SOT-23-5_HandSoldering
U4, U5: SN74CBT16211; TSSOP-56_6.1x14mm_P0.5mm
U6: SN74CBT3244PW; TSSOP-20_4.4x6.5mm_P0.65mm
U7: SN74LVC16245ADGGR; TSSOP-48_6.1x12.5mm_P0.5mm
U19: 74LVC1G57GV; TSOP-6_1.65x3.05mm_P0.95mm

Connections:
1V2: C19.2, C22.2, C24.2, C26.2, C27.2, C31.2, C32.2, C34.2, C40.2, C42.2, C43.2
3V3: C1.1, C2.1, C4.2, C16.1, C18.2, C20.2, C21.2, C23.2, C25.2, C28.2, C29.2, C30.2, C33.2, C35.2, C36.2, C37.2, C39.2, C41.2, C44.2, C45.2, C46.2, C47.2, C48.2, C49.2, C50.2, C51.2, C52.2, C53.2, C54.2, C55.2, C56.2, C57.2, C58.2, C59.2, C60.2, U1.2 (VO), U1.4 (Tab), U7.7 (VCC_1), U7.18 (VCC_2), U7.31 (VCC_3), U7.42 (VCC_4), U19.5 (VCC); also elsewhere on the board
3V3_C5: C6.2, U3.5 (OUT); also elsewhere on the board
4V3: C7.2, C10.2, C12.2, C13.2, C14.2, U2.5 (OUT), U4.17 (VCC), U5.17 (VCC), U6.20 (VCC)
+5VDC: C3.2, C5.2, C8.2, C9.2, J1.5, J1.6, J7.2, R7.1, U1.3 (VI), U2.1 (IN), U2.3 (EN), U3.1 (IN), U3.3 (EN); also elsewhere on the board
A1: J1.29, U4.16 (2A2)
A1_3V3: U4.40 (2B2); also elsewhere on the board
A2: J1.27, U4.18 (2A3)
A2_3V3: U4.39 (2B3); also elsewhere on the board
A3: J1.26, U4.20 (2A4)
A3_3V3: U4.37 (2B4); also elsewhere on the board
A4: J1.24, U4.21 (2A5)
A4_3V3: U4.36 (2B5); also elsewhere on the board
A5: J1.21, U4.22 (2A6)
A5_3V3: U4.35 (2B6); also elsewhere on the board
A6: J1.23, U4.23 (2A7)
A6_3V3: U4.34 (2B7); also elsewhere on the board
A7: J1.28, U4.24 (2A8)
A7_3V3: U4.33 (2B8); also elsewhere on the board
A8: J1.30, U4.25 (2A9)
A8_3V3: U4.32 (2B9); also elsewhere on the board
A9: J1.32, U4.26 (2A10)
A9_3V3: U4.31 (2B10); also elsewhere on the board
A10: J1.34, U4.27 (2A11)
A10_3V3: U4.30 (2B11); also elsewhere on the board
A11: J1.36, U4.28 (2A12)
A11_3V3: U4.29 (2B12); also elsewhere on the board
A12: J1.38, U5.2 (1A1)
A12_3V3: U5.54 (1B1); also elsewhere on the board
A13: J1.39, U5.3 (1A2)
A13_3V3: U5.53 (1B2); also elsewhere on the board
A14: J1.41, U5.4 (1A3)
A14_3V3: U5.52 (1B3); also elsewhere on the board
A15: J1.43, U5.5 (1A4)
A15_3V3: U5.51 (1B4); also elsewhere on the board
A16: J1.45, U5.6 (1A5)
A16_3V3: U5.50 (1B5); also elsewhere on the board
A17: J1.47, U5.7 (1A6)
A17_3V3: U5.48 (1B6); also elsewhere on the board
A18: J1.52, U5.9 (1A7)
A18_3V3: U5.47 (1B7); also elsewhere on the board
A19: J1.54, U5.10 (1A8)
A19_3V3: U5.46 (1B8); also elsewhere on the board
A20: J1.56, U5.11 (1A9)
A20_3V3: U5.45 (1B9); also elsewhere on the board
A21: J1.58, U5.12 (1A10)
A21_3V3: U5.44 (1B10); also elsewhere on the board
A22: J1.57, U5.13 (1A11)
A22_3V3: U5.43 (1B11); also elsewhere on the board
A23: J1.59, U5.14 (1A12)
A23_3V3: U5.42 (1B12); also elsewhere on the board
AS: J1.74, U6.12 (1B4)
AS_MB_3V3: U6.8 (1A4); also elsewhere on the board
BERR: J1.46, U5.23 (2A7)
BERR_3V3: U5.34 (2B7); also elsewhere on the board
BG: J1.64, U6.15 (2A3)
BGACK: J1.62, U6.13 (2A2)
BGACK_3V3: U6.7 (2B2); also elsewhere on the board
BG_3V3: U6.5 (2B3); also elsewhere on the board
BOSS: J1.20, U4.13 (1A11)
BOSS_3V3: U4.43 (1B11); also elsewhere on the board
BR: J1.60, U6.11 (2A1)
BR_3V3: U6.9 (2B1); also elsewhere on the board
C7M_3V3: R2.2; also elsewhere on the board
CCK: J1.16, U4.7 (1A6)
CCKQ: J1.14, U4.6 (1A5)
CCKQ_3V3: U4.50 (1B5), U19.6 (C)
CCK_3V3: U4.48 (1B6), U19.1 (B), U19.3 (A)
CDAC: J1.15, U4.9 (1A7)
CDAC_3V3: U4.47 (1B7); also elsewhere on the board
CFGIN: J1.12, J2.1
CFGIN_3V3: U4.51 (1B4); also elsewhere on the board
CFGOUT: J1.11, U4.4 (1A3)
CFGOUT_3V3: U4.52 (1B3); also elsewhere on the board
CLK7M: J1.7, U4.2 (1A1)
CLK7M_3V3: U4.54 (1B1); also elsewhere on the board
CP_INT6: U4.3 (1A2); also elsewhere on the board
CP_INT6_3V3: U4.53 (1B2); also elsewhere on the board
CRESET_N: C11.2
D0: J1.75, U7.41 (1A5)
D0_3V3: U7.8 (1B5); also elsewhere on the board
D1: J1.77, U7.43 (1A4)
D1_3V3: U7.6 (1B4); also elsewhere on the board
D2: J1.79, U7.44 (1A3)
D2_3V3: U7.5 (1B3); also elsewhere on the board
D3: J1.81, U7.46 (1A2)
D3_3V3: U7.3 (1B2); also elsewhere on the board
D4: J1.83, U7.47 (1A1)
D4_3V3: U7.2 (1B1); also elsewhere on the board
D5: J1.86, U7.40 (1A6)
D5_3V3: U7.9 (1B6); also elsewhere on the board
D6: J1.84, U7.38 (1A7)
D6_3V3: U7.11 (1B7); also elsewhere on the board
D7: J1.82, U7.37 (1A8)
D7_3V3: U7.12 (1B8); also elsewhere on the board
D8: J1.80, U7.36 (2A1)
D8_3V3: U7.13 (2B1); also elsewhere on the board
D9: J1.78, U7.35 (2A2)
D9_3V3: U7.14 (2B2); also elsewhere on the board
D10: J1.76, U7.33 (2A3)
D10_3V3: U7.16 (2B3); also elsewhere on the board
D11: J1.71, U7.32 (2A4)
D11_3V3: U7.17 (2B4); also elsewhere on the board
D12: J1.69, U7.26 (2A8)
D12_3V3: U7.23 (2B8); also elsewhere on the board
D13: J1.67, U7.27 (2A7)
D13_3V3: U7.22 (2B7); also elsewhere on the board
D14: J1.65, U7.29 (2A6)
D14_3V3: U7.20 (2B6); also elsewhere on the board
D15: J1.63, U7.30 (2A5)
D15_3V3: U7.19 (2B5); also elsewhere on the board
DATA_DIR: U7.1 (1DIR), U7.24 (2DIR); also elsewhere on the board
DTACK: J1.66, U6.17 (2A4)
DTACK_MB_3V3: U6.3 (2B4); also elsewhere on the board
E: J1.50, U5.25 (2A9)
E_3V3: U5.32 (2B9); also elsewhere on the board
FC0: J1.31, U5.18 (2A3)
FC0_3V3: U5.39 (2B3); also elsewhere on the board
FC1: J1.33, U5.16 (2A2)
FC1_3V3: U5.40 (2B2); also elsewhere on the board
FC2: J1.35, U5.15 (2A1)
FC2_3V3: U5.41 (2B1); also elsewhere on the board
GND: C1.2, C2.2, C3.1, C4.1, C5.1, C6.1, C7.1, C8.1, C9.1, C10.1, C11.1, C12.1, C13.1, C14.1, C16.2, C18.1, C19.1, C20.1, C21.1, C22.1, C23.1, C24.1, C25.1, C26.1, C27.1, C28.1, C29.1, C30.1, C31.1, C32.1, C33.1, C34.1, C35.1, C36.1, C37.1, C39.1, C40.1, C41.1, C42.1, C43.1, C44.1, C45.1, C46.1, C47.1, C48.1, C49.1, C50.1, C51.1, C52.1, C53.1, C54.1, C55.1, C56.1, C57.1, C58.1, C59.1, C60.1, J1.1, J1.2, J1.3, J1.4, J1.13, J1.25, J1.37, J1.49, J1.61, J1.73, J1.85, J7.1, U1.1 (GND), U2.2 (GND), U3.2 (GND), U4.8 (GND), U4.15 (2A1), U4.19 (GND), U4.38 (GND), U4.49 (GND), U4.56 (1~OE), U5.8 (GND), U5.19 (GND), U5.38 (GND), U5.49 (GND), U5.55 (2~OE), U6.10 (GND), U6.19 (2~OE), U7.4 (GND_1), U7.10 (GND_2), U7.15 (GND_3), U7.21 (GND_4), U7.28 (GND_5), U7.34 (GND_6), U7.39 (GND_7), U7.45 (GND_8), U19.2 (GND); also elsewhere on the board
HLT: J1.55, U5.28 (2A12)
HLT_3V3: U5.29 (2B12); also elsewhere on the board
INT2: J1.19, U4.12 (1A10)
INT2_3V3: U4.44 (1B10); also elsewhere on the board
INT6: J1.22, U4.14 (1A12)
INT6_3V3: U4.42 (1B12); also elsewhere on the board
IPL0: J1.40, U5.20 (2A4)
IPL0_3V3: U5.37 (2B4); also elsewhere on the board
IPL1: J1.42, U5.21 (2A5)
IPL1_3V3: U5.36 (2B5); also elsewhere on the board
IPL2: J1.44, U5.22 (2A6)
IPL2_3V3: U5.35 (2B6); also elsewhere on the board
LDS: J1.70, U6.16 (1B2)
LDS_3V3: U6.4 (1A2); also elsewhere on the board
unnamed: J2.2, R7.2, U4.5 (1A4)
unnamed: R2.1, U19.4 (Y)
OE_ABUS: U4.55 (2~OE), U5.56 (1~OE), U6.1 (1~OE); also elsewhere on the board
OE_D_HIGH: U7.25 (2~OE); also elsewhere on the board
OE_D_LOW: U7.48 (1~OE); also elsewhere on the board
OVR: J1.17, U4.10 (1A8)
OVR_3V3: U4.46 (1B8); also elsewhere on the board
RST: J1.53, U5.27 (2A11); also elsewhere on the board
RST_3V3: U5.30 (2B11); also elsewhere on the board
RW: J1.68, U6.18 (1B1)
RW_3V3: U6.2 (1A1); also elsewhere on the board
UDS: J1.72, U6.14 (1B3)
UDS_3V3: U6.6 (1A3); also elsewhere on the board
VMA: J1.51, U5.26 (2A10)
VMA_3V3: U5.31 (2B10); also elsewhere on the board
VPA: J1.48, U5.24 (2A8)
VPA_3V3: U5.33 (2B8); also elsewhere on the board
XRDY: J1.18, U4.11 (1A9)
XRDY_3V3: U4.45 (1B9); also elsewhere on the board

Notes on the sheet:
CLK28M
-5V/-12V
+12V
0805 0.01uF = 10nF
3V3
4V3
Supply to FPGA I/O LVTTL
Supply to FET level shifters
Supply to ESP32-C5
0805 0.1uF = 100nF
1206 10uF

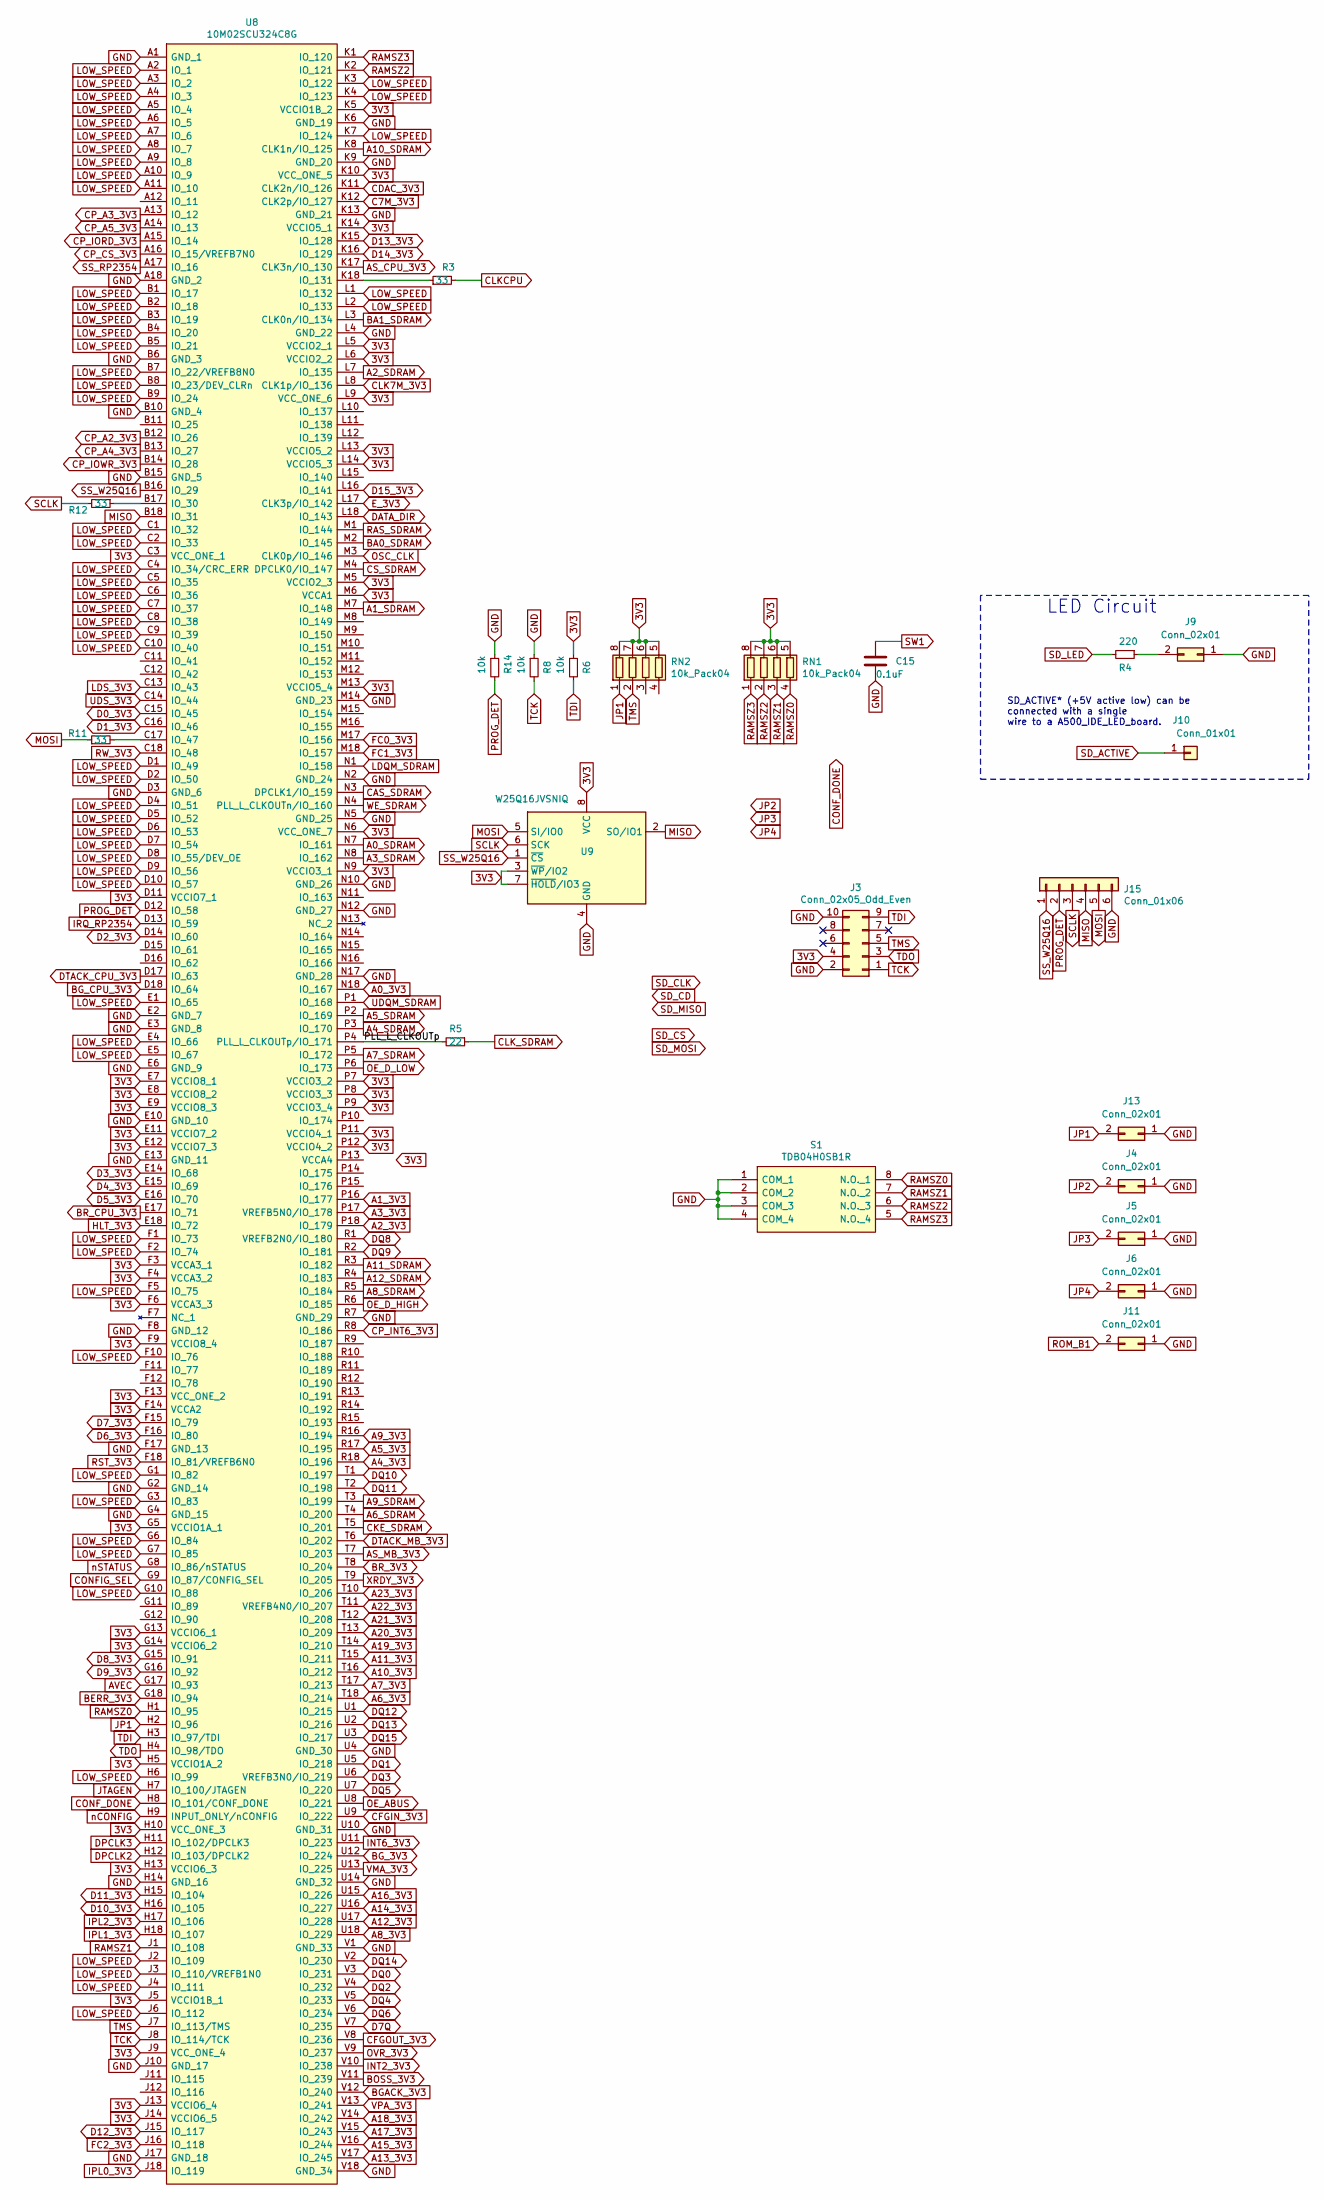
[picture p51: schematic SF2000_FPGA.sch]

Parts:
C15: 0.1uF; C_0805_2012Metric_Pad1.15x1.40mm_HandSolder
J3: Conn_02x05_Odd_Even; PinHeader_2x05_P2.54mm_Vertical
J4, J5, J6, J11: Conn_02x01; PinHeader_2x01_P2.00mm_Vertical
J9, J13: Conn_02x01; PinHeader_2x01_P2.54mm_Vertical
J10: Conn_01x01; PinHeader_1x01_P2.54mm_Horizontal
J15: Conn_01x06; PinHeader_1x06_P2.54mm_Vertical
R3, R11, R12: 33; R_0603_1608Metric_Pad0.98x0.95mm_HandSolder
R4: 220; R_0805_2012Metric_Pad1.15x1.40mm_HandSolder
R5: 22; R_0603_1608Metric_Pad0.98x0.95mm_HandSolder
R6, R8, R14: 10k; R_0603_1608Metric_Pad0.98x0.95mm_HandSolder
RN1, RN2: 10k_Pack04; RESCAF80P320X160X60-8N
S1: TDB04H0SB1R; TDB04H0SB1
U8: 10M02SCU324C8G; BGA-324_15.0x15.0mm_Layout18x18_P0.8mm_Ball0.5mm_Pad0.4mm_N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
U9: W25Q16JVSNIQ; SOIC-8_3.9x4.9mm_P1.27mm

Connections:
3V3: J3.4, R6.1, RN1.5 (R4.2), RN1.6 (R3.2), RN1.7 (R2.2), RN1.8 (R1.2), RN2.5 (R4.2), RN2.6 (R3.2), RN2.7 (R2.2), RN2.8 (R1.2), U8.C3 (VCC_ONE_1), U8.D11 (VCCIO7_1), U8.E7 (VCCIO8_1), U8.E8 (VCCIO8_2), U8.E9 (VCCIO8_3), U8.E11 (VCCIO7_2), U8.E12 (VCCIO7_3), U8.F3 (VCCA3_1), U8.F4 (VCCA3_2), U8.F6 (VCCA3_3), U8.F9 (VCCIO8_4), U8.F13 (VCC_ONE_2), U8.F14 (VCCA2), U8.G5 (VCCIO1A_1), U8.G13 (VCCIO6_1), U8.G14 (VCCIO6_2), U8.H5 (VCCIO1A_2), U8.H10 (VCC_ONE_3), U8.H13 (VCCIO6_3), U8.J5 (VCCIO1B_1), U8.J9 (VCC_ONE_4), U8.J13 (VCCIO6_4), U8.J14 (VCCIO6_5), U8.K5 (VCCIO1B_2), U8.K10 (VCC_ONE_5), U8.K14 (VCCIO5_1), U8.L5 (VCCIO2_1), U8.L6 (VCCIO2_2), U8.L9 (VCC_ONE_6), U8.L13 (VCCIO5_2), U8.L14 (VCCIO5_3), U8.M5 (VCCIO2_3), U8.M6 (VCCA1), U8.M13 (VCCIO5_4), U8.N6 (VCC_ONE_7), U8.N9 (VCCIO3_1), U8.P7 (VCCIO3_2), U8.P8 (VCCIO3_3), U8.P9 (VCCIO3_4), U8.P11 (VCCIO4_1), U8.P12 (VCCIO4_2), U9.3 (~WP~/IO2), U9.7 (~HOLD~/IO3), U9.8 (VCC); also elsewhere on the board
/SF2000_FPGA/PLL_L_CLKOUTp: R5.2, U8.P4 (PLL_L_CLKOUTp/IO_171)
A0_3V3: U8.N18 (IO_167); also elsewhere on the board
A0_SDRAM: U8.N7 (IO_161); also elsewhere on the board
A1_3V3: U8.P16 (IO_177); also elsewhere on the board
A1_SDRAM: U8.M7 (IO_148); also elsewhere on the board
A2_3V3: U8.P18 (IO_179); also elsewhere on the board
A2_SDRAM: U8.L7 (IO_135); also elsewhere on the board
A3_3V3: U8.P17 (VREFB5N0/IO_178); also elsewhere on the board
A3_SDRAM: U8.N8 (IO_162); also elsewhere on the board
A4_3V3: U8.R18 (IO_196); also elsewhere on the board
A4_SDRAM: U8.P3 (IO_170); also elsewhere on the board
A5_3V3: U8.R17 (IO_195); also elsewhere on the board
A5_SDRAM: U8.P2 (IO_169); also elsewhere on the board
A6_3V3: U8.T18 (IO_214); also elsewhere on the board
A6_SDRAM: U8.T4 (IO_200); also elsewhere on the board
A7_3V3: U8.T17 (IO_213); also elsewhere on the board
A7_SDRAM: U8.P5 (IO_172); also elsewhere on the board
A8_3V3: U8.U18 (IO_229); also elsewhere on the board
A8_SDRAM: U8.R5 (IO_184); also elsewhere on the board
A9_3V3: U8.R16 (IO_194); also elsewhere on the board
A9_SDRAM: U8.T3 (IO_199); also elsewhere on the board
A10_3V3: U8.T16 (IO_212); also elsewhere on the board
A10_SDRAM: U8.K8 (CLK1n/IO_125); also elsewhere on the board
A11_3V3: U8.T15 (IO_211); also elsewhere on the board
A11_SDRAM: U8.R3 (IO_182); also elsewhere on the board
A12_3V3: U8.U17 (IO_228); also elsewhere on the board
A12_SDRAM: U8.R4 (IO_183); also elsewhere on the board
A13_3V3: U8.V17 (IO_245); also elsewhere on the board
A14_3V3: U8.U16 (IO_227); also elsewhere on the board
A15_3V3: U8.V16 (IO_244); also elsewhere on the board
A16_3V3: U8.U15 (IO_226); also elsewhere on the board
A17_3V3: U8.V15 (IO_243); also elsewhere on the board
A18_3V3: U8.V14 (IO_242); also elsewhere on the board
A19_3V3: U8.T14 (IO_210); also elsewhere on the board
A20_3V3: U8.T13 (IO_209); also elsewhere on the board
A21_3V3: U8.T12 (IO_208); also elsewhere on the board
A22_3V3: U8.T11 (VREFB4N0/IO_207); also elsewhere on the board
A23_3V3: U8.T10 (IO_206); also elsewhere on the board
AS_CPU_3V3: U8.K17 (CLK3n/IO_130); also elsewhere on the board
AS_MB_3V3: U8.T7 (IO_203); also elsewhere on the board
AVEC: U8.G17 (IO_93); also elsewhere on the board
BA0_SDRAM: U8.M2 (IO_145); also elsewhere on the board
BA1_SDRAM: U8.L3 (CLK0n/IO_134); also elsewhere on the board
BERR_3V3: U8.G18 (IO_94); also elsewhere on the board
BGACK_3V3: U8.V12 (IO_240); also elsewhere on the board
BG_3V3: U8.U12 (IO_224); also elsewhere on the board
BG_CPU_3V3: U8.D18 (IO_64); also elsewhere on the board
BOSS_3V3: U8.V11 (IO_239); also elsewhere on the board
BR_3V3: U8.T8 (IO_204); also elsewhere on the board
BR_CPU_3V3: U8.E17 (IO_71); also elsewhere on the board
C7M_3V3: U8.K12 (CLK2p/IO_127); also elsewhere on the board
CAS_SDRAM: U8.N3 (DPCLK1/IO_159); also elsewhere on the board
CDAC_3V3: U8.K11 (CLK2n/IO_126); also elsewhere on the board
CFGIN_3V3: U8.U9 (IO_222); also elsewhere on the board
CFGOUT_3V3: U8.V8 (IO_236); also elsewhere on the board
CKE_SDRAM: U8.T5 (IO_201); also elsewhere on the board
CLK7M_3V3: U8.L8 (CLK1p/IO_136); also elsewhere on the board
CLKCPU: R3.2; also elsewhere on the board
CLK_SDRAM: R5.1; also elsewhere on the board
CONFIG_SEL: U8.G9 (IO_87/CONFIG_SEL)
CONF_DONE: U8.H8 (IO_101/CONF_DONE)
CP_A2_3V3: U8.B12 (IO_26); also elsewhere on the board
CP_A3_3V3: U8.A13 (IO_12); also elsewhere on the board
CP_A4_3V3: U8.B13 (IO_27); also elsewhere on the board
CP_A5_3V3: U8.A14 (IO_13); also elsewhere on the board
CP_CS_3V3: U8.A16 (IO_15/VREFB7N0); also elsewhere on the board
CP_INT6_3V3: U8.R8 (IO_186); also elsewhere on the board
CP_IORD_3V3: U8.A15 (IO_14); also elsewhere on the board
CP_IOWR_3V3: U8.B14 (IO_28); also elsewhere on the board
CS_SDRAM: U8.M4 (DPCLK0/IO_147); also elsewhere on the board
D0_3V3: U8.C15 (IO_45); also elsewhere on the board
D1_3V3: U8.C16 (IO_46); also elsewhere on the board
D2_3V3: U8.D14 (IO_60); also elsewhere on the board
D3_3V3: U8.E14 (IO_68); also elsewhere on the board
D4_3V3: U8.E15 (IO_69); also elsewhere on the board
D5_3V3: U8.E16 (IO_70); also elsewhere on the board
D6_3V3: U8.F16 (IO_80); also elsewhere on the board
D7Q: U8.V7 (IO_235); also elsewhere on the board
D7_3V3: U8.F15 (IO_79); also elsewhere on the board
D8_3V3: U8.G15 (IO_91); also elsewhere on the board
D9_3V3: U8.G16 (IO_92); also elsewhere on the board
D10_3V3: U8.H16 (IO_105); also elsewhere on the board
D11_3V3: U8.H15 (IO_104); also elsewhere on the board
D12_3V3: U8.J15 (IO_117); also elsewhere on the board
D13_3V3: U8.K15 (IO_128); also elsewhere on the board
D14_3V3: U8.K16 (IO_129); also elsewhere on the board
D15_3V3: U8.L16 (IO_141); also elsewhere on the board
DATA_DIR: U8.L18 (IO_143); also elsewhere on the board
DPCLK2: U8.H12 (IO_103/DPCLK2)
DPCLK3: U8.H11 (IO_102/DPCLK3)
DQ0: U8.V3 (IO_231); also elsewhere on the board
DQ1: U8.U5 (IO_218); also elsewhere on the board
DQ2: U8.V4 (IO_232); also elsewhere on the board
DQ3: U8.U6 (VREFB3N0/IO_219); also elsewhere on the board
DQ4: U8.V5 (IO_233); also elsewhere on the board
DQ5: U8.U7 (IO_220); also elsewhere on the board
DQ6: U8.V6 (IO_234); also elsewhere on the board
DQ8: U8.R1 (VREFB2N0/IO_180); also elsewhere on the board
DQ9: U8.R2 (IO_181); also elsewhere on the board
DQ10: U8.T1 (IO_197); also elsewhere on the board
DQ11: U8.T2 (IO_198); also elsewhere on the board
DQ12: U8.U1 (IO_215); also elsewhere on the board
DQ13: U8.U2 (IO_216); also elsewhere on the board
DQ14: U8.V2 (IO_230); also elsewhere on the board
DQ15: U8.U3 (IO_217); also elsewhere on the board
DTACK_CPU_3V3: U8.D17 (IO_63); also elsewhere on the board
DTACK_MB_3V3: U8.T6 (IO_202); also elsewhere on the board
E_3V3: U8.L17 (CLK3p/IO_142); also elsewhere on the board
FC0_3V3: U8.M17 (IO_156); also elsewhere on the board
FC1_3V3: U8.M18 (IO_157); also elsewhere on the board
FC2_3V3: U8.J16 (IO_118); also elsewhere on the board
GND: C15.2, J3.2, J3.10, J4.1, J5.1, J6.1, J9.1, J11.1, J13.1, J15.6, R8.1, R14.1, S1.1 (COM_1), S1.2 (COM_2), S1.3 (COM_3), S1.4 (COM_4), U8.A1 (GND_1), U8.A18 (GND_2), U8.B6 (GND_3), U8.B10 (GND_4), U8.B15 (GND_5), U8.D3 (GND_6), U8.E2 (GND_7), U8.E3 (GND_8), U8.E6 (GND_9), U8.E10 (GND_10), U8.E13 (GND_11), U8.F8 (GND_12), U8.F17 (GND_13), U8.G2 (GND_14), U8.G4 (GND_15), U8.H14 (GND_16), U8.J10 (GND_17), U8.J17 (GND_18), U8.K6 (GND_19), U8.K9 (GND_20), U8.K13 (GND_21), U8.L4 (GND_22), U8.M14 (GND_23), U8.N2 (GND_24), U8.N5 (GND_25), U8.N10 (GND_26), U8.N12 (GND_27), U8.N17 (GND_28), U8.R7 (GND_29), U8.U4 (GND_30), U8.U10 (GND_31), U8.U14 (GND_32), U8.V1 (GND_33), U8.V18 (GND_34), U9.4 (GND); also elsewhere on the board
HLT_3V3: U8.E18 (IO_72); also elsewhere on the board
INT2_3V3: U8.V10 (IO_238); also elsewhere on the board
INT6_3V3: U8.U11 (IO_223); also elsewhere on the board
IPL0_3V3: U8.J18 (IO_119); also elsewhere on the board
IPL1_3V3: U8.H18 (IO_107); also elsewhere on the board
IPL2_3V3: U8.H17 (IO_106); also elsewhere on the board
IRQ_RP2354: U8.D13 (IO_59); also elsewhere on the board
JP1: J13.2, RN2.1 (R1.1), U8.H2 (IO_96)
JP2: J4.2
JP3: J5.2
JP4: J6.2
JTAGEN: U8.H7 (IO_100/JTAGEN)
LDQM_SDRAM: U8.N1 (IO_158); also elsewhere on the board
LDS_3V3: U8.C13 (IO_43); also elsewhere on the board
LOW_SPEED: U8.A2 (IO_1), U8.A3 (IO_2), U8.A4 (IO_3), U8.A5 (IO_4), U8.A6 (IO_5), U8.A7 (IO_6), U8.A8 (IO_7), U8.A9 (IO_8), U8.A10 (IO_9), U8.A11 (IO_10), U8.B1 (IO_17), U8.B2 (IO_18), U8.B3 (IO_19), U8.B4 (IO_20), U8.B5 (IO_21), U8.B7 (IO_22/VREFB8N0), U8.B8 (IO_23/DEV_CLRn), U8.B9 (IO_24), U8.C1 (IO_32), U8.C2 (IO_33), U8.C4 (IO_34/CRC_ERR), U8.C5 (IO_35), U8.C6 (IO_36), U8.C7 (IO_37), U8.C8 (IO_38), U8.C9 (IO_39), U8.C10 (IO_40), U8.D1 (IO_49), U8.D2 (IO_50), U8.D4 (IO_51), U8.D5 (IO_52), U8.D6 (IO_53), U8.D7 (IO_54), U8.D8 (IO_55/DEV_OE), U8.D9 (IO_56), U8.D10 (IO_57), U8.E1 (IO_65), U8.E4 (IO_66), U8.E5 (IO_67), U8.F1 (IO_73), U8.F2 (IO_74), U8.F5 (IO_75), U8.F10 (IO_76), U8.G1 (IO_82), U8.G3 (IO_83), U8.G6 (IO_84), U8.G7 (IO_85), U8.G10 (IO_88), U8.H6 (IO_99), U8.J2 (IO_109), U8.J3 (IO_110/VREFB1N0), U8.J4 (IO_111), U8.J6 (IO_112), U8.K3 (IO_122), U8.K4 (IO_123), U8.K7 (IO_124), U8.L1 (IO_132), U8.L2 (IO_133)
MISO: J15.4, U8.B18 (IO_31), U9.2 (SO/IO1); also elsewhere on the board
MOSI: J15.5, R11.1, U9.5 (SI/IO0); also elsewhere on the board
unnamed: J9.2, R4.1
unnamed: R3.1, U8.K18 (IO_131)
unnamed: R11.2, U8.C17 (IO_47)
unnamed: R12.1, U8.B17 (IO_30)
OE_ABUS: U8.U8 (IO_221); also elsewhere on the board
OE_D_HIGH: U8.R6 (IO_185); also elsewhere on the board
OE_D_LOW: U8.P6 (IO_173); also elsewhere on the board
OSC_CLK: U8.M3 (CLK0p/IO_146); also elsewhere on the board
OVR_3V3: U8.V9 (IO_237); also elsewhere on the board
PROG_DET: J15.2, R14.2, U8.D12 (IO_58)
RAMSZ0: RN1.4 (R4.1), S1.8 (N.O._1), U8.H1 (IO_95)
RAMSZ1: RN1.3 (R3.1), S1.7 (N.O._2), U8.J1 (IO_108)
RAMSZ2: RN1.2 (R2.1), S1.6 (N.O._3), U8.K2 (IO_121)
RAMSZ3: RN1.1 (R1.1), S1.5 (N.O._4), U8.K1 (IO_120)
RAS_SDRAM: U8.M1 (IO_144); also elsewhere on the board
ROM_B1: J11.2
RST_3V3: U8.F18 (IO_81/VREFB6N0); also elsewhere on the board
RW_3V3: U8.C18 (IO_48); also elsewhere on the board
SCLK: J15.3, R12.2, U9.6 (SCK); also elsewhere on the board
SD_ACTIVE: J10.1; also elsewhere on the board
SD_LED: R4.2; also elsewhere on the board
SS_RP2354: U8.A17 (IO_16); also elsewhere on the board
SS_W25Q16: J15.1, U8.B16 (IO_29), U9.1 (~CS); also elsewhere on the board
SW1: C15.1
TCK: J3.1, R8.2, U8.J8 (IO_114/TCK)
TDI: J3.9, R6.2, U8.H3 (IO_97/TDI)
TDO: J3.3, U8.H4 (IO_98/TDO)
TMS: J3.5, RN2.2 (R2.1), U8.J7 (IO_113/TMS)
UDQM_SDRAM: U8.P1 (IO_168); also elsewhere on the board
UDS_3V3: U8.C14 (IO_44); also elsewhere on the board
VMA_3V3: U8.U13 (IO_225); also elsewhere on the board
VPA_3V3: U8.V13 (IO_241); also elsewhere on the board
WE_SDRAM: U8.N4 (PLL_L_CLKOUTn/IO_160); also elsewhere on the board
XRDY_3V3: U8.T9 (IO_205); also elsewhere on the board
nCONFIG: U8.H9 (INPUT_ONLY/nCONFIG)
nSTATUS: U8.G8 (IO_86/nSTATUS)

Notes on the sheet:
LED Circuit
SD_ACTIVE* (+5V active low) can be connected with a single wire to a A500_IDE_LED_board.

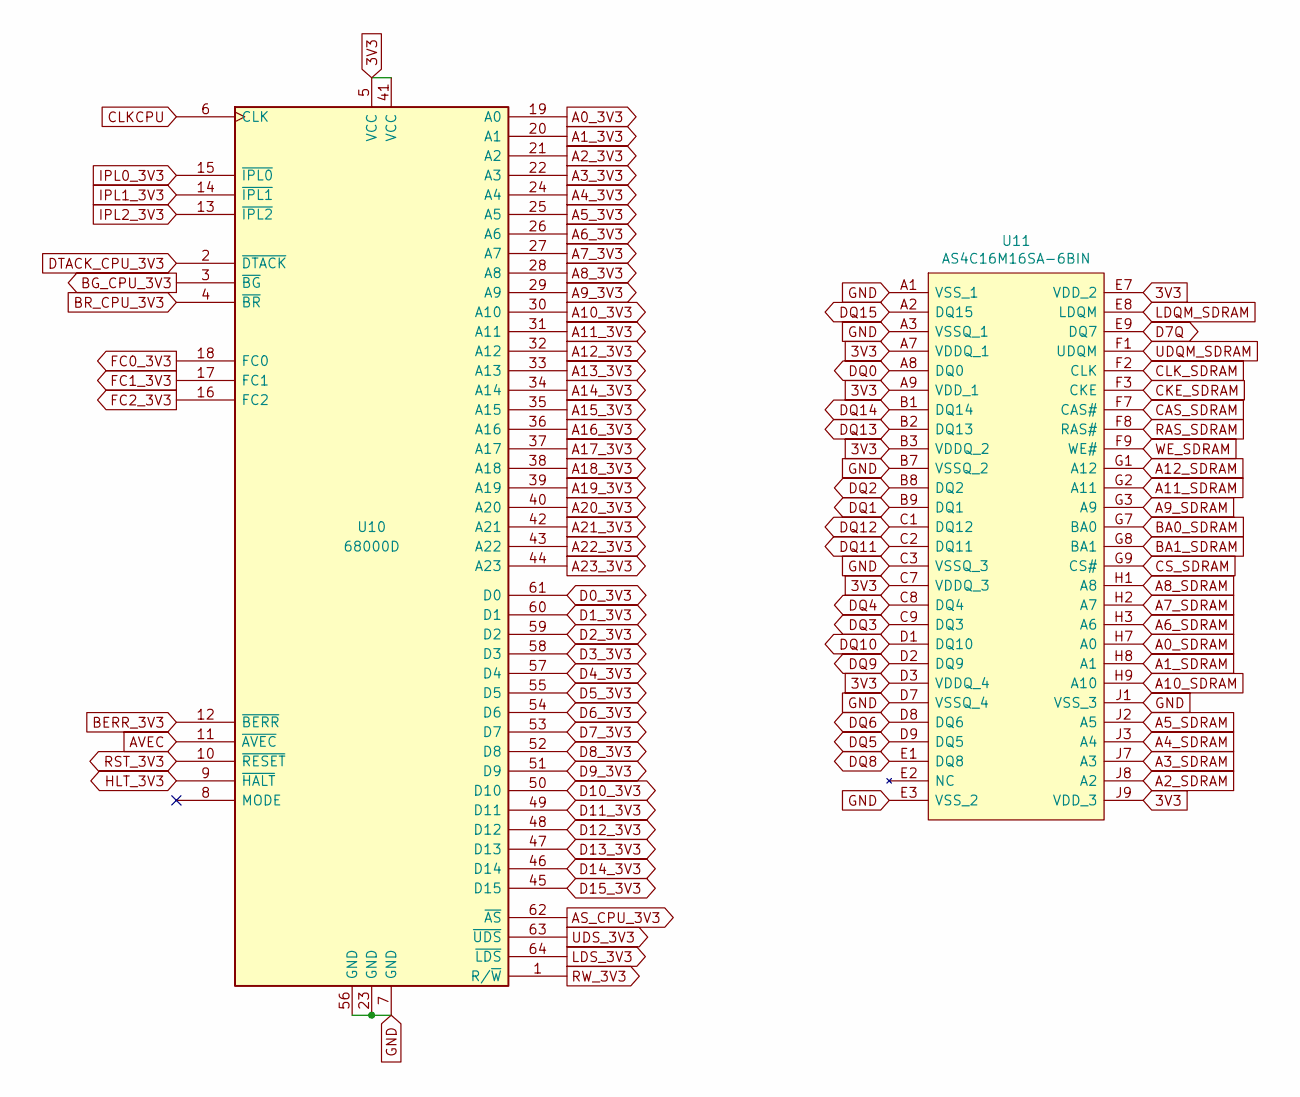
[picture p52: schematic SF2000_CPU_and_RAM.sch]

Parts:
U10: 68000D; QFP-64_14x14mm_Pitch0.8mm
U11: AS4C16M16SA-6BIN; BGA54C80P9X9_800X800X120

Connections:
3V3: U10.5 (VCC), U10.41 (VCC), U11.A7 (VDDQ_1), U11.A9 (VDD_1), U11.B3 (VDDQ_2), U11.C7 (VDDQ_3), U11.D3 (VDDQ_4), U11.E7 (VDD_2), U11.J9 (VDD_3); also elsewhere on the board
A0_3V3: U10.19 (A0); also elsewhere on the board
A0_SDRAM: U11.H7 (A0); also elsewhere on the board
A1_3V3: U10.20 (A1); also elsewhere on the board
A1_SDRAM: U11.H8 (A1); also elsewhere on the board
A2_3V3: U10.21 (A2); also elsewhere on the board
A2_SDRAM: U11.J8 (A2); also elsewhere on the board
A3_3V3: U10.22 (A3); also elsewhere on the board
A3_SDRAM: U11.J7 (A3); also elsewhere on the board
A4_3V3: U10.24 (A4); also elsewhere on the board
A4_SDRAM: U11.J3 (A4); also elsewhere on the board
A5_3V3: U10.25 (A5); also elsewhere on the board
A5_SDRAM: U11.J2 (A5); also elsewhere on the board
A6_3V3: U10.26 (A6); also elsewhere on the board
A6_SDRAM: U11.H3 (A6); also elsewhere on the board
A7_3V3: U10.27 (A7); also elsewhere on the board
A7_SDRAM: U11.H2 (A7); also elsewhere on the board
A8_3V3: U10.28 (A8); also elsewhere on the board
A8_SDRAM: U11.H1 (A8); also elsewhere on the board
A9_3V3: U10.29 (A9); also elsewhere on the board
A9_SDRAM: U11.G3 (A9); also elsewhere on the board
A10_3V3: U10.30 (A10); also elsewhere on the board
A10_SDRAM: U11.H9 (A10); also elsewhere on the board
A11_3V3: U10.31 (A11); also elsewhere on the board
A11_SDRAM: U11.G2 (A11); also elsewhere on the board
A12_3V3: U10.32 (A12); also elsewhere on the board
A12_SDRAM: U11.G1 (A12); also elsewhere on the board
A13_3V3: U10.33 (A13); also elsewhere on the board
A14_3V3: U10.34 (A14); also elsewhere on the board
A15_3V3: U10.35 (A15); also elsewhere on the board
A16_3V3: U10.36 (A16); also elsewhere on the board
A17_3V3: U10.37 (A17); also elsewhere on the board
A18_3V3: U10.38 (A18); also elsewhere on the board
A19_3V3: U10.39 (A19); also elsewhere on the board
A20_3V3: U10.40 (A20); also elsewhere on the board
A21_3V3: U10.42 (A21); also elsewhere on the board
A22_3V3: U10.43 (A22); also elsewhere on the board
A23_3V3: U10.44 (A23); also elsewhere on the board
AS_CPU_3V3: U10.62 (~AS); also elsewhere on the board
AVEC: U10.11 (~AVEC); also elsewhere on the board
BA0_SDRAM: U11.G7 (BA0); also elsewhere on the board
BA1_SDRAM: U11.G8 (BA1); also elsewhere on the board
BERR_3V3: U10.12 (~BERR); also elsewhere on the board
BG_CPU_3V3: U10.3 (~BG); also elsewhere on the board
BR_CPU_3V3: U10.4 (~BR); also elsewhere on the board
CAS_SDRAM: U11.F7 (CAS#); also elsewhere on the board
CKE_SDRAM: U11.F3 (CKE); also elsewhere on the board
CLKCPU: U10.6 (CLK); also elsewhere on the board
CLK_SDRAM: U11.F2 (CLK); also elsewhere on the board
CS_SDRAM: U11.G9 (CS#); also elsewhere on the board
D0_3V3: U10.61 (D0); also elsewhere on the board
D1_3V3: U10.60 (D1); also elsewhere on the board
D2_3V3: U10.59 (D2); also elsewhere on the board
D3_3V3: U10.58 (D3); also elsewhere on the board
D4_3V3: U10.57 (D4); also elsewhere on the board
D5_3V3: U10.55 (D5); also elsewhere on the board
D6_3V3: U10.54 (D6); also elsewhere on the board
D7Q: U11.E9 (DQ7); also elsewhere on the board
D7_3V3: U10.53 (D7); also elsewhere on the board
D8_3V3: U10.52 (D8); also elsewhere on the board
D9_3V3: U10.51 (D9); also elsewhere on the board
D10_3V3: U10.50 (D10); also elsewhere on the board
D11_3V3: U10.49 (D11); also elsewhere on the board
D12_3V3: U10.48 (D12); also elsewhere on the board
D13_3V3: U10.47 (D13); also elsewhere on the board
D14_3V3: U10.46 (D14); also elsewhere on the board
D15_3V3: U10.45 (D15); also elsewhere on the board
DQ0: U11.A8 (DQ0); also elsewhere on the board
DQ1: U11.B9 (DQ1); also elsewhere on the board
DQ2: U11.B8 (DQ2); also elsewhere on the board
DQ3: U11.C9 (DQ3); also elsewhere on the board
DQ4: U11.C8 (DQ4); also elsewhere on the board
DQ5: U11.D9 (DQ5); also elsewhere on the board
DQ6: U11.D8 (DQ6); also elsewhere on the board
DQ8: U11.E1 (DQ8); also elsewhere on the board
DQ9: U11.D2 (DQ9); also elsewhere on the board
DQ10: U11.D1 (DQ10); also elsewhere on the board
DQ11: U11.C2 (DQ11); also elsewhere on the board
DQ12: U11.C1 (DQ12); also elsewhere on the board
DQ13: U11.B2 (DQ13); also elsewhere on the board
DQ14: U11.B1 (DQ14); also elsewhere on the board
DQ15: U11.A2 (DQ15); also elsewhere on the board
DTACK_CPU_3V3: U10.2 (~DTACK); also elsewhere on the board
FC0_3V3: U10.18 (FC0); also elsewhere on the board
FC1_3V3: U10.17 (FC1); also elsewhere on the board
FC2_3V3: U10.16 (FC2); also elsewhere on the board
GND: U10.7 (GND), U10.23 (GND), U10.56 (GND), U11.A1 (VSS_1), U11.A3 (VSSQ_1), U11.B7 (VSSQ_2), U11.C3 (VSSQ_3), U11.D7 (VSSQ_4), U11.E3 (VSS_2), U11.J1 (VSS_3); also elsewhere on the board
HLT_3V3: U10.9 (~HALT); also elsewhere on the board
IPL0_3V3: U10.15 (~IPL0); also elsewhere on the board
IPL1_3V3: U10.14 (~IPL1); also elsewhere on the board
IPL2_3V3: U10.13 (~IPL2); also elsewhere on the board
LDQM_SDRAM: U11.E8 (LDQM); also elsewhere on the board
LDS_3V3: U10.64 (~LDS); also elsewhere on the board
RAS_SDRAM: U11.F8 (RAS#); also elsewhere on the board
RST_3V3: U10.10 (~RESET); also elsewhere on the board
RW_3V3: U10.1 (R/~W); also elsewhere on the board
UDQM_SDRAM: U11.F1 (UDQM); also elsewhere on the board
UDS_3V3: U10.63 (~UDS); also elsewhere on the board
WE_SDRAM: U11.F9 (WE#); also elsewhere on the board

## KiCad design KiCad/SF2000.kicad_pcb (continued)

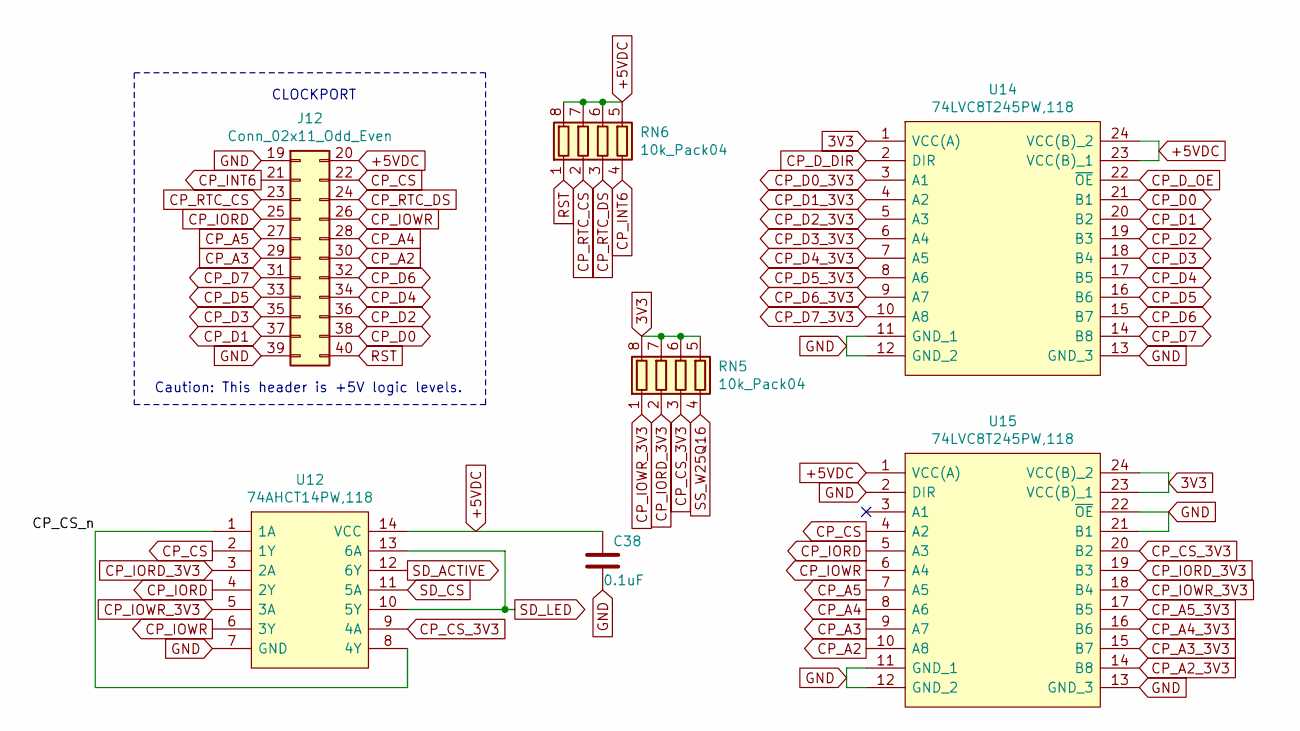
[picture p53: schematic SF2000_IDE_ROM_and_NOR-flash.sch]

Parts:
C38: 0.1uF; C_0805_2012Metric_Pad1.18x1.45mm_HandSolder
J12: Conn_02x11_Odd_Even; PinHeader_2x11_P2.00mm_Vertical
RN5, RN6: 10k_Pack04; RESCAF80P320X160X60-8N
U12: 74AHCT14PW,118; TSSOP-14_4.4x5mm_P0.65mm
U14, U15: 74LVC8T245PW,118; TSSOP-24_4.4x7.8mm_P0.65mm

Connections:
3V3: RN5.5 (R4.2), RN5.6 (R3.2), RN5.7 (R2.2), RN5.8 (R1.2), U14.1 (VCC(A)), U15.23 (VCC(B)_1), U15.24 (VCC(B)_2); also elsewhere on the board
+5VDC: C38.1, J12.20, RN6.5 (R4.2), RN6.6 (R3.2), RN6.7 (R2.2), RN6.8 (R1.2), U12.14 (VCC), U14.23 (VCC(B)_1), U14.24 (VCC(B)_2), U15.1 (VCC(A)); also elsewhere on the board
/SF2000_IDE_ROM_and_NOR-flash/CP_CS_n: U12.1 (1A), U12.8 (4Y)
CP_A2: J12.30, U15.10 (A8)
CP_A2_3V3: U15.14 (B8); also elsewhere on the board
CP_A3: J12.29, U15.9 (A7)
CP_A3_3V3: U15.15 (B7); also elsewhere on the board
CP_A4: J12.28, U15.8 (A6)
CP_A4_3V3: U15.16 (B6); also elsewhere on the board
CP_A5: J12.27, U15.7 (A5)
CP_A5_3V3: U15.17 (B5); also elsewhere on the board
CP_CS: J12.22, U12.2 (1Y), U15.4 (A2)
CP_CS_3V3: RN5.3 (R3.1), U12.9 (4A), U15.20 (B2); also elsewhere on the board
CP_D0: J12.38, U14.21 (B1)
CP_D0_3V3: U14.3 (A1)
CP_D1: J12.37, U14.20 (B2)
CP_D1_3V3: U14.4 (A2)
CP_D2: J12.36, U14.19 (B3)
CP_D2_3V3: U14.5 (A3)
CP_D3: J12.35, U14.18 (B4)
CP_D3_3V3: U14.6 (A4)
CP_D4: J12.34, U14.17 (B5)
CP_D4_3V3: U14.7 (A5)
CP_D5: J12.33, U14.16 (B6)
CP_D5_3V3: U14.8 (A6)
CP_D6: J12.32, U14.15 (B7)
CP_D6_3V3: U14.9 (A7)
CP_D7: J12.31, U14.14 (B8)
CP_D7_3V3: U14.10 (A8)
CP_D_DIR: U14.2 (DIR)
CP_D_OE: U14.22 (~OE)
CP_INT6: J12.21, RN6.4 (R4.1); also elsewhere on the board
CP_IORD: J12.25, U12.4 (2Y), U15.5 (A3)
CP_IORD_3V3: RN5.2 (R2.1), U12.3 (2A), U15.19 (B3); also elsewhere on the board
CP_IOWR: J12.26, U12.6 (3Y), U15.6 (A4)
CP_IOWR_3V3: RN5.1 (R1.1), U12.5 (3A), U15.18 (B4); also elsewhere on the board
CP_RTC_CS: J12.23, RN6.2 (R2.1)
CP_RTC_DS: J12.24, RN6.3 (R3.1)
GND: C38.2, J12.19, J12.39, U12.7 (GND), U14.11 (GND_1), U14.12 (GND_2), U14.13 (GND_3), U15.2 (DIR), U15.11 (GND_1), U15.12 (GND_2), U15.13 (GND_3), U15.21 (B1), U15.22 (~OE); also elsewhere on the board
RST: J12.40, RN6.1 (R1.1); also elsewhere on the board
SD_ACTIVE: U12.12 (6Y); also elsewhere on the board
SD_CS: U12.11 (5A); also elsewhere on the board
SD_LED: U12.10 (5Y), U12.13 (6A); also elsewhere on the board
SS_W25Q16: RN5.4 (R4.1); also elsewhere on the board

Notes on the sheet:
CLOCKPORT
Caution: This header is +5V logic levels.

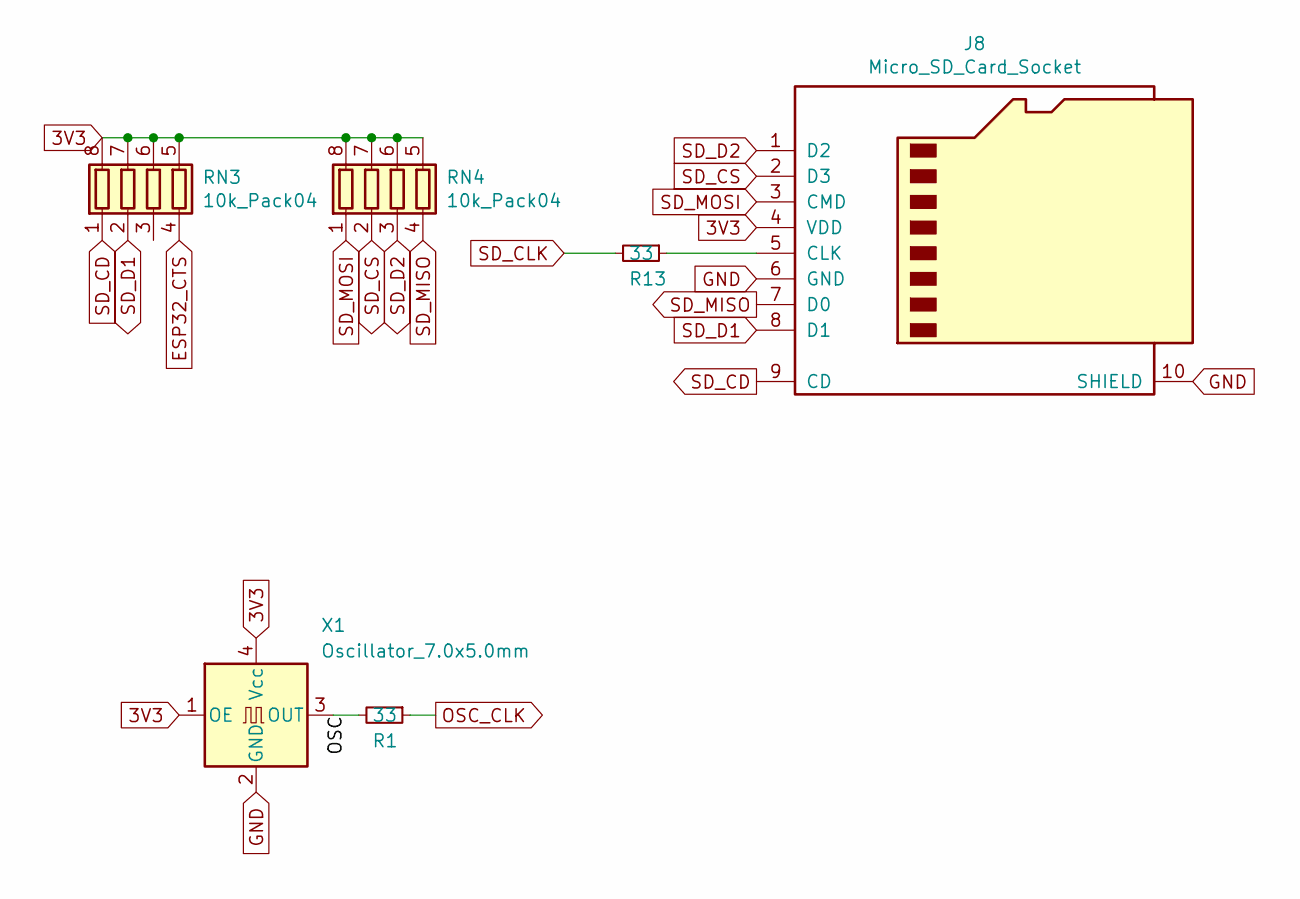
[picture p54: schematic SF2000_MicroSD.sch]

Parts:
J8: Micro_SD_Card_Socket; GCT-MEM2055-00-190-01-A
R1, R13: 33; R_0603_1608Metric_Pad0.98x0.95mm_HandSolder
RN3, RN4: 10k_Pack04; RESCAF80P320X160X60-8N
X1: Oscillator_7.0x5.0mm; Oscillator_SMD_SeikoEpson_SG8002CA-4Pin_7.0x5.0mm

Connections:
3V3: J8.4 (VDD), RN3.5 (R4.2), RN3.6 (R3.2), RN3.7 (R2.2), RN3.8 (R1.2), RN4.5 (R4.2), RN4.6 (R3.2), RN4.7 (R2.2), RN4.8 (R1.2), X1.1 (OE), X1.4 (Vcc); also elsewhere on the board
/SF2000_MicroSD/OSC: R1.2, X1.3 (OUT)
ESP32_CTS: RN3.4 (R4.1); also elsewhere on the board
GND: J8.6 (GND), J8.10 (SHIELD), X1.2 (GND); also elsewhere on the board
unnamed: J8.5 (CLK), R13.1
OSC_CLK: R1.1; also elsewhere on the board
SD_CD: J8.9 (CD), RN3.1 (R1.1)
SD_CLK: R13.2
SD_CS: J8.2 (D3), RN4.2 (R2.1); also elsewhere on the board
SD_D1: J8.8 (D1), RN3.2 (R2.1)
SD_D2: J8.1 (D2), RN4.3 (R3.1)
SD_MISO: J8.7 (D0), RN4.4 (R4.1)
SD_MOSI: J8.3 (CMD), RN4.1 (R1.1)

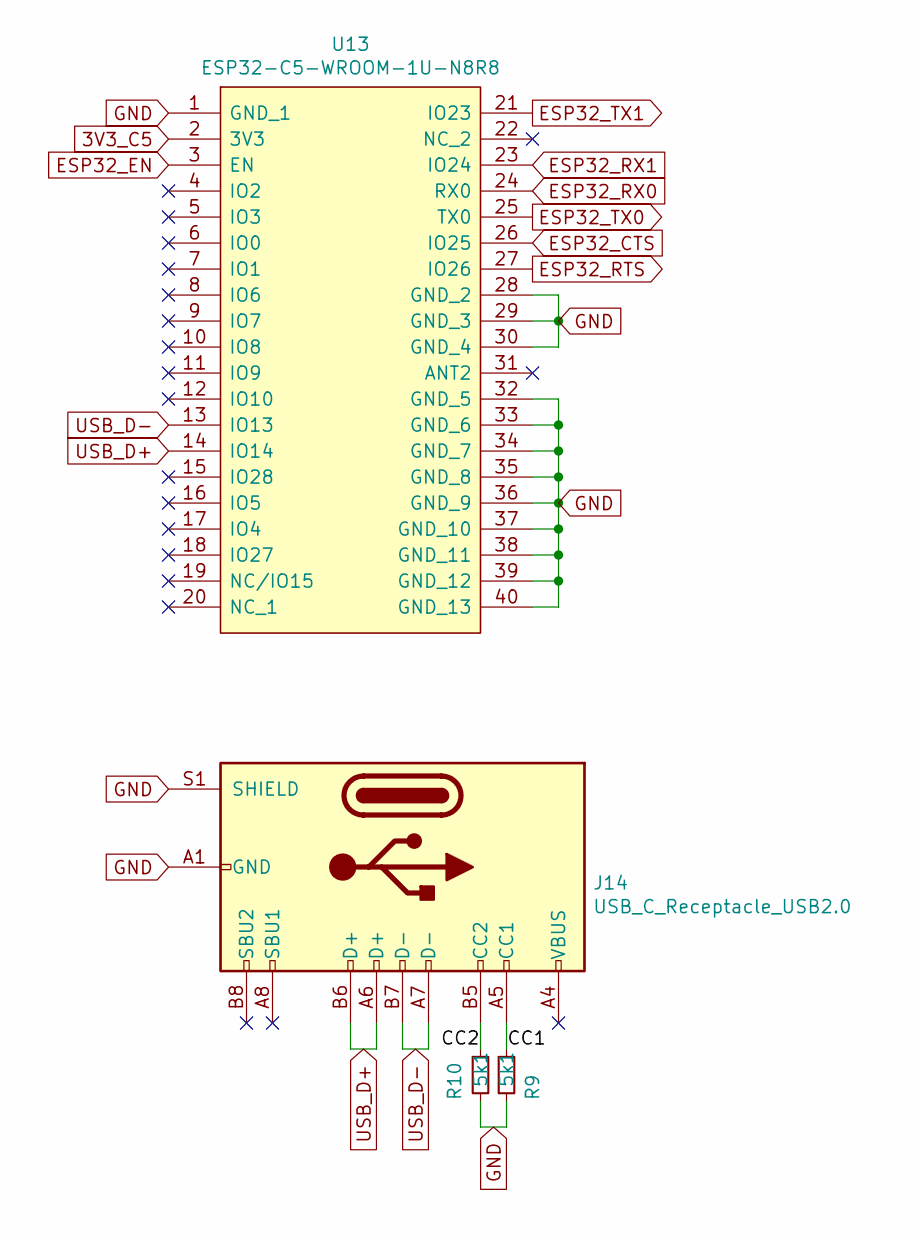
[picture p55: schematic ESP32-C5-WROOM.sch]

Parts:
J14: USB_C_Receptacle_USB2.0; USB_C_Receptacle_HRO_TYPE-C-31-M-12
R9, R10: 5k1; R_0603_1608Metric_Pad0.98x0.95mm_HandSolder
U13: ESP32-C5-WROOM-1U-N8R8; ESP32C5WROOM1UN8R8

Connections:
3V3_C5: U13.2 (3V3); also elsewhere on the board
/ESP32-C5-WROOM/CC1: J14.A5 (CC1), R9.1
/ESP32-C5-WROOM/CC2: J14.B5 (CC2), R10.1
ESP32_CTS: U13.26 (IO25); also elsewhere on the board
ESP32_EN: U13.3 (EN); also elsewhere on the board
ESP32_RTS: U13.27 (IO26); also elsewhere on the board
ESP32_RX0: U13.24 (RX0)
ESP32_RX1: U13.23 (IO24); also elsewhere on the board
ESP32_TX0: U13.25 (TX0)
ESP32_TX1: U13.21 (IO23); also elsewhere on the board
GND: J14.A1 (GND), J14.A12 (GND), J14.B1 (GND), J14.B12 (GND), J14.S1 (SHIELD), R9.2, R10.2, U13.1 (GND_1), U13.28 (GND_2), U13.29 (GND_3), U13.30 (GND_4), U13.32 (GND_5), U13.33 (GND_6), U13.34 (GND_7), U13.35 (GND_8), U13.36 (GND_9), U13.37 (GND_10), U13.38 (GND_11), U13.39 (GND_12), U13.40 (GND_13); also elsewhere on the board
unnamed: J14.A4 (VBUS), J14.A9 (VBUS), J14.B4 (VBUS), J14.B9 (VBUS)
USB_D+: J14.A6 (D+), J14.B6 (D+), U13.14 (IO14)
USB_D−: J14.A7 (D-), J14.B7 (D-), U13.13 (IO13)

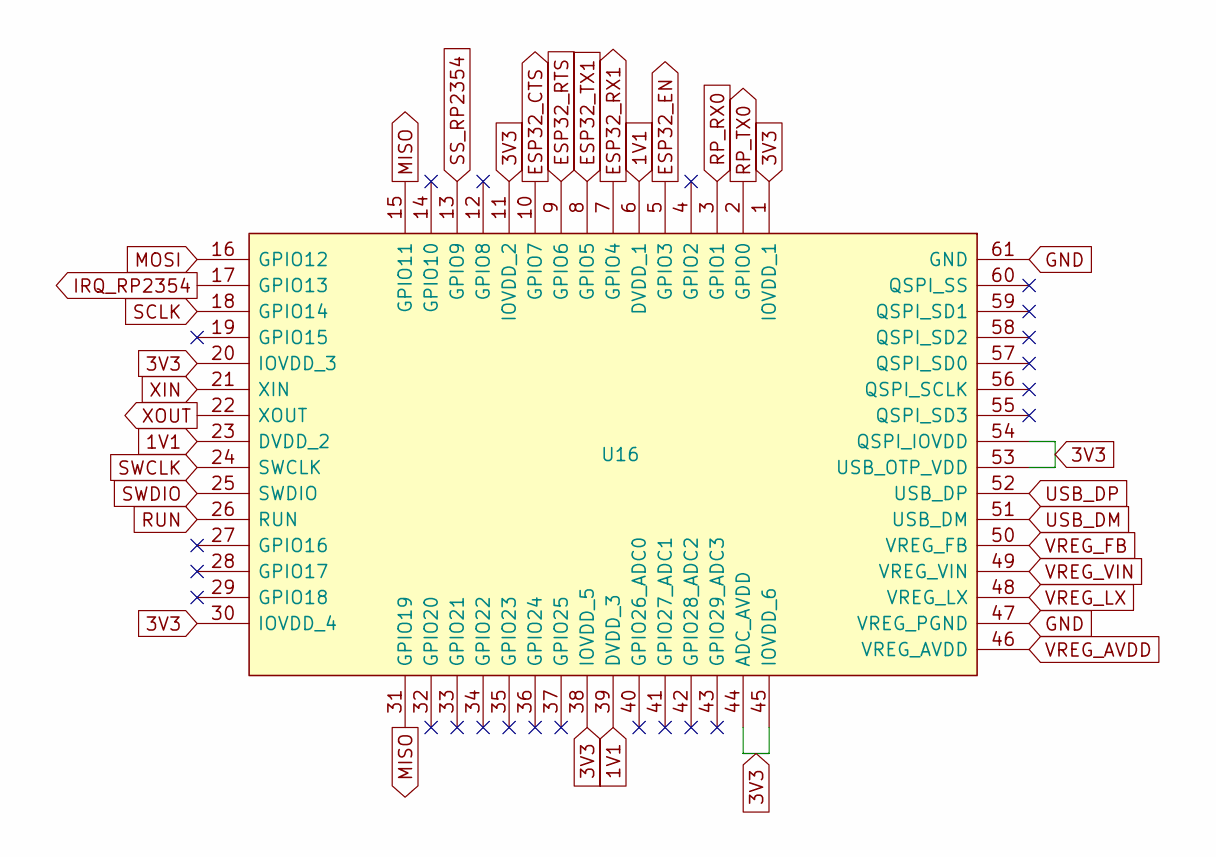
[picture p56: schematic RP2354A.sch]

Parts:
U16: RP2354A; SC150913A4

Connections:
1V1: U16.6 (DVDD_1), U16.23 (DVDD_2), U16.39 (DVDD_3)
3V3: U16.1 (IOVDD_1), U16.11 (IOVDD_2), U16.20 (IOVDD_3), U16.30 (IOVDD_4), U16.38 (IOVDD_5), U16.44 (ADC_AVDD), U16.45 (IOVDD_6), U16.53 (USB_OTP_VDD), U16.54 (QSPI_IOVDD); also elsewhere on the board
ESP32_CTS: U16.10 (GPIO7); also elsewhere on the board
ESP32_EN: U16.5 (GPIO3); also elsewhere on the board
ESP32_RTS: U16.9 (GPIO6); also elsewhere on the board
ESP32_RX1: U16.7 (GPIO4); also elsewhere on the board
ESP32_TX1: U16.8 (GPIO5); also elsewhere on the board
GND: U16.47 (VREG_PGND), U16.61 (GND); also elsewhere on the board
IRQ_RP2354: U16.17 (GPIO13); also elsewhere on the board
MISO: U16.15 (GPIO11), U16.31 (GPIO19); also elsewhere on the board
MOSI: U16.16 (GPIO12); also elsewhere on the board
RP_RX0: U16.3 (GPIO1)
RP_TX0: U16.2 (GPIO0)
RUN: U16.26 (RUN)
SCLK: U16.18 (GPIO14); also elsewhere on the board
SS_RP2354: U16.13 (GPIO9); also elsewhere on the board
SWCLK: U16.24 (SWCLK)
SWDIO: U16.25 (SWDIO)
USB_DM: U16.51 (USB_DM)
USB_DP: U16.52 (USB_DP)
VREG_AVDD: U16.46 (VREG_AVDD)
VREG_FB: U16.50 (VREG_FB)
VREG_LX: U16.48 (VREG_LX)
VREG_VIN: U16.49 (VREG_VIN)
XIN: U16.21 (XIN)
XOUT: U16.22 (XOUT)

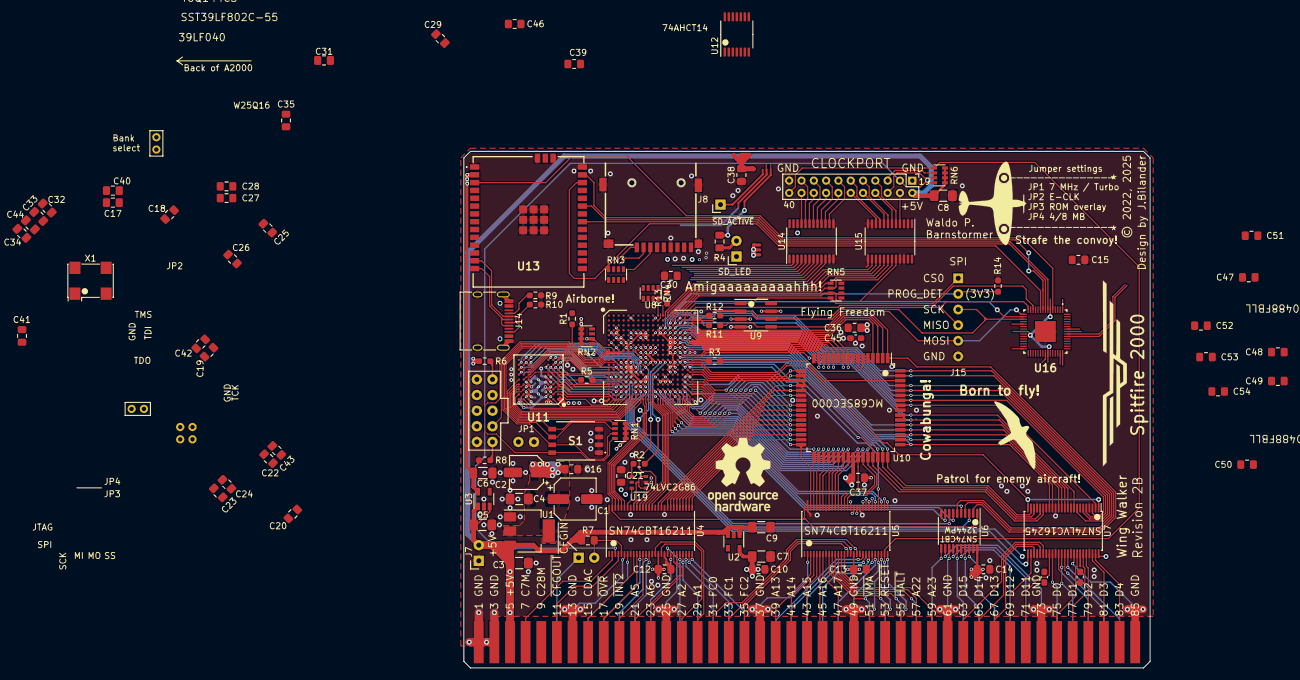
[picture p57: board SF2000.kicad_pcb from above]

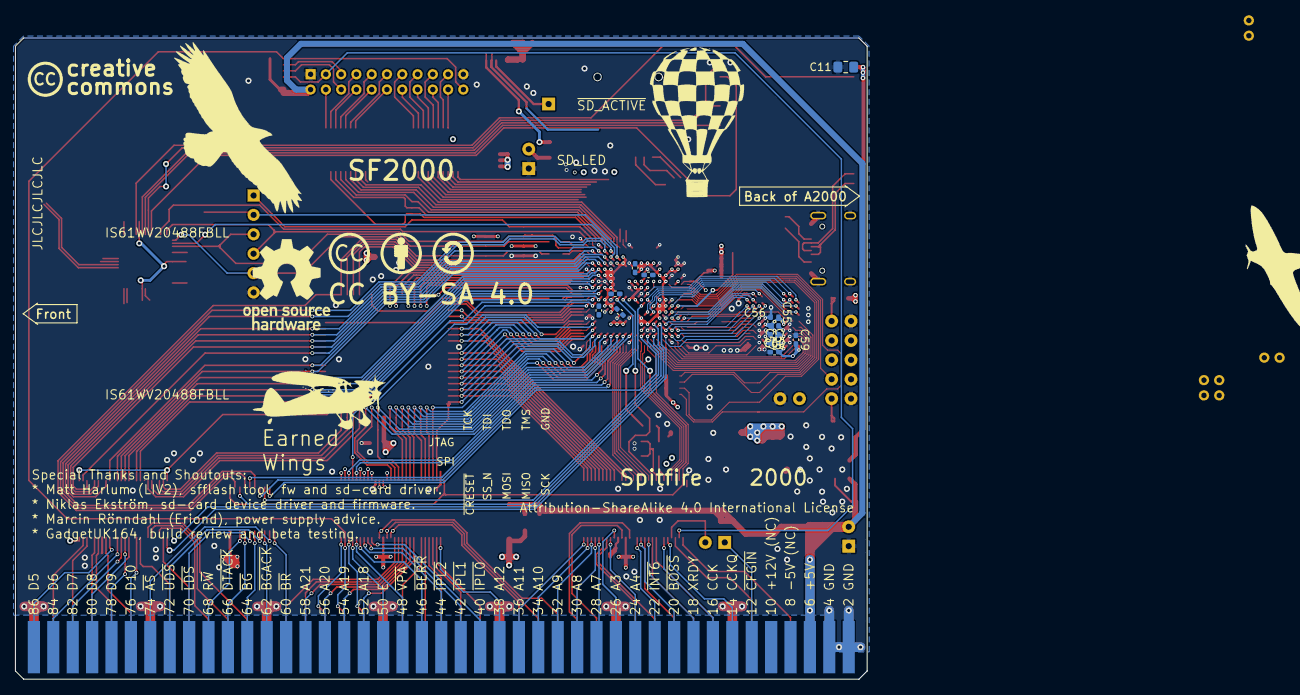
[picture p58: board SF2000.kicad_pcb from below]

Board: 4 copper layers, 111.5 x 83.9 mm, 114 parts (7 on the bottom side), 270 nets.

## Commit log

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2022-01-06 fixed powering and layering, board and clearance settings etc
    [SF2000.kicad_pcb, SF2000.sch]
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2022-01-22 routing and caps fixes
    [SF2000.kicad_pcb, SF2000.sch]
2022-01-23 more routing and caps fixes
    [SF2000.kicad_pcb, SF2000.sch, SF2000_FPGA.sch]
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2022-01-31 added buffering for IDE, rearranged components a bit and did more routing
    [SF2000.kicad_pcb, SF2000.sch, SF2000_CPU_and_RAM.sch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]
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2022-02-03 modified PLCC-32 footprint and did some silkscreen fixes
    [SF2000.kicad_pcb]
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2022-02-09 added Oscillator, pull-up resistor and more routing done
    [SF2000.kicad_pcb, SF2000_FPGA.sch, SF2000_IDE_ROM_and_NOR-flash.sch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]
2022-02-10 more routing and fixing of FPGA pin assignments
    [SF2000.kicad_pcb, SF2000_FPGA.sch, SF2000_IDE_ROM_and_NOR-flash.sch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]
2022-02-12 more routing and fixed pull-up resistors for Flash mem control signals
    [SF2000.kicad_pcb, SF2000_FPGA.sch, SF2000_IDE_ROM_and_NOR-flash.sch]
2022-02-14 more routing, fixed JP6 placement and RN6 + some silkscreen fixes
    [SF2000.kicad_pcb, SF2000_FPGA.sch]
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2022-02-15 Fixed Switch and Jumper enumeration and silkscreen
    [SF2000.kicad_pcb, SF2000_FPGA.sch, SF2000_MicroSD.sch]
2022-02-15 fixed JP6
    [SF2000.kicad_pcb, SF2000_FPGA.sch]
2022-02-15 added ROM_WE signal/pin to FPGA, removed XRDY-signal/pin, and some silkscreen fixes
    [SF2000.kicad_pcb, SF2000_FPGA.sch, SF2000_IDE_ROM_and_NOR-flash.sch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]
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2022-02-15 added decoupling capacitor for Crystal Oscillator (X1), and some silkcreen fixes/labeling
    [SF2000.kicad_pcb, SF2000.sch, SF2000_IDE_ROM_and_NOR-flash.sch]
2022-02-16 added R5,R6 pull-up/down resistors on IDE, added +5V-header for external powering during standalone programming FPGA
    [SF2000.kicad_pcb, SF2000.sch, SF2000_IDE_ROM_and_NOR-flash.sch]
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2022-03-02 fixed labeling/enumeration of caps and resistors, and some silkscreen fixes
    [SF2000.kicad_pcb, SF2000.sch, SF2000_FPGA.sch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]
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2022-03-05 removed INT6_3V3 signal to FPGA and put in JP9 with a pull-up resistor instead
    [SF2000.kicad_pcb, SF2000_FPGA.sch]
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2022-03-21 Silkscreen fixes
    [SF2000.kicad_pcb]
2022-04-07 small silkscreen fix marking +12V and -5V are NC (Not Connected)
    [SF2000.kicad_pcb]
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2022-04-19 Re-routed for a GoWin FPGA GW1N-UV9LQ144 (or GW1N-UV4LQ144) and added a Pmod type 2A SPI-header.
    [SF2000.kicad_pcb, SF2000.sch, SF2000_FPGA.sch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]
2022-04-21 Fixed CLK-pin-assignments to use GCLKT-inputs, CDAC -> 11, C7M -> 23 and OSC_CLK -> 84
    [SF2000.kicad_pcb, SF2000_FPGA.sch]
2022-06-22 changed FLASH_OE to pin 30 and AS_CPU_3V3 to pin 56 (GCLKT_5). Moved D11-D15 one step to the right (now pin 57-61).
    [SF2000.kicad_pcb, SF2000_FPGA.sch]
2022-06-22 Removed RN5 and R10 (ROM_WE) pull-up resistors, using FPGA's built-in pull-ups instead.
    [SF2000.kicad_pcb, SF2000_FPGA.sch, SF2000_IDE_ROM_and_NOR-flash.sch]
2022-06-22 silkscreen fix
    [SF2000.kicad_pcb]
2022-06-29 removed CDAC-signal (not needed) and assigned E-signal to pin 11 (GCLKT_7) instead
    [SF2000.kicad_pcb, SF2000.sch, SF2000_CPU_and_RAM.sch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]
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2022-08-18 Separated BR_3V3, BG_3V3 --> BR_CPU_3V3, BG_CPU_3V3, BR_3V3, BG_3V3 (removed XRDY, INT6 and used those pins for BR_3V3, BG_3V3)
    [SF2000.kicad_pcb, SF2000.sch, SF2000_CPU_and_RAM.sch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]
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2022-08-20 changed to new custom made QFP-64 footprint for the 68SEC000 and re-routed
    [SF2000.kicad_pcb]
2022-08-20 added an external pull-up resistor on RECONFIG_N/SPI_CS (pin 20) because toggling/noise on this pin can cause problem during flashing of embedded flash memory (VLD Down)
    [SF2000.kicad_pcb, SF2000_FPGA.sch]
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2022-08-21 Fixed 39LF040-footprint, elongated pads 0.2mm, easier to solder PLCC32-socket
    [SF2000.kicad_pcb]
2022-08-21 silkcreen fixes Revision 1B
    [SF2000.kicad_pcb]
2022-08-28 small mostly cosmetic fixes for final Revision 1B
    [SF2000.kicad_pcb]
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2023-05-25 Changed U2 value from TPS73643DBV to MIC5205YM5-TR, R2 value from 1.2k to 3k, R1 value from 3k to 1.2k
    [SF2000.kicad_pcb, SF2000.sch]
2023-05-25 Updated schematic with correct U2 values
2025-04-01 Fixed symbol references for LM1117-3.3-Regulator and Oscillator_SG-8002CA, errors that occured when upgrading from KiCad 5.1.6 to 5.1.12
    [SF2000.kicad_pcb, SF2000.sch]
2025-04-01 Replace U8 with T8Q144C3 (Efinix Trion T8 FPGA)
    [SF2000.kicad_pcb, SF2000_FPGA.sch]
2025-04-01 Assign 1.2V to VCC Core and VCCA_xx pins (PLL analog power supply pins)
    [SF2000.kicad_pcb, SF2000_FPGA.sch]
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2025-04-02 Removed Pmod-header in order to make room for crystal oscillator and 1.2V voltage regulator.
    [SF2000.kicad_pcb, SF2000_FPGA.sch]
2025-04-02 Placement of crystal oscillator
    [SF2000.kicad_pcb]
2025-04-02 Change R10 to 33 Ohm and used with crystal oscillator
    [SF2000.kicad_pcb, SF2000_FPGA.sch, SF2000_MicroSD.sch]
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2025-04-03 Assign and route RESET_n line to CLK0
    [SF2000.kicad_pcb, SF2000_FPGA.sch]
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2025-04-05 Fix JP1 and JP2, relocation of FC pins and placement of RN2 pull ups for JTAG, more routing etc
    [SF2000.kicad_pcb, SF2000_FPGA.sch]
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2025-04-05 Routing and repurpose of R2 to be damping resistor for C7M clock line to FPGA
    [SF2000.kicad_pcb, SF2000.sch]
2025-04-06 Reassign C14 to 1.2V and place and route to it, fix of R2 placement and routing
    [SF2000.kicad_pcb, SF2000.sch]
2025-04-06 Routing 1.2V to input power pin 22 (FPGA) from C16, more fixes and routing around C16, rerouting of FC0,FC1 and a lot of other tracks
    [SF2000.kicad_pcb, SF2000.sch]
2025-04-06 More routing and placement of components to accomodate Efinix Trion T8 FPGA
    [SF2000.kicad_pcb, SF2000.sch, SF2000_FPGA.sch]
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2025-04-07 Assign FLASH_WE signal to FPGA pin 74 (GPIOR_158_TEST_N) and to 10k resistor array pin 1 in RN5
    [SF2000.kicad_pcb, SF2000_CPU_and_RAM.sch, SF2000_FPGA.sch]
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2025-04-07 Remove MODE from pull-up resistor RN5 as it can be left floating for 16-bit mode according to MC68000UM
    [SF2000.kicad_pcb, SF2000_CPU_and_RAM.sch]
2025-04-07 swap position between AVEC and CDONE in resistor array RN5 and fix routing of those signals
    [SF2000.kicad_pcb, SF2000_CPU_and_RAM.sch]
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2025-04-07 Swap R1 and R2 references
    [SF2000.kicad_pcb, SF2000.sch, SF2000_FPGA.sch]
2025-04-07 Fixed enumeration of single resistors references in ascending order
    [SF2000.kicad_pcb, SF2000.sch, SF2000_FPGA.sch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]
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2025-04-08 change U2 to ABLIC S-1132B43-M5T1U, change C6 value from 0.33uF to 0.47uF
    [SF2000.kicad_pcb, SF2000.sch]
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2025-04-08 Removed 3x2 jumper header J3, assigned JTAG header to now be J3 instead of JTAG1
    [SF2000.kicad_pcb, SF2000_FPGA.sch]
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2025-04-08 Fix placement and routing of components in 4V3 power supply area
    [SF2000.kicad_pcb, SF2000_FPGA.sch]
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2025-04-09 Remove IDE-header, add Clockport-header, fixed routing of AVEC and FLASH_OE signals and pull-ups
    [SF2000.kicad_pcb, SF2000_CPU_and_RAM.sch, SF2000_FPGA.sch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]
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2025-04-11 Re-route +5V to instead be on the underside and also to supply clockport VCC-pin via a 10uF 1206 capacitor
    [SF2000.kicad_pcb, SF2000_IDE_ROM_and_NOR-flash.sch]
2025-04-11 Adding RN6 pull-up resistor, Routing of A15-A6 to FPGA and more cleanup
    [SF2000.kicad_pcb, SF2000_FPGA.sch, SF2000_IDE_ROM_and_NOR-flash.sch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]
2025-04-11 clockport rework
    [SF2000.kicad_pcb, SF2000_IDE_ROM_and_NOR-flash.sch]
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2025-04-13 Replace 74LVC245A with 74AHCT3G14 for clockport control signals
    [SF2000.kicad_pcb, SF2000_IDE_ROM_and_NOR-flash.sch]
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2025-04-14 Add SD_LED & LED Activity circuit and small fixes and routing around the clockport area
    [SF2000.kicad_pcb, SF2000_FPGA.sch, SF2000_IDE_ROM_and_NOR-flash.sch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]
2025-04-14 More routing and cleanup of old traces, removed old Gowin FPGA symbol and footprint
    [SF2000.kicad_pcb, SF2000_FPGA.sch]
2025-04-15 Fixed routing D0-D7 lines plus some cleanup and routing of power supply to FPGA power pins
    [SF2000.kicad_pcb, SF2000_FPGA.sch, SF2000_MicroSD.sch]
2025-04-15 Fixed driver bank select jumper for ROM at U14, pulled-up by vacant resistor in RN3
    [SF2000.kicad_pcb, SF2000_FPGA.sch, SF2000_IDE_ROM_and_NOR-flash.sch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]
2025-04-15 Swap position of BOSS and INT2 signal in FPGA and level shifters
    [SF2000.kicad_pcb, SF2000.sch, SF2000_FPGA.sch]
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2025-04-15 Add caps for 1.2V voltage regulator and place and route the area
    [SF2000.kicad_pcb, SF2000.sch]
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2025-04-16 Placement of C23 decoupling cap and routing of 1.2V supply to pin 13
    [SF2000.kicad_pcb, SF2000.sch]
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2025-04-17 Routing of 1.2V supply to FPGA pins 125,128,130 via decoupling caps C22, C40
    [SF2000.kicad_pcb, SF2000.sch]
2025-04-17 Routing of 3.3V supply to SD-slot Power pin via decoupling cap C43
    [SF2000.kicad_pcb]
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2025-04-18 Fix of SD-card control signals and routing
    [SF2000.kicad_pcb, SF2000_FPGA.sch, SF2000_IDE_ROM_and_NOR-flash.sch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]
2025-04-18 Replace 74AHCT3G14 with a hex inverter 74AHCT14PW and also simplify and drive the LED circuit from this latter IC.
    [SF2000.kicad_pcb, SF2000_FPGA.sch, SF2000_IDE_ROM_and_NOR-flash.sch]
2025-04-18 Add decoupling cap and route 1.2V power to input pin 73 on FPGA
    [SF2000.kicad_pcb, SF2000.sch]
2025-04-18 Add decoupling cap and route 1.2V power to input pin 96 on FPGA, and some silkscreen text and fixes
    [SF2000.kicad_pcb, SF2000.sch]
2025-04-18 Add decoupling caps and route 3.3V power to input pin 88,91,95 on FPGA
    [SF2000.kicad_pcb, SF2000.sch]
2025-04-19 Add decoupling cap and route 1.2V power to input pin 85 and 96 on FPGA
    [SF2000.kicad_pcb, SF2000.sch]
2025-04-19 Swap references for resistors R8 and R10
    [SF2000.kicad_pcb, SF2000.sch, SF2000_FPGA.sch]
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2025-04-19 Fixed power routing of 1.2V and 3.3V supply to FPGA pins 85,88,91,95 and 96, some re-routing was required
    [SF2000.kicad_pcb]
2025-04-19 Routing of star power on inner layer for 1.2V supply to all 1.2V power input pins on FPGA
    [SF2000.kicad_pcb]
2025-04-19 small routing improvements and silkscreen fixes
    [SF2000.kicad_pcb]
2025-04-20 Fixed references to capacitors in ascending order by size and value
    [SF2000.kicad_pcb, SF2000.sch, SF2000_FPGA.sch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]
2025-04-20 Fix continuous enumeration for voltage regulators and integrated circuits (U1 to U17)
    [SF2000.kicad_pcb, SF2000_CPU_and_RAM.sch, SF2000_FPGA.sch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]
2025-04-20 Fix continuous enumeration for pin-headers (J1 to J12)
    [SF2000.kicad_pcb, SF2000_FPGA.sch, SF2000_IDE_ROM_and_NOR-flash.sch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]
2025-04-20 Small GND fix improvement
    [SF2000.kicad_pcb]
2025-04-20 Change hole size on SD-card footprint from 1.2 mm to 1 mm to better hold and align slot during assembly
    [SF2000.kicad_pcb]
2025-04-20 silkscreen fix orientation labels on the backside
    [SF2000.kicad_pcb]
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2025-04-23 GND vias and Silkscreen fixes, add chip name description for U9 and U12 on silkscreen
    [SF2000.kicad_pcb]
2025-04-23 Replaced U7 (SN74AUP1T87DCKR) with a dual XOR gate (SN74LVC2G86DCUR) and generate 14 MHz by also routing CDAC here
    [SF2000.kicad_pcb, SF2000.sch, SF2000_FPGA.sch]
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2025-05-06 Swap pin assignment for FLASH_OE (pin 72) with ROM_WE (pin 32)
    [SF2000.kicad_pcb, SF2000_FPGA.sch]
2025-05-08 Relocated ROM_OE to pin 80, SD_MISO to pin 81 and SD_CD to 82 to better prepare for 4-bit SDIO should ROM-chip U13 be removed
    [SF2000.kicad_pcb, SF2000_FPGA.sch]
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2025-05-25 Silkscreen fix, spelling of Airborne
    [SF2000.kicad_pcb]
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2025-07-21 Change to 7M clock input instead of C14M from XOR-chip U7, removed CDAC
    [SF2000.kicad_pcb, SF2000.sch, SF2000_FPGA.sch]
2025-07-22 Replace /OVR with /INT2 signal
    [SF2000.kicad_pcb, SF2000.sch, SF2000_FPGA.sch]
2025-07-22 Replace CDAC with /INT6 signal
    [SF2000.kicad_pcb, SF2000.sch]
2025-07-22 Remove SRAM footprints (U16, U17) and repurpose pin 123 (WE_BANK1_EVEN) for /INT6 signal
    [SF2000.kicad_pcb, SF2000_CPU_and_RAM.sch, SF2000_FPGA.sch]
2025-07-24 Reconnect U8 pin 123 from INT6_3V3 to WE_BANK1_EVEN, Reconnect U8 pin 72 from ROM_WE to INT6_3V3
    [SF2000.kicad_pcb, SF2000_FPGA.sch]
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2025-07-26 Change references: C11 to C10, C10 to C9, C9 to C8, C8 to C7, change C11 from value 10uF to 0.1uF, change C11 to size 0805 footprint
    [SF2000.kicad_pcb, SF2000.sch]
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2025-08-02 Silkscreen fixes and bumping revision to 2B
    [SF2000.kicad_pcb]
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2026-09-07 Begin redesign Rev 3, isolate bus better, remove one SN74CBT16211 and replace with one SN74CBT3244PW and one SN74LVC16245ADGGR
    [SF2000.kicad_pcb, SF2000.sch]
2026-09-15 Start major redesign, remove U11 (SST39LF802C), remove U13 (SST39LF040), replaced U8 (T8Q144C3) with 10M02SCU324C8G, replaced U7 (74LVC2G86) with 74LVC1G57GV, adding SDRAM in BGA54 (IM1216SDBABG-6I)
    [SF2000.kicad_pcb, SF2000.sch, SF2000_CPU_and_RAM.sch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]
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2026-09-26 Replace TLV74312PDBV with TLV75533PDBVR (3.3V) and make it a supply to ESP32-C5 module (3V3_C5) only. Fixed external pull-up resistor network for 4-way dip switch signals. Rearranged JTAG TDI and TCK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
    [ESP32-C5-WROOM.sch, SF2000.kicad_pcb, SF2000.sch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]
2026-09-26 Add 3V3 filled zone and fix some 1206 10uF capacitor enumeration
    [SF2000.kicad_pcb, SF2000.sch]
2026-09-26 Fix pin assignment and routing of D12-D15 to U7 (SN74LVC16245ADGGR) and to U10 (CPU MC68SEC000)
    [SF2000.kicad_pcb, SF2000.sch]
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2026-09-29 swap R9,R10 designators
    [ESP32-C5-WROOM.sch]
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2026-10-13 Remove 7x5mm crystal oscillator and add 5x3.2 mm crystal oscillator
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2026-10-22 Route track for BT3 (ESP32-C5 BOOT button) and fix layout around the SD_LED and SD_ACTIVE headers
2026-10-22 Add BT4 push-button for RESET on the EN-signal for the ESP32-C5
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2026-10-24 Fix silkscreen placement for C55-C60 (underside of U11)
2026-10-26 Breakout UART0 (TX0,RX0) for the ESP32-C5 odule and put SMD pads on the underside for debugging purposes, Change C47 value from 0.01uF to 0.1uF, Swap position of C37 and C48.
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2026-10-31 Fix silkscreen art on underside
2026-11-01 small silkscreen fix on underside
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

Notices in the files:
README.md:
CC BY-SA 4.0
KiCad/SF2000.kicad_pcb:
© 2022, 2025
